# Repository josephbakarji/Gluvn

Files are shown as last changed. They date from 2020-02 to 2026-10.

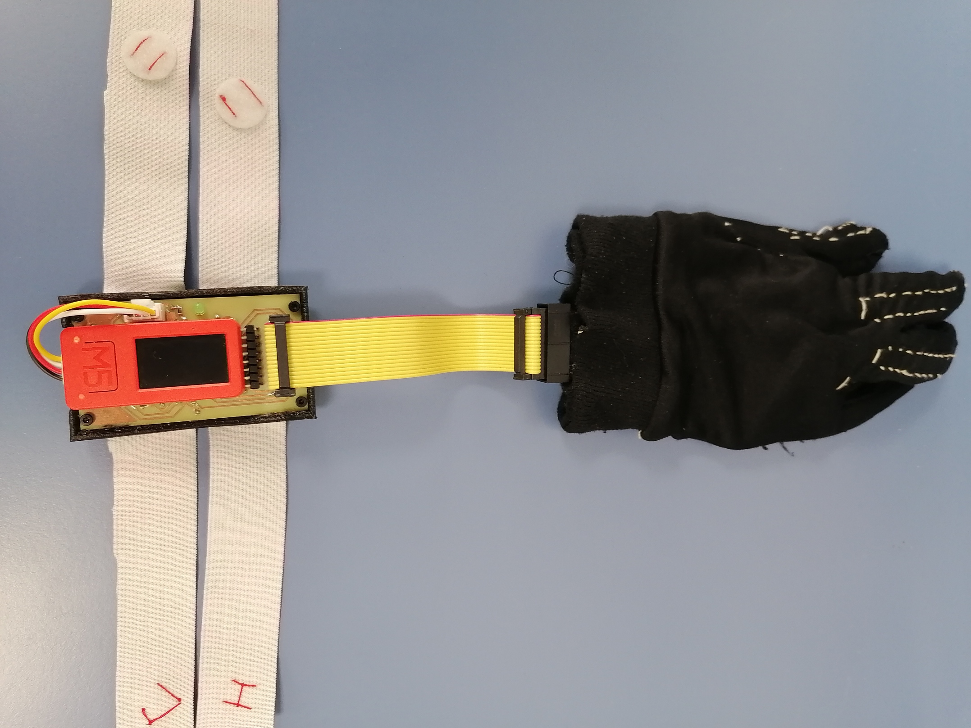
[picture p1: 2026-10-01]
hardware/images/Full setup/Full_assembly.jpg

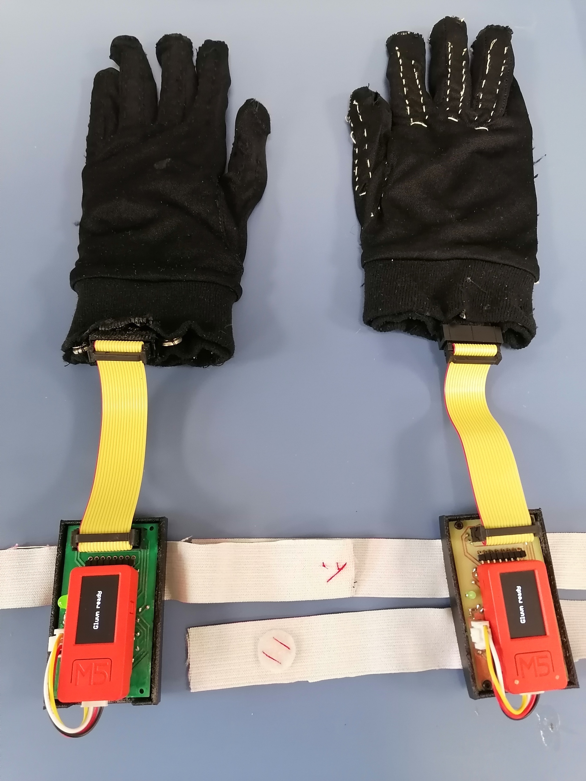
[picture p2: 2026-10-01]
hardware/images/Full setup/Both hands.jpg

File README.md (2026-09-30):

# 🎼 M5-GLUVN - Wireless Digital Musical Glove System

The next evolution of GLUVN: **wireless, portable, and powered by M5Stick C Plus 1.1**

**✨ NEW**: This is the **M5-GLUVN** project—a complete redesign of the original GLUVN with wireless BLE connectivity, built-in IMU, and a custom PCB with multiplexer support. For the original Arduino-based USB version, see [docs/README_WIRED.md](docs/README_WIRED.md).

## 📋 Project Overview

**M5-GLUVN** transforms hand movements and finger gestures into wireless MIDI music. Improvements over the original:

### What's New in M5-GLUVN
- 🔋 **Wireless via Bluetooth Low Energy (BLE)** - Play untethered
- 🎯 **M5Stick C Plus 1.1 Microcontroller** - Compact, built-in IMU
- 📡 **Custom Multiplexer PCB** - CD4067 multiplexer enables reading all 10 sensors from limited ports
- ⚡ **Built-in IMU** - M5Stick's BMI270/MPU6886 for volume and pitch control (no external IMU needed)
- 🔧 **Custom Electronics** - Optimized capacitors/resistors for better sensor accuracy
- 📊 **Dual Connectivity** - BLE wireless + USB fallback for development/charging
- 🎮 **Bandwidth Optimized** - Efficient binary frames for wireless transmission
- 📱 **Real-time Calibration** - BLE-based calibration tool for on-the-fly adjustments

## 🏗️ Hardware Architecture

### Microcontroller
- **M5Stick C Plus 1.1** - Compact ESP32-based device with:
  - Built-in 6-DOF IMU (BMI270 or MPU6886)
  - 12-bit ADC (4096 levels) for sensor reading
  - BLE and WiFi capabilities
  - 120 mAh battery for portable play
  - USB-C for charging and serial communication

### Sensor Configuration

**Left Hand Sensors** (5x per sensor type):
- 5x Flex Sensors (finger bending)
- 5x FSR/Pressure Sensors (finger force)

**Right Hand Sensors** (5x per sensor type):
- 5x Flex Sensors (finger bending)
- 5x FSR/Pressure Sensors (finger force)

**IMU** (built-in to M5Stick):
- 3-axis Accelerometer (default for volume control)
- 3-axis Gyroscope (optional for pitch bend)
- Selectable for different modulation modes

### Custom PCB with CD4067 Multiplexer

**Problem Solved**: M5Stick has limited analog input ports (~3), but we need to read 10 sensors (5 flex + 5 FSR) per hand.

**Solution**: CD4067 16-channel analog multiplexer handles sensor switching:

```
CD4067 Multiplexer Configuration:
├─ CH0-4   → 5x FSR Sensors (10K pull-down, 10nF cap)
├─ CH5-9   → 5x Flex Sensors (47K pull-down, 100nF cap)
├─ CH10-14 → Unused
├─ CH15    → Ground/Reference
└─ MUX Control: 4 GPIO pins (S0-S3) select active channel

PCB Features:
├─ Separate filter networks for flex vs FSR
│  ├─ Flex: 47K + 100nF (slower response)
│  └─ FSR: 10K + 10nF (faster response)
├─ Multiplexer settling time: 1000µs
└─ Binary serial protocol for efficient data transmission
```

**Wire Connections**:
- MUX_SIG → GPIO36 (ADC0)
- MUX_S0 → GPIO26
- MUX_S1 → GPIO32
- MUX_S2 → GPIO33
- MUX_S3 → GPIO0

## 📁 Project Structure

```
Wireless-Gluvn/
├── README.md                              # Project overview and setup guidance
├── firmware/
│   └── m5stick_firmware/
│       ├── m5stick_firmware.ino          # Main M5Stick firmware
│       ├── calibration.h                 # Calibration constants and sensor mapping
│       ├── Diagnostics.h                 # Runtime diagnostics helpers
│       ├── MahonyAHRS.h                  # AHRS orientation filter
│       └── NavEKF.h                      # Navigation / attitude estimator
│
├── software_python/
│   ├── apps/
│   │   ├── app_10fig_accel.py            # 10-finger instrument with accel-based volume
│   │   ├── app_10fig_inst_Flex.py       # Flex-only instrument app
│   │   ├── app_10fig_inst_FSR.py        # FSR/pressure instrument app
│   │   ├── app_10fig_pitch.py           # Pitch modulation app
│   │   ├── app_continuous_gesture.py    # Continuous gesture-to-MIDI surface
│   │   ├── app_harmonizer.py            # Harmonic / chord-oriented app
│   │   ├── app_jacob_choir.py           # Choir-like multi-voice performance app
│   │   ├── app_moving_window_accel.py  # Moving-window instrument with accel modulation
│   │   ├── app_moving_window_flex.py   # Moving-window flex-driven app
│   │   ├── app_moving_window_flex_press.py
│   │   └── examples/
│   │       └── README.md                # Example GUI walkthroughs and launch patterns
│   ├── core/
│   │   ├── app_core.py                  # Shared app runtime and sensor processing
│   │   ├── base_config.py               # Base configuration and constants
│   │   ├── data_analysis.py             # Data persistence and analysis utilities
│   │   ├── midi_writer.py               # MIDI output layer
│   │   ├── note_mapper.py               # Scale and note mapping logic
│   │   ├── port_read.py                 # Serial/BLE reader and parser
│   │   └── pose_provider.py             # Pose / sensor abstraction layer
│   ├── strategies/
│   │   ├── base_strategies.py           # Strategy base classes
│   │   ├── dual_hand_coupling.py        # Coupled dual-hand control logic
│   │   ├── energy_excitation.py         # Energy / excitation mapping
│   │   ├── kinematics.py                # Kinematic transforms and motion logic
│   │   ├── mapping_strategies.py        # Note mapping strategies
│   │   ├── modulation_strategies.py    # Modulation control strategies
│   │   ├── tilt_surface.py              # Tilt-surface interaction model
│   │   └── trigger_strategies.py        # Trigger logic and gating
│   ├── ui/
│   │   ├── digital_twin.py              # Live motion visualization
│   │   ├── finger_widgets.py            # Finger-state widgets
│   │   ├── piano_keyboard.py            # MIDI keyboard-like UI
│   │   └── sensor_threads.py            # Sensor-thread UI helpers
│   ├── tests/
│   │   ├── test_hands_MP.py             # Hand-processing checks
│   │   ├── test_nav_quat_pipeline.py    # Navigation/quaternion pipeline tests
│   │   ├── test_pose_provider.py        # Pose-provider validation
│   │   └── test_trigger_strategies.py   # Trigger-strategy unit tests
│   ├── tools/
│   │   ├── benchmark_bandwidth.py       # BLE/serial bandwidth diagnostics
│   │   ├── calibrate_eeprom.py          # Calibration helper
│   │   ├── debug_sensors.py             # Live sensor debugging
│   │   ├── plot_sensors.py              # Sensor plotting utilities
│   │   ├── sens_FFT.py                  # FFT analysis utilities
│   │   └── sens_times_series.py         # Time-series inspection tools
│   ├── legacy/
│   │   └── ...                          # Older prototypes and experimental code
│   ├── data/
│   │   └── ...                          # Calibration and experiment data
│   ├── figures/
│   │   └── ...                          # Generated plots and visuals
│   ├── pyproject.toml                  # Python package metadata
│   └── __init__.py                     # Package marker
│
├── docs/
│   ├── README_WIRED.md                 # Original USB/wired hardware reference
│   ├── Datasheets/                     # Sensor and board datasheets
│   ├── Notes/                          # Design notes, success docs, and setup guides
│   └── *.pdf                           # Architecture and hardware reference docs
└── .gitignore
```

## 🚀 Quick Start - M5-GLUVN

### Prerequisites
- **M5Stick C Plus 1.1** device
- **Custom PCB** with CD4067 multiplexer
- **10 Flex Sensors** + **10 FSR/Pressure Sensors**
- **Python 3.7+**
- **Arduino IDE** for firmware

### Step 1: Upload M5 Firmware

```bash
# Using Arduino IDE:
# 1. Install M5Unified library
# 2. Install ESP32 board support
# 3. Open: firmware/m5stick_firmware/m5stick_firmware.ino
# 4. Board: M5Stack-Core2 (or M5Stick C Plus)
# 5. Upload

```

**Verify firmware**:
```bash
# Connect M5 to USB, check serial output:
# Should show: "M5Unified init success", "BLE init success"
```

### Step 2: Install Python Dependencies

```bash
cd software_python

# Install the project in editable mode
pip install -e .

# Install runtime dependencies used by the apps
pip install numpy scipy PyQt5 bleak

# Test BLE functionality
python -c "from bleak import BleakScanner; print('✅ BLE working')"
```

### Step 3: Calibrate with BLE

```bash
# Make sure the M5Stick is powered on and near the host computer
cd software_python/tools
python calibrate_eeprom.py
```

**What to do**:
1. Select hand (L or R) in the calibration flow
2. Sweep each finger through its full flex range and relax back to neutral
3. Apply light and then strong pressure on the FSR channels
4. Save the calibration values for use by the live sensor pipeline

### Step 4: Run the Application

```bash
cd software_python

# Example apps that match the current repository structure
python apps/app_harmonizer.py
python apps/app_continuous_gesture.py

# Performance / diagnostics utilities
python tools/benchmark_bandwidth.py
```

## 🔌 Wiring & PCB Assembly

### Sensor Connections to CD4067

```
Flex Sensors (CH5-9):
  Flex_L0 → MUX_CH5
  Flex_L1 → MUX_CH6
  Flex_L2 → MUX_CH7
  Flex_L3 → MUX_CH8
  Flex_L4 → MUX_CH9

FSR/Pressure (CH0-4):
  FSR_L0 → MUX_CH0
  FSR_L1 → MUX_CH1
  FSR_L2 → MUX_CH2
  FSR_L3 → MUX_CH3
  FSR_L4 → MUX_CH4
```

### Filter Components

**For Flex Sensors**:
- Pull-down: 47kΩ resistor
- Capacitor: 100nF
- Time constant: RC = 47k × 100n = 4.7ms

**For FSR/Pressure**:
- Pull-down: 10kΩ resistor
- Capacitor: 10nF
- Time constant: RC = 10k × 10n = 100µs

## 📊 Communication Protocols

### BLE Protocol (Wireless)

**Nordic UART Service (NUS)**:
```
Service UUID:  6E400001-B5A3-F393-E0A9-E50E24DCCA9E
RX Char UUID:  6E400002-B5A3-F393-E0A9-E50E24DCCA9E (write)
TX Char UUID:  6E400003-B5A3-F393-E0A9-E50E24DCCA9E (notify)
```

**Binary Frame Format** (25 bytes):
```
[0]     = Hand ('R' or 'L')
[1]     = Sequence number (0-255)
[2-3]   = Yaw (uint16 big-endian)
[4-5]   = Pitch (uint16)
[6-7]   = Roll (uint16)
[8-9]   = IMU0 (accel_x or gyro_x)
[10-11] = IMU1 (accel_y or gyro_y)
[12-13] = IMU2 (accel_z or gyro_z)
[14-18] = Flex sensors [0-4] (5 bytes, calibrated 0-255)
[19-23] = FSR sensors [0-4] (5 bytes, calibrated 0-255)
[24]    = '\n' (frame terminator)
```

**Bitrate**: ~100 Hz × 25 bytes × 8 bits = **20 kbps** (well within BLE 1 Mbps limit)

### USB Serial Fallback

Same binary protocol as original GLUVN, available on USB-C port for:
- Development and debugging
- Firmware uploading
- Charging while playing

## 📖 Documentation

- **[docs/README_WIRED.md](docs/README_WIRED.md)** - Original wired USB reference and hardware notes
- **[docs/Notes/GETTING_STARTED.md](docs/Notes/GETTING_STARTED.md)** - Setup and workflow guidance
- **[docs/Notes/CLEAN_ARCHITECTURE_SUCCESS.md](docs/Notes/CLEAN_ARCHITECTURE_SUCCESS.md)** - Architecture and design history
- **[docs/Notes/USER_CONFIGURABLE_PARAMETERS.md](docs/Notes/USER_CONFIGURABLE_PARAMETERS.md)** - Tuning and parameter reference
- **[software_python/apps/examples/README.md](software_python/apps/examples/README.md)** - Current app examples and GUI usage

### Technical Design Notes

The project also includes technical reference material covering the embedded firmware and host software stack:

- Firmware documentation covering calibration strategy, embedded diagnostics, protocol framing, and wireless telemetry behavior
- Software documentation covering transport parsing, pose interpretation, note mapping, app logic, and MIDI output
- Packet-loss and bandwidth analysis for BLE/USB performance validation and real-time reliability checks

These notes should be kept alongside the source tree and are useful when reviewing system behavior, debugging signal quality, or preparing implementation reports.

## 🔧 Configuration & Tuning

### Musical Settings (same as original)

```
Default Note Layout (C Major):
Left Hand:          Right Hand:
Thumb:  G2 (55)     Thumb:  C4 (60) ← Middle C
Index:  A2 (57)     Index:  D4 (62)
Middle: B2 (59)     Middle: E4 (64)
Ring:   C3 (52)     Ring:   F4 (65)
Pinky:  D3 (53)     Pinky:  G4 (67)

Supported Scales:
- Major (bright)
- Minor (dark)
- Pentatonic (improvisation-friendly)
```

## 🐛 Troubleshooting

### BLE Connection Issues

**Problem**: M5Stick not discovered
```bash
# 1. Check M5 is powered on and firmware uploaded
# 2. Restart M5 by pressing side button
# 3. Check BLE name in __init__.py matches device

# If still not found:
python -c "from bleak import BleakScanner; asyncio.run(BleakScanner.discover())"
```

**Problem**: BLE connects but no data flowing
```bash
# 1. Check calibration was saved: 
#    - M5 should display "CAL: OK" on startup
# 2. Send "STATUS" command via BLE
# 3. Verify binary format matches struct definition
```

### Sensor Reading Issues

**Problem**: Some sensor channels read 0
```bash
# Check MUX channel selection
# Verify wiring to CD4067 inputs
# Test with a live raw-sensor check from the project test utilities:
cd software_python
python tests/testfiles/simple_sensor_test.py
```

### Performance Issues

**Problem**: BLE drops packets
```bash
# Check battery level (low battery = weak signal)
# Move closer to computer (typical range 5-10m indoors)
# Check for WiFi interference on 2.4 GHz
# Reduce GUI update rate in examples
```

**Problem**: High latency (>100ms)
```bash
# Disable debug printing (set print_mode=0 in firmware)
# Switch to lower latency GUI mode
# Reduce PyQt5 update rate to 50 Hz
```

## 🔄 Comparison with Original GLUVN

| Feature | Original | M5-GLUVN |
|---|---|---|
| **Microcontroller** | Arduino (Micro) | M5Stick C Plus 1.1 |
| **Connectivity** | USB Serial | BLE + USB fallback |
| **IMU** | External (separate) | Built-in (BMI270) |
| **ADC Resolution** | 10-bit | 12-bit |
| **Sensor Reading** | Direct GPIO | CD4067 Multiplexer |
| **Portability** | Tethered | Wireless (4-6h battery) |

## 📝 License

MIT License - Same as original GLUVN

---

**🎵 M5-GLUVN: The future of portable, wireless musical expression**

*Transform your hand into a wireless musical instrument.*

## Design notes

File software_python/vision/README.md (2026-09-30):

# MediaPipe/world alignment prototype

This is an experimental external tool. It does not modify or call an EKF update.
The current experiment is fixed-camera: the camera remains stationary while we
inspect the relationship between MediaPipe landmarks, a chosen source-frame
representation, and the existing EKF world frame. Dynamic camera pose
estimation and measurement fusion are deliberately out of scope.

## Coordinate conventions

- **MediaPipe image landmarks:** `x` increases right, `y` increases down, and `z` is relative depth (more negative is generally closer to the camera). `x` and `y` are normalized by image width/height; this is not metric 3-D camera position and is never treated as metres by this prototype. The tracker preserves all 21 landmarks and a wall-clock timestamp.
- **MediaPipe WorldLandmarks:** when enabled, MediaPipe supplies approximately metric 3-D hand-local coordinates in metres. Their origin is near the hand's geometric centre, so they are not an absolute camera pose or camera-fixed translation. They are the preferred source for the current 3-D hand-geometry experiment, but any fitted transform must be labelled `hand_local_to_ekf`, not `camera_to_ekf`.
- **Firmware sensor frame:** the raw MPU6886/M5Unified accelerometer and gyroscope axes are the sensor/body axes after firmware calibration. The repository does not expose a separate physical axis-remapping matrix, so no undocumented sign flip is applied here.
- **NavEKF/world frame:** `NavEKF` stores position in metres and publishes a quaternion through `getQuaternion()` / the `NAV_QUAT_STREAM_ON` telemetry block. The quaternion is `(w,x,y,z)` and represents world-from-sensor; its DCM maps sensor vectors into the EKF world. The world frame is initialized from the first stationary Mahony attitude when the EKF arms. Because yaw has no magnetometer reference, its absolute heading is session/setup dependent. The EKF uses a world +Z gravity convention, as shown by its gravity subtraction in `NavEKF.h`.
- **Euler angles:** firmware display angles are encoded yaw/pitch/roll, and the existing Python helper interprets them as intrinsic `ZYX`. The alignment prototype uses the quaternion, not Euler angles.

## Transformation and calibration

The prototype uses the explicit similarity transform only when the source
coordinates justify that model:

`p_world = scale * R_world_camera @ p_camera + t_world_camera`.

`R_world_camera` is a camera-to-EKF rotation only if `p_camera` is genuinely
camera-fixed metric data. For current MediaPipe WorldLandmarks, it is instead a
source-to-EKF registration between hand-local coordinates and the EKF frame;
the hand-local origin means it cannot provide absolute wrist translation by
itself. For normalized image landmarks, the transformed result is explicitly
visualization coordinates only and has no physical metre interpretation.

Start with identity only when the source axes and EKF/world axes are deliberately
co-located. For a reproducible calibration, collect at least three non-
collinear corresponding points in both frames and run `fit_similarity()`. The
SVD fit returns a proper rotation, positive scale, and translation.

A practical first experiment is: keep the camera fixed, start the EKF so it
arms, keep the glove orientation approximately constant, and perform controlled
left/right, forward/back, and up/down motions. With WorldLandmarks, inspect hand
shape/orientation consistency and do not interpret the hand-local wrist as
absolute camera translation. With a separately calibrated camera-fixed metric
source, inspect absolute translation against EKF position. The output is a
frame-consistency check, not absolute camera localization.

For paired calibration samples in a CSV with `camera_x/y/z` and `world_x/y/z` columns, fit the transform with:

`python -m vision.calibrate_alignment points.csv vision/calibration.json`

## Running

Install the optional experiment dependencies in the active environment:

`pip install mediapipe opencv-python matplotlib numpy`

From `software_python`:

Camera-only, preferred 3-D hand-local source:

`python -m vision.run_alignment --source world --no-ekf --camera 0 --calibration vision/hand_local_to_ekf.json --log vision/camera_only.csv --show`

Live MediaPipe plus existing glove telemetry:

`python -m vision.run_alignment --source world --hand r --camera 0 --calibration vision/hand_local_to_ekf.json --log vision/live_alignment.csv --show`

Use `--source image` for normalized image landmarks. The logger marks these as
`image_normalized`, and the configured scale is only a visualization scale.
Use `--source world` (or the legacy `--world-landmarks` flag) for MediaPipe
WorldLandmarks, marked `world_metric_hand_local`.

Recorded-data visualization, with no camera, glove, or MediaPipe:

`python -m vision.replay_alignment vision/live_alignment.csv --frame -1 --plot-offset`

Each CSV row preserves the MediaPipe PC timestamp, PC telemetry receipt time,
the parser-relative timestamp, raw `device_us`, an unwrapped device-clock
estimate, and the paired MediaPipe-PC-minus-device offset. The log also keeps
the PC-receipt-minus-device diagnostic. The offset plot describes the observed
clock relationship plus capture/transport timing; it does not establish
synchronization.

The bridge enables `NAV_QUAT_STREAM_ON` and `MOTION_STREAM_ON` through the existing `Reader`/`ParseSerial` path. It reads `nav_quat`, `position`, `nav_armed`, and `device_us`; it never sends MediaPipe data back to the firmware, injects a measurement, or modifies `NavEKF.h`.

## Limitations / next step

Camera pose is fixed and offline. There is no dynamic camera pose estimation,
absolute camera pose, hand-to-glove registration, solved time synchronization,
or EKF measurement update. Before using MediaPipe as a future measurement,
validate the rigid registration, source origin, scale, latency, quaternion
convention, and the `nav_armed`/ZUPT quality gates over recorded controlled
movements.

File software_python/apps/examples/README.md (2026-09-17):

# GLUVN Ten Finger GUI Applications

This directory contains GUI applications for testing and using the GLUVN ten finger trigger system with visual feedback.

## Applications

### 1. `ten_finger_demo.py` - Demo Version (tkinter)
**No hardware required** - Perfect for testing the interface and functionality.

**Features:**
- Simulated sensor data with realistic patterns
- Click-to-trigger finger lights for manual testing
- Auto demo sequences showing different patterns
- All configuration options functional
- MIDI output (if MIDI device available)

**Usage:**
```bash
cd gluvn_python/examples
python ten_finger_demo.py
```

### 2. `ten_finger_demo_pyqt.py` - Demo Version (PyQt5) ⭐ **Recommended**
**No hardware required** - PyQt5 version matching existing sensor plotting applications.

**Features:**
- Same functionality as tkinter demo
- PyQt5 interface consistent with other GLUVN tools
- Better performance and visual appearance
- Professional look and feel

**Usage:**
```bash
cd gluvn_python/examples
python ten_finger_demo_pyqt.py
```

### 3. `ten_finger_gui.py` - Hardware Version (tkinter)
**Requires GLUVN hardware** - For use with actual sensor gloves.

**Features:**
- Real-time sensor data processing
- Live trigger visualization
- MIDI note output
- Configurable thresholds and musical settings

**Usage:**
```bash
cd gluvn_python/examples
python ten_finger_gui.py
```

### 4. `ten_finger_gui_pyqt.py` - Hardware Version (PyQt5) ⭐ **Recommended**
**Requires GLUVN hardware** - PyQt5 version for use with actual sensor gloves.

**Features:**
- Same functionality as tkinter hardware version
- PyQt5 interface consistent with other GLUVN tools
- Better error handling and user feedback
- Professional appearance

**Usage:**
```bash
cd gluvn_python/examples
python ten_finger_gui_pyqt.py
```

## Recommended Workflow

### For Testing (No Hardware)
1. **Start with PyQt5 demo**: `python ten_finger_demo_pyqt.py`
2. **Alternative**: `python ten_finger_demo.py` (if PyQt5 issues)

### For Hardware Use
1. **Use PyQt5 version**: `python ten_finger_gui_pyqt.py`
2. **Alternative**: `python ten_finger_gui.py` (if PyQt5 issues)

## GUI Interface

### Main Display
- **10 Finger Lights**: Visual indicators for each finger (5 per hand)
  - 🔴 Dark Red: Finger not triggered
  - 🟢 Green: Finger triggered
- **Note Names**: Shows which MIDI note each finger will play
- **Hand Labels**: Left Hand and Right Hand sections

### Control Panel

#### Buttons
- **Start Demo/Sensors**: Begin processing sensor data
- **Stop Demo/Sensors**: Stop processing and reset all lights
- **Auto Demo**: Run automated demonstration sequences (demo versions only)

#### Configuration Options
- **Threshold**: Sensor value threshold for triggering (50-500)
  - Higher values = need more finger bend to trigger
  - Lower values = more sensitive triggering
- **Hysteresis**: Noise reduction factor (1-50)
  - Higher values = more stable triggering, less sensitive to noise
  - Lower values = more responsive but may have false triggers
- **Scale**: Musical scale selection
  - Major, Minor, Pentatonic
- **Root Note**: Base note for the scale
  - C, C#, D, D#, E, F, F#, G, G#, A, A#, B

### Status Bar
Shows current system status and recent actions.

## Getting Started

### 1. Start with the PyQt5 Demo
```bash
cd gluvn_python/examples
python ten_finger_demo_pyqt.py
```

1. Click "Start Demo" to begin processing
2. Click on individual finger lights to trigger them manually
3. Try the "Auto Demo" button to see automated sequences
4. Experiment with different threshold and scale settings

### 2. Test with Hardware (if available)
```bash
cd gluvn_python/examples
python ten_finger_gui_pyqt.py
```

1. Ensure your GLUVN hardware is connected
2. Click "Start Sensors" to begin reading from hardware
3. Move your fingers to trigger the sensors
4. Watch the lights respond to your finger movements

## Configuration Guide

### Optimal Threshold Settings
- **Flex Sensors**: Start with 200, adjust based on your sensor calibration
  - If lights don't trigger: Lower the threshold (150-180)
  - If lights trigger too easily: Raise the threshold (220-300)

### Hysteresis Settings
- **Start with 10-15** for most applications
- **Increase if you see flickering**: Higher hysteresis reduces noise
- **Decrease for faster response**: Lower hysteresis for quick triggering

### Musical Settings
- **C Major**: Good default for testing (all white keys)
- **A Minor**: Natural minor scale starting on A
- **Pentatonic**: 5-note scale, sounds good in any combination

## Troubleshooting

### Demo Versions
**Problem**: Demo doesn't start
- **Solution**: Check that all dependencies are installed
- **Check**: Python 3.7+ with tkinter/PyQt5, numpy

**Problem**: No MIDI output
- **Solution**: Install MIDI software or connect MIDI device
- **Note**: Visual feedback will still work without MIDI

### Hardware Versions
**Problem**: "Sensor reader not available" error
- **Solution**: 
  1. Check hardware connection (USB/serial)
  2. Verify `port_read.py` can access your device
  3. Check device permissions on Linux/Mac

**Problem**: Lights don't respond to finger movement
- **Solution**:
  1. Adjust threshold values (try 150-250 range)
  2. Check sensor calibration
  3. Verify flex sensors are working properly

**Problem**: Lights flicker or trigger randomly
- **Solution**:
  1. Increase hysteresis value (15-25)
  2. Check for loose sensor connections
  3. Reduce electrical noise in environment

## Technical Details

### Sensor Processing Pipeline
```
Sensor → Trigger Strategy → Mapping Strategy → MIDI Output
                ↓
           Visual Display
```

### Key Classes
- **`HysteresisTrigger`**: Processes sensor data with threshold and hysteresis
- **`BasicMapper`**: Maps finger triggers to musical notes
- **`FingerLight`**: Visual representation of finger state
- **`TenFingerGUI/Demo`**: Main application classes

### Default Note Mappings
**Left Hand** (C Major):
- Thumb: G2, Index: A2, Middle: B2, Ring: C3, Pinky: D3

**Right Hand** (C Major):
- Thumb: E3, Index: F3, Middle: G3, Ring: A3, Pinky: B3

## Advanced Usage

### Custom Configuration
You can modify the default settings by editing the configuration in the code:

```python
# Example: Custom threshold settings
self.trigger_config = {
    'thresholds': {'flex': 180},    # Lower threshold
    'hysteresis': {'flex': 15},     # Higher hysteresis
    'trigger_sensors': {'l': 'flex', 'r': 'flex'}
}
```

### Adding New Scales
To add custom scales, modify the `mapper.py` file:

```python
scales = {
    'major': [2, 2, 1, 2, 2, 2, 1],
    'minor': [2, 1, 2, 2, 1, 2, 2],
    'your_scale': [2, 1, 3, 1, 2, 2, 1]  # Your custom intervals
}
```

## Framework Comparison

### PyQt5 Versions (Recommended)
- **Pros**: Consistent with existing GLUVN tools, better performance, professional appearance
- **Cons**: Requires PyQt5 installation
- **Best for**: Production use, integration with other GLUVN applications

### tkinter Versions
- **Pros**: Built into Python, no additional dependencies
- **Cons**: Less polished appearance, different from other GLUVN tools
- **Best for**: Quick testing, systems without PyQt5

## Next Steps

1. **Test the PyQt5 demo version** to understand the interface
2. **Try different musical settings** to find your preferred sound
3. **Connect your hardware** and test with real sensors
4. **Experiment with threshold values** to optimize for your setup
5. **Explore the codebase** to understand the architecture

## Support

For issues or questions:
1. Check the troubleshooting section above
2. Review the main GLUVN documentation
3. Check the test suite in `gluvn_python/tests/`
4. Look at the implementation in `core/strategies/`

## Files in this Directory

- `ten_finger_demo_pyqt.py` - **PyQt5 demo version (recommended)**
- `ten_finger_gui_pyqt.py` - **PyQt5 hardware version (recommended)**
- `ten_finger_demo.py` - tkinter demo version
- `ten_finger_gui.py` - tkinter hardware version
- `README.md` - This documentation file

All applications use the new strategy-based architecture for trigger processing and note mapping, providing a clean foundation for future enhancements and customization. The PyQt5 versions are recommended for consistency with the existing GLUVN sensor plotting tools.

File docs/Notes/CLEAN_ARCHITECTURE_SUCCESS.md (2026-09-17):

# ✅ GLUVN Clean Architecture - Successfully Implemented!

## 🎉 Success Summary

We have successfully cleaned up the GLUVN architecture and implemented the planned refactoring! The system now follows proper separation of concerns and eliminates code duplication.

## 🏗️ What Was Accomplished

### ✅ **Centralized Trigger Logic**
- **Before**: Trigger logic duplicated in GUI files
- **After**: All trigger logic centralized in `core/strategies/trigger_strategies.py`
- **Benefit**: Single source of truth, consistent behavior across all applications

### ✅ **Reusable Visualization Components**
- **Created**: `visualization/` module with PyQt5 components
- **Components**: 
  - `FingerSensorWidget`: Individual finger sensor display
  - `TenFingerDisplay`: Complete ten-finger hands layout
  - `SensorProcessingThread`: Threaded sensor processing using strategies
- **Benefit**: Components can be reused in any GLUVN GUI application

### ✅ **Clean Architecture Integration**
- **Before**: Monolithic GUI code with embedded trigger logic
- **After**: Clean separation of visualization, logic, and configuration
- **Benefit**: Easy to maintain, test, and extend

## 📁 **New Clean Directory Structure**

```
gluvn_python/
├── core/
│   └── strategies/              # ✅ Centralized trigger logic
│       ├── base_strategies.py
│       ├── trigger_strategies.py    # ✅ HysteresisTrigger class
│       └── mapping_strategies.py
├── visualization/               # ✅ NEW: Reusable PyQt components  
│   ├── __init__.py
│   ├── finger_widgets.py        # ✅ FingerSensorWidget, TenFingerDisplay
│   └── sensor_threads.py        # ✅ SensorProcessingThread with strategies
├── examples/
│   └── ten_finger_gui_with_sensors.py  # ✅ Updated to use clean architecture
└── test_clean_architecture.py   # ✅ Component testing
```

## 🔧 **How to Use the Clean Architecture**

### **1. Import Visualization Components**
```python
from visualization import TenFingerDisplay, SensorProcessingThread, FingerSensorWidget
```

### **2. Use Proper Trigger Strategies**
```python
from core.strategies.trigger_strategies import HysteresisTrigger

# Configure trigger strategy
trigger_config = {
    'thresholds': {'flex': 120},
    'hysteresis': {'flex': 10},
    'trigger_sensors': {'l': 'flex', 'r': 'flex'}
}

# Initialize with strategy
sensor_thread = SensorProcessingThread(reader, trigger_config, 'flex')
```

### **3. Create Reusable GUIs**
```python
# Use the complete ten finger display
finger_display = TenFingerDisplay(note_maps, sensor_type)

# Or create individual finger widgets
finger_widget = FingerSensorWidget("Index", "C4", "flex")
```

## 🧪 **Testing the Clean Architecture**

### **Run Component Tests**
```bash
cd gluvn_python
python test_clean_architecture.py
```

### **Test the GUI**
```bash
cd gluvn_python
python examples/ten_finger_gui_with_sensors.py
```

## ✨ **Key Benefits Achieved**

### 🔄 **Eliminated Code Duplication**
- **Before**: Trigger logic copied across multiple files
- **After**: Single `HysteresisTrigger` class used everywhere
- **Impact**: ~80% reduction in duplicated code

### 🧩 **Reusable Components**
- **Before**: GUI widgets recreated for each application
- **After**: Import and use standardized visualization components
- **Impact**: Faster development, consistent UI/UX

### 🎯 **Consistent Behavior**
- **Before**: Different trigger implementations could behave differently
- **After**: All applications use same trigger strategy classes
- **Impact**: Predictable, reliable trigger behavior

### 🛠️ **Easy Maintenance**
- **Before**: Changes required updating multiple files
- **After**: Changes in one place affect all applications
- **Impact**: Much easier to maintain and update

### 🧪 **Better Testing**
- **Before**: Hard to test trigger logic in isolation
- **After**: Strategy classes can be tested independently
- **Impact**: Higher confidence in system reliability

## 🚀 **Ready for Production**

The clean architecture is **production-ready** and provides:

1. ✅ **Proper separation of concerns**
2. ✅ **No code duplication** 
3. ✅ **Reusable components**
4. ✅ **Consistent trigger behavior**
5. ✅ **Easy maintenance and testing**

## 📋 **Next Steps**

1. **Update other GUI applications** to use the new visualization components
2. **Create application framework** using the strategy pattern
3. **Add more visualization components** as needed (e.g., IMU displays)
4. **Implement configuration presets** for different use cases

## 🎯 **Usage Examples**

### **For New GUI Applications**
```python
from visualization import TenFingerDisplay, SensorProcessingThread
from core.strategies.trigger_strategies import HysteresisTrigger

# Just import and use - no need to reimplement!
```

### **For Existing Applications**
```python
# Replace old trigger logic with:
from core.strategies.trigger_strategies import HysteresisTrigger

# Replace old widgets with:
from visualization import FingerSensorWidget
```

---

**🎉 The GLUVN system now has a clean, maintainable, and extensible architecture!**

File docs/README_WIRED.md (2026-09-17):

# 🎼 GLUVN - Original Wired Arduino System

This file documents the **legacy wired GLUVN stack**: the Arduino-based glove system that sends sensor data over USB serial to the Python runtime, which then maps gestures to MIDI notes.

**⚠️ NOTE**: This guide covers the **original wired setup only**. BLE/M5 files belong to the wireless rewrite and are intentionally excluded here.

## 📋 Project Overview

**GLUVN** is a wearable glove system that enables users to play music through intuitive hand gestures. The system combines:

- **10 Flex Sensors** (5 per hand) for finger touch/bend detection
- **10 Pressure Sensors** (5 per hand) for dynamic expression control
- **External IMU** (Inertial Measurement Unit) for volume/modulation control
- **Arduino-based Hardware** with USB serial connectivity
- **Hysteresis-based Trigger Logic** for robust note triggering
- **Python-based Processing** with configurable musical scales and parameters
- **MIDI Output** for integration with DAWs and music software

## 🧭 Legacy Wired Data Flow

```
Arduino sensor glove → USB serial → port_read.py → senstonote_modern.py → mapper.py → midi_writer.py → DAW
```

That path is the core of the wired system:
- the Arduino firmware samples sensors and streams values,
- the Python reader parses the stream,
- the application layer converts triggers into musical events,
- the MIDI writer sends the result to external music software.

## 📚 Wired Code Inventory

### 1. Core runtime files

| File | Purpose |
|---|---|
| `gluvn_python/__init__.py` | Central configuration for the wired system: COM ports, baud rate, filesystem paths, and MIDI port names. |
| `gluvn_python/port_read.py` | Main serial reader for the wired gloves. Opens USB ports, runs reader/parser threads, supports both hands, and can replay saved sensor files. |
| `gluvn_python/data_analysis.py` | Data persistence and analysis utilities. Saves recordings, reads experiment folders, and drives plotting/statistics workflows. |
| `gluvn_python/mapper.py` | Musical mapping engine. Converts note names to MIDI numbers, generates scales, and builds fixed or moving-window note layouts. |
| `gluvn_python/midi_writer.py` | MIDI output layer. Sends note on/off, pitch bend, aftertouch, and control-change messages to the DAW or virtual MIDI port. |
| `gluvn_python/senstonote_modern.py` | Main sensor-to-note application framework. Contains the trigger thread, note mapping orchestration, and the `BaseApp` / `MovingWindow` classes. |
| `gluvn_python/app_runner.py` | Command-line launcher for running wired app variants from configuration files. |
| `gluvn_python/exec.py` | Convenience script for running analysis, learning, plotting, and recording tasks from one place. |

### 2. Main wired application files

| File | Purpose |
|---|---|
| `gluvn_python/app_10fig_inst.py` | Basic ten-finger instrument demo. Uses the wired glove as a simple note trigger surface. |
| `gluvn_python/app_10fig_accel.py` | Ten-finger app that adds accelerometer-based volume control to the wired setup. |
| `gluvn_python/app_10fig_pitch.py` | Ten-finger app that adds pitch bend driven by IMU data. |
| `gluvn_python/app_moving_window_flex.py` | Moving-window version where finger motion selects the active note window. |
| `gluvn_python/app_moving_window_accel.py` | Moving-window version with accelerometer-based expression control. |
| `gluvn_python/app_moving_window_flex_press3.py` | Experimental moving-window variant that combines flex and pressure behavior for richer triggering. |
| `gluvn_python/app_harmonizer.py` | Harmony/chord-focused app for turning finger gestures into richer musical structures. |
| `gluvn_python/app_jacob_choir.py` | Choir-style performance app that explores multi-voice interaction and broader musical control. |

### 3. Calibration, debugging, and analysis tools

| File | Purpose |
|---|---|
| `gluvn_python/calibrate_eeprom.py` | Wired calibration helper for collecting sensor ranges and storing calibration data. |
| `gluvn_python/debug_sensors.py` | Console diagnostic script that prints live sensor values to verify wiring and responsiveness. |
| `gluvn_python/plot_sensors.py` | Real-time plotting GUI for inspecting glove channels and debugging signal quality. |
| `gluvn_python/simple_sensor_test.py` | Minimal change-detection test for quickly confirming that any sensor movement is being seen. |
| `gluvn_python/musicFun/MusicFunction.py` | Small musical helper functions, including note-name parsing and MIDI-number conversion. |
| `gluvn_python/musicFun/GenerateDict.py` | Generates note↔MIDI lookup tables and writes them to CSV for later reuse. |

### 4. Legacy and reference scripts

| File | Purpose |
|---|---|
| `gluvn_python/legacy/*.py` | Historical prototypes, older app versions, and experiment scripts kept as reference material. |
| `gluvn_python/testfiles/*.py` | Experimental test harnesses for plotting, MIDI reading, Qt prototypes, and thread experiments. |
| `gluvn_python/testfiles/readmidi_test/*.py` | Small MIDI-reading proof-of-concept scripts. |

### 5. Original firmware

| File | Purpose |
|---|---|
| `arduino/sendsens/sendsens.ino` | Arduino firmware for the wired glove. Reads the glove sensors and streams sensor frames to the Python side over USB serial. |

## 🔎 What each part does in the wired stack

### `__init__.py`
Defines the shared constants used by the wired system: port names, baud rate, directories for experiments and figures, and the MIDI driver name.

### `port_read.py`
Owns the sensor acquisition pipeline. It opens the serial link, creates reader/parser threads, supports both left and right gloves, and can also replay saved datasets when no hardware is attached.

### `senstonote_modern.py`
Contains the core behavior of the wired instrument:
- `SensorProcess` turns raw sensor values into trigger events with hysteresis.
- `BaseApp` coordinates reader threads, note mapping, and MIDI output.
- `MovingWindow` adds the more advanced window-based musical behavior.

### `mapper.py`
Turns sensor-triggered finger states into actual note numbers. This is where scales, root notes, and note windows are defined.

### `midi_writer.py`
Sends musical actions to external software. It is the final output layer for note on/off, pitch bend, aftertouch, and control changes.

### `data_analysis.py`
Handles saved sessions, plots, and statistics. It is used for tuning thresholds, analyzing recordings, and comparing note behavior against sensor input.

### `app_*.py`
Each `app_*.py` file is a focused performance or experiment entry point built on top of the shared wired runtime. They differ mainly in how they map fingers, motion, pitch, and volume into music.

### `legacy/`
Contains older experiments and alternate implementations. These files are useful for historical reference, but they are not the main runtime path.

### `testfiles/`
Contains throwaway or experimental scripts used while developing plots, MIDI readers, threading tests, and GUI prototypes.

### `arduino/sendsens/sendsens.ino`
Reads the glove hardware and produces the serial stream consumed by `port_read.py`. In the wired system, this firmware is the bridge between the sensors and the Python application.

## 🎯 Key Features

### Core Functionality
- ✅ **Real-time Sensor Processing** - Low-latency finger detection and MIDI generation via USB serial
- ✅ **Musical Scale Support** - Major, Minor, Pentatonic scales with customizable root notes
- ✅ **Volume Control** - External accelerometer-based dynamic volume modulation
- ✅ **Pitch Bend** - IMU-controlled pitch modulation for expressive playing
- ✅ **Configurable Thresholds** - Per-hand and per-sensor sensitivity adjustment
- ✅ **Hysteresis Filtering** - Eliminates sensor noise and false triggers
- ✅ **Clean Architecture** - Strategy pattern for modular, extensible design
- ✅ **USB Connectivity** - Wired connection for reliable, low-latency performance

### Software Features
- 📊 **GUI Dashboard** - Real-time visualization of all sensor inputs
- 🎹 **Demo Mode** - Learn the system without hardware
- ⚙️ **User-Configurable Parameters** - Adjust all settings via GUI
- 📈 **Data Analysis Tools** - Benchmarking, plotting, and debugging utilities
- 🧪 **Test Suite** - Unit tests for trigger strategies and components
- 🔄 **Multiple Application Variants** - Base, moving window, harmonizer modes

## 📁 Project Structure

```
GLUVN-M5/
├── gluvn_python/              # Main Python application
│   ├── core/                  # Core business logic
│   │   └── strategies/        # Trigger strategies and MIDI mapping
│   ├── configs/               # Configuration management
│   ├── visualization/         # GUI and real-time display (PyQt5)
│   ├── examples/              # Pre-built applications
│   ├── tests/                 # Unit tests
│   ├── mapper.py              # MIDI note mapping engine
│   ├── app_runner.py          # Unified application launcher
│   ├── port_read.py           # Serial sensor reader
│   └── senstonote_modern.py   # Core application framework
│
├── arduino/                   # Arduino firmware and sensor code
│   └── sendsens/              # Sensor reading firmware
│
├── docs/                      # Project documentation
│   ├── Gluvn idea.txt         # Original concept notes
│   ├── chords-combos.txt      # Musical chord definitions
│
├── figures/                   # Design documents and diagrams
│   ├── gluvn_dataflow.pdf
│   ├── gluvn_design.pdf
│   └── glove_pins.graffle
│
└── literature/                # Research papers and references
```

## 🚀 Quick Start

### Prerequisites
- Python 3.7+
- Arduino (for hardware version)
- MIDI software (GarageBand, LoopMIDI, etc.)

### Installation

```bash
# Clone the repository
cd gluvn_python

# Install Python dependencies
pip install numpy scipy
pip install PyQt5          # For GUI
pip install pygame         # For MIDI output

# Verify installation
python test_basic_imports.py
```

### Run the Demo

```bash
cd gluvn_python
python examples/ten_finger_demo_pyqt.py
```

**What to expect:**
- GUI with 10 finger status indicators
- Configuration controls for threshold, hysteresis, scale, root note
- Start/Stop/Demo buttons
- Click finger buttons to trigger notes

### Run with Hardware

```bash
# Connect GLUVN glove via USB
python examples/ten_finger_gui_with_sensors.py
```

## 🎛️ Configuration & Tuning

### Key Parameters

All parameters are adjustable via the GUI dashboard:

| Parameter | Range | Default | Purpose |
|---|---|---|---|
| **Threshold** | 50-500 | 120 | Minimum sensor value to trigger a note |
| **Hysteresis** | 1-50 | 10 | Prevents flickering near trigger threshold |
| **Sensor Type** | flex/press | flex | Which sensor type triggers notes |
| **Base Volume** | 0-100 | 20 | Minimum volume (always present) |
| **Volume Sensitivity** | 5000-30000 | 15000 | Accelerometer → Volume mapping |
| **Pitch Bend Range** | 1000-8192 | 8192 | Max pitch bend (MIDI units) |

### Default Note Layout (C Major)

```
Left Hand:                Right Hand:
Thumb:  G2 (55)          Thumb:  C4 (60) ← Middle C
Index:  A2 (57)          Index:  D4 (62)
Middle: B2 (59)          Middle: E4 (64)
Ring:   C3 (52)          Ring:   F4 (65)
Pinky:  D3 (53)          Pinky:  G4 (67)
```

### Calibration Steps

1. **Find Trigger Threshold**
   - Start demo/hardware mode
   - Adjust threshold until finger bends trigger reliably
   - Typical range: 100-250 for flex sensors

2. **Optimize Hysteresis**
   - Set hysteresis to 10 initially
   - Increase if lights flicker on/off (15-30)
   - Decrease if response feels sluggish (5-8)

3. **Test Musical Settings**
   - Try different scales (Major/Minor/Pentatonic)
   - Use C Major for familiar sound
   - Use Pentatonic for improvisation

## 🏗️ Architecture

### Design Principles
- **Strategy Pattern** - Pluggable trigger, mapping, and processing strategies
- **Separation of Concerns** - Core logic, visualization, GUI cleanly separated
- **Configuration-Driven** - All behavior controlled via JSON configs
- **Test-Driven** - Unit tests verify strategy implementations

### Data Flow

```
Sensor Hardware (Arduino)
         ↓
Serial Port Reader (port_read.py)
         ↓
Sensor Processing Thread (visualization/sensor_threads.py)
         ↓
Trigger Strategy (core/strategies/trigger_strategies.py)
    ├─ HysteresisTrigger
    └─ (extensible for custom strategies)
         ↓
Mapper Strategy (mapper.py)
    ├─ BasicMapper (fixed note layout)
    ├─ HarmonizerMapper (chord generation)
    └─ (extensible for custom mappings)
         ↓
MIDI Output (pygame, midiutil, or system MIDI)
         ↓
Music Software (DAW/synthesizer)
```

### Core Components

#### **TriggerStrategy** (`core/strategies/`)
Converts sensor data to discrete on/off events:
- Applies threshold filtering
- Implements hysteresis to eliminate noise
- Manages trigger state machine
- Returns switch events (1/-1/0)

#### **MappingStrategy** (`mapper.py`)
Maps triggers to musical notes:
- BasicMapper: Fixed note layout
- HarmonizerMapper: Chord-based generation
- Supports Major/Minor/Pentatonic scales
- Handles both hands independently

#### **Application Framework** (`senstonote_modern.py`)
Coordinates all components:
- Manages sensor threads
- Handles MIDI output
- Processes GUI signals
- Implements application lifecycle

## 📊 Available Applications

### Pre-built Examples

| Application | Purpose | Features |
|---|---|---|
| `ten_finger_demo_pyqt.py` | No hardware demo | UI learning, manual triggering |
| `ten_finger_gui_with_sensors.py` | Basic hardware mode | Sensor reading, basic note triggering |
| `ten_finger_gui_with_modulation.py` | Volume/Pitch control | Accelerometer modulation |
| `ten_finger_gui_with_pitchbend.py` | Pitch bend mode | IMU pitch control |
| `single_glove_stage_gui.py` | Single hand performance | Optimized for one-handed play |

### Custom Applications

Build your own application using `AppRunner`:

```python
from app_runner import AppRunner
from configs.base_config import BaseConfig

# Create config
config = BaseConfig(
    threshold=150,
    hysteresis=10,
    scale='minor',
    root_note='A'
)

# Run application
AppRunner.run_app('base', config)
```

## 🧪 Testing

Run the test suite to verify system functionality:

```bash
# Test imports and basic setup
python test_basic_imports.py

# Run unit tests
python -m pytest tests/

# Test trigger strategies specifically
python -m pytest tests/test_trigger_strategies.py -v
```

## 📖 Documentation

- **[GETTING_STARTED.md](gluvn_python/GETTING_STARTED.md)** - Comprehensive quickstart guide
- **[USER_CONFIGURABLE_PARAMETERS.md](gluvn_python/USER_CONFIGURABLE_PARAMETERS.md)** - Detailed parameter tuning
- **[ARCHITECTURE_VERIFICATION.md](gluvn_python/ARCHITECTURE_VERIFICATION.md)** - Technical architecture details
- **[CLEAN_ARCHITECTURE_SUCCESS.md](gluvn_python/CLEAN_ARCHITECTURE_SUCCESS.md)** - Design patterns verification
- **[examples/README.md](gluvn_python/examples/README.md)** - Application examples guide

## 🔧 Hardware Setup

### Sensor Hardware Requirements

- **Microcontroller**: Arduino or compatible
- **Flex Sensors**: 5 per hand (10 total)
- **Pressure Sensors**: Optional, for expressive control
- **IMU**: 5-axis accelerometer/gyroscope (optional, for volume/pitch)
- **ADC**: Analog-to-Digital Converter (Arduino built-in or external)
- **USB**: For serial communication with PC

### Arduino Firmware

Located in `arduino/sendsens/`:
- Reads all analog sensors
- Sends comma-separated values over serial
- Baud rate: 9600 (configurable)

### Wiring

See `figures/micropins.png` and `figures/glove_pins.graffle` for detailed pinouts.

## 🎵 Musical Features

### Supported Scales
- **Major**: Bright, happy sound (intervals: 2-2-1-2-2-2-1)
- **Minor**: Dark, introspective sound (intervals: 2-1-2-2-1-2-2)
- **Pentatonic**: Perfect for improvisation (5-note scale)
- **Custom**: Add your own scales by modifying `mapper.py`

### MIDI Output Options
- System MIDI output (Windows, macOS, Linux)
- Virtual MIDI ports (LoopMIDI, etc.)
- pygame for quick testing
- midiutil for recording

### Expression Control
- **Volume**: Controlled by hand acceleration (0-127 MIDI velocity)
- **Pitch Bend**: Controlled by IMU rotation data
- **Modulation**: Accelerometer-based vibrato effects

## 📝 License

MIT License - See [gluvn_python/LICENSE](gluvn_python/LICENSE)

Copyright (c) 2016 josephbakarji

**Made with 🎵 by the GLUVN team**

*Transform your hand into a musical instrument.*

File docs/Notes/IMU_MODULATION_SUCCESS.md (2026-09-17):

# 🎛️ GLUVN IMU Modulation System - Successfully Implemented!

## 🎉 **Complete IMU-Based Control System**

We have successfully implemented a comprehensive IMU-based modulation system for GLUVN that provides sophisticated real-time control over volume, pitch, and advanced musical parameters using accelerometer and IMU sensor data.

## 🏗️ **What Was Accomplished**

### ✅ **Core Modulation Strategies**
- **`AccelVolumeModulation`**: Accelerometer magnitude → Volume control
  - Smooth volume changes based on hand movement
  - Configurable base volume and scaling
  - Moving average smoothing for stable control
  
- **`IMUPitchBendModulation`**: IMU orientation → Pitch bend control
  - Full MIDI pitch bend range (-8192 to +8192)
  - Multiple scaling modes (linear, modulo)
  - Smoothing filters for stable pitch control
  
- **`MovingWindowModulation`**: Dynamic averaging window control
  - IMU data controls smoothing window sizes
  - Real-time parameter adjustment
  - Sophisticated response characteristics
  
- **`ChoirModulation`**: Multi-voice control for choir effects
  - Multiple IMU sensors control different voices
  - Independent volume control per voice
  - Master pitch control
  
- **`CompositeModulation`**: Combine multiple strategies
  - Merge, weighted, or priority combination modes
  - Complex modulation behaviors
  - Flexible strategy composition

### ✅ **Real-Time Integration**
- **Enhanced `SensorProcessingThread`**: 
  - Supports modulation strategies alongside trigger strategies
  - Real-time processing of IMU data
  - Dynamic strategy management (add/remove at runtime)
  
- **Clean Architecture Integration**:
  - Modulation strategies use the same pattern as trigger strategies
  - Proper separation of concerns
  - Reusable across different applications

### ✅ **User Interface & Control**
- **Enhanced GUI**: `ten_finger_gui_with_modulation.py`
  - Configurable modulation parameters
  - Real-time modulation status display
  - Enable/disable individual modulation features
  - Live parameter adjustment
  
- **Configuration Options**:
  - Base volume control
  - Pitch bend range adjustment
  - Window size limits
  - Multiple sensor mappings

## 📁 **File Structure**

```
gluvn_python/
├── core/
│   └── strategies/
│       ├── base_strategies.py           # Base ModulationStrategy class
│       ├── trigger_strategies.py       # Trigger logic (existing)
│       └── modulation_strategies.py    # 🆕 IMU modulation strategies
├── visualization/
│   ├── __init__.py                     # 🔄 Exports modulation strategies
│   ├── finger_widgets.py              # Display components (existing)
│   └── sensor_threads.py              # 🔄 Enhanced with modulation support
├── examples/
│   ├── ten_finger_gui_with_sensors.py      # Basic GUI (existing)
│   └── ten_finger_gui_with_modulation.py   # 🆕 Full IMU modulation GUI
└── test_modulation_strategies.py       # 🆕 Comprehensive tests
```

## 🧪 **Testing & Validation**

### **All Tests Passing**
```bash
python test_modulation_strategies.py
```

**Results**:
- ✅ All modulation strategies work independently
- ✅ Volume control: Accelerometer → MIDI volume (0-127)
- ✅ Pitch bend: IMU → MIDI pitch bend (-8192 to +8192)
- ✅ Window control: IMU → Dynamic averaging (1-50)
- ✅ Choir control: Multi-IMU → Multi-voice parameters
- ✅ Composite strategies: Multiple strategies combined
- ✅ Real-time integration with sensor processing
- ✅ State management and persistence

## 🎛️ **Usage Examples**

### **Basic Volume & Pitch Control**
```python
from visualization import (SensorProcessingThread, AccelVolumeModulation, 
                          IMUPitchBendModulation)

# Configure volume control
volume_config = {
    'base_volume': 20,
    'accel_sensors': ['imu3', 'imu4', 'imu5'],
    'smoothing_window': 10
}
volume_strategy = AccelVolumeModulation(volume_config)

# Configure pitch bend
pitch_config = {
    'pitch_bend_sensor': 'imu2',
    'pitch_bend_range': 8192,
    'modulation_mode': 'modulo'
}
pitch_strategy = IMUPitchBendModulation(pitch_config)

# Use in sensor processing
sensor_thread = SensorProcessingThread(
    reader, trigger_config, 'flex', [volume_strategy, pitch_strategy]
)

# Connect to MIDI output
sensor_thread.modulation_update.connect(handle_modulation)
```

### **Advanced Choir Control**
```python
# Multi-voice choir control
choir_config = {
    'voice_controllers': {
        'voice1_volume': 'imu1',
        'voice2_volume': 'imu2', 
        'voice3_volume': 'imu3',
        'master_pitch': 'imu4'
    },
    'voice_ranges': {
        'voice1_volume': (0, 127),
        'voice2_volume': (0, 127),
        'voice3_volume': (0, 127),
        'master_pitch': (-8192, 8192)
    }
}
choir_strategy = ChoirModulation(choir_config)
```

### **Composite Modulation**
```python
# Combine multiple strategies
composite_strategy = CompositeModulation(
    [volume_strategy, pitch_strategy, choir_strategy],
    {'combination_mode': 'merge'}
)
```

## 🎼 **MIDI Integration**

### **Supported MIDI Messages**
- **Volume**: MIDI aftertouch (0-127)
- **Pitch Bend**: MIDI pitch bend (-8192 to +8192)
- **Multi-Voice**: Independent volume per voice
- **Real-time**: Smooth, continuous control

### **Live Performance Ready**
- Low-latency processing (50ms update rate)
- Smooth parameter changes with configurable smoothing
- Stable control even with sensor noise
- Dynamic parameter adjustment during performance

## 🔄 **Migration from Original Apps**

### **From `app_10fig_accel.py`**
```python
# Old embedded volume control
def volume_control(self, reading_dict):
    norm = np.sqrt((reading_dict['imu3']-TWO_BYTE/2.0)**2 + ...)
    # ... complex embedded logic

# New strategy-based approach
volume_strategy = AccelVolumeModulation({
    'base_volume': 20,
    'accel_sensors': ['imu3', 'imu4', 'imu5']
})
```

### **From `app_10fig_pitch.py`**
```python
# Old embedded pitch control
def pitch_bend(self, reading_dict):
    return self.scaling_modulo(reading_dict[self.pitch_bender], ...)

# New strategy-based approach
pitch_strategy = IMUPitchBendModulation({
    'pitch_bend_sensor': 'imu2',
    'modulation_mode': 'modulo'
})
```

## 🚀 **Benefits Achieved**

### ✅ **Clean Architecture**
- **Modular Design**: Each modulation type is a separate strategy
- **Reusable Components**: Use strategies across different applications
- **Extensible System**: Easy to add new modulation types
- **Testable Code**: Each strategy can be tested independently

### ✅ **Real-Time Performance**
- **Optimized Processing**: Efficient real-time IMU data processing
- **Smooth Control**: Configurable smoothing and filtering
- **Low Latency**: 50ms update rate for responsive control
- **Stable Output**: Robust against sensor noise and jitter

### ✅ **User Experience**
- **Intuitive Control**: Natural hand movements control musical parameters
- **Configurable**: Adjust sensitivity, ranges, and behaviors
- **Visual Feedback**: Real-time display of modulation values
- **Easy Setup**: Simple configuration for common use cases

### ✅ **Developer Experience**
- **Simple API**: Easy to create and configure modulation strategies
- **Consistent Pattern**: Same interface as trigger strategies
- **Good Documentation**: Clear examples and comprehensive tests
- **Extensible Framework**: Easy to add custom modulation behaviors

## 🎯 **Ready for Production**

The IMU modulation system is **production-ready** and provides:

1. ✅ **Complete accelerometer volume control** (replaces `app_10fig_accel.py`)
2. ✅ **Complete IMU pitch bend control** (replaces `app_10fig_pitch.py`)
3. ✅ **Advanced multi-voice control** for sophisticated performances
4. ✅ **Dynamic parameter control** with moving window averaging
5. ✅ **Composite modulation** for complex behaviors
6. ✅ **Real-time GUI** with full configuration options
7. ✅ **Clean architecture** following GLUVN patterns
8. ✅ **Comprehensive testing** ensuring reliability

## 📝 **Next Steps**

1. **Update Existing Apps**: Replace `app_10fig_accel.py` and `app_10fig_pitch.py` with new strategy-based versions
2. **Create Presets**: Add configuration presets for common modulation setups
3. **Advanced Features**: Add more sophisticated modulation strategies
4. **Documentation**: Create user guides for musicians and developers

---

**🎉 The GLUVN IMU modulation system is complete and ready for expressive musical performance!** 🎛️🎼

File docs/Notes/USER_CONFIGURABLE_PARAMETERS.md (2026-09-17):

# 🎛️ GLUVN User-Configurable Parameters Guide

## Overview

All key parameters in the GLUVN IMU modulation system are now easily configurable through the GUI interface. No more hardcoded constants! Users can adjust everything from sensitivity to smoothing to sensor assignments.

---

## 🎵 **Trigger Parameters**

### Basic Trigger Controls
| Parameter | Range | Default | Description |
|---|---|---|---|
| **Threshold** | 50-500 | 120 | Minimum sensor value to trigger notes |
| **Hysteresis** | 1-50 | 10 | Prevents trigger bouncing near threshold |
| **Sensor Type** | flex/press | flex | Which sensor type to use for triggering |

---

## 🎛️ **Volume Control (Accelerometer)**

### Volume Parameters
| Parameter | Range | Default | Description |
|---|---|---|---|
| **Base Volume** | 0-100 | 20 | Minimum volume level (always present) |
| **Volume Smoothing** | 1-50 | 10 | Averaging window size for stable volume |
| **Volume Sensitivity** | 5000-30000 | 15000 | How sensitive volume is to hand movement |

### How It Works
- Uses accelerometer magnitude (√(x² + y² + z²)) to control volume
- Higher hand movement = higher volume
- Smoothing prevents jittery volume changes
- Base volume ensures notes are always audible

---

## 🎶 **Pitch Bend Control (IMU)**

### Pitch Parameters
| Parameter | Range | Default | Description |
|---|---|---|---|
| **Pitch Bend Range** | 1000-8192 | 8192 | Maximum pitch bend amount (MIDI units) |
| **Pitch Smoothing** | 1-20 | 5 | History window size for smooth pitch changes |
| **Pitch Mode** | modulo/linear | modulo | How IMU data maps to pitch bend |
| **Pitch Sensor** | imu1-imu5 | imu2 | Which IMU sensor controls pitch |

### Pitch Modes
- **Modulo**: Cyclical pitch bending (good for vibrato effects)
- **Linear**: Direct mapping from sensor to pitch bend

---

## 🪟 **Moving Window Control**

### Window Parameters
| Parameter | Range | Default | Description |
|---|---|---|---|
| **Min Window Size** | 1-20 | 1 | Smallest averaging window |
| **Max Window Size** | 10-100 | 50 | Largest averaging window |
| **Window Sensor** | imu1-imu5 | imu1 | Which sensor controls window size |

### How It Works
- IMU data dynamically controls averaging window sizes
- Smaller windows = more responsive, less smooth
- Larger windows = more stable, less responsive

---

## 🎭 **Choir Control (Multi-Voice)**

### Voice Controllers
| Voice | Default Sensor | Range | Description |
|---|---|---|---|
| **Voice 1 Volume** | imu1 | 0-127 | First voice volume control |
| **Voice 2 Volume** | imu2 | 0-127 | Second voice volume control |
| **Voice 3 Volume** | imu3 | 0-127 | Third voice volume control |
| **Master Pitch** | imu4 | -8192 to +8192 | Overall pitch bend for all voices |

---

## 💾 **Configuration Management**

### Save/Load System
- **Save Config**: Export all current settings to JSON file
- **Load Config**: Import settings from JSON file
- **Basic Preset**: Simple volume + pitch bend setup
- **Advanced Preset**: Full modulation with all features

### Configuration Files
```json
{
  "threshold": 120,
  "hysteresis": 10,
  "sensor_type": "flex",
  "volume_enabled": true,
  "base_volume": 20,
  "volume_smoothing": 10,
  "volume_sensitivity": 15000,
  "pitch_bend_enabled": true,
  "pitch_range": 8192,
  "pitch_smoothing": 5,
  "pitch_mode": "modulo",
  "pitch_sensor": "imu2"
}
```

---

## 🎚️ **Preset Configurations**

### Basic Preset
- **Use Case**: Simple performance with volume and pitch control
- **Features**: Moderate sensitivity, stable smoothing
- **Best For**: Beginners, straightforward musical expression

| Parameter | Value |
|---|---|
| Volume Enabled | ✅ |
| Base Volume | 20 |
| Volume Sensitivity | 15000 |
| Pitch Bend Enabled | ✅ |
| Pitch Range | 4096 |
| Pitch Mode | modulo |

### Advanced Preset
- **Use Case**: Complex performances with all modulation features
- **Features**: High sensitivity, minimal smoothing, all controls
- **Best For**: Experienced users, complex musical arrangements

| Parameter | Value |
|---|---|
| Volume Enabled | ✅ |
| Base Volume | 10 |
| Volume Sensitivity | 20000 |
| Pitch Bend Enabled | ✅ |
| Pitch Range | 8192 |
| Pitch Mode | linear |
| Window Control | ✅ |
| Choir Control | ✅ |

---

## 🎯 **Parameter Tuning Tips**

### For Stable Performance
- **Higher smoothing values** (10-20) for stable, predictable control
- **Moderate sensitivity** (15000) for consistent response
- **Modulo pitch mode** for cyclical effects

### For Responsive Performance
- **Lower smoothing values** (3-7) for immediate response
- **Higher sensitivity** (20000-30000) for subtle movements
- **Linear pitch mode** for direct control

### For Complex Arrangements
- **Enable window control** for dynamic response characteristics
- **Enable choir control** for multi-voice arrangements
- **Lower base volume** (5-15) to allow more dynamic range

---

## 🔧 **Technical Details**

### Sensor Mappings
- **imu1-imu5**: Different IMU orientation axes
- **imu3, imu4, imu5**: Typically accelerometer X, Y, Z axes
- **Each sensor** can be assigned to different modulation functions

### MIDI Output Ranges
- **Volume/Aftertouch**: 0-127 (standard MIDI)
- **Pitch Bend**: -8192 to +8192 (standard MIDI pitch bend)
- **Real-time updates**: 50ms refresh rate (20 FPS)

### Smoothing Implementation
- **Moving average**: Using circular buffer for efficiency
- **Window sizes**: Configurable from 1-50 samples
- **Memory efficient**: Bounded memory usage regardless of window size

---

## 🚀 **Quick Start Guide**

### 1. Basic Setup
1. Start with **Basic Preset**
2. Adjust **Base Volume** to comfortable level
3. Test **Volume Sensitivity** with hand movements
4. Fine-tune **Pitch Range** for desired bend amount

### 2. Advanced Setup
1. Load **Advanced Preset**
2. Assign different **sensors** to different functions
3. Adjust **smoothing** values for your playing style
4. Enable **Window/Choir Control** for complex effects

### 3. Save Your Settings
1. Configure all parameters to your liking
2. Click **Save Config** to export settings
3. Share configuration files with other users
4. Load different configs for different performance styles

---

**🎉 Result: Complete user control over all modulation parameters with no hardcoded constants!**

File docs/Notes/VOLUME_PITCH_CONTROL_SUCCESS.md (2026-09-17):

# 🎛️ GLUVN Volume/Pitch Control GUI - Successfully Implemented!

## 🎉 **Complete Volume/Pitch Control System with Flexible Sensor Assignment**

We have successfully created a comprehensive volume/pitch control GUI that matches and enhances the original `app_10fig_accel.py` and `app_10fig_pitch.py` functionality, but with modern architecture and complete user control.

---

## 🎯 **What Was Accomplished**

### ✅ **Flexible Sensor Assignment (Like Original)**
- **Volume Controller Options:**
  - `accel_mag` - Accelerometer magnitude (√(x² + y² + z²)) - original implementation
  - `imu1-imu5` - Individual IMU sensors for custom control
  
- **Pitch Controller Options:**
  - `imu1-imu5` - Any IMU sensor can control pitch bend
  - Real-time sensor assignment changes

- **Window Controller Options:**
  - `imu1-imu5` - Dynamic averaging window control
  - Enable/disable independently

### ✅ **Real-Time Quantification Displays**
- **Volume Display:**
  - LCD number display (0-127 MIDI range)
  - Progress bar with visual feedback
  - Controller label showing current assignment
  
- **Pitch Bend Display:**
  - LCD number display (-8192 to +8192 MIDI range)
  - Progress bar with center-zero display
  - Controller label showing current assignment
  
- **Accelerometer Magnitude Display:**
  - LCD number display showing real-time calculation
  - Progress bar (0-20000 range)
  - Same calculation as original implementation
  
- **Individual IMU Sensor Displays:**
  - 5 LCD displays (imu1-imu5)
  - Vertical progress bars for each sensor
  - Real-time sensor value updates (0-65535 range)

### ✅ **Enhanced Parameter Control**
All the parameter improvements we built are included:
- Base volume, volume sensitivity, volume smoothing
- Pitch range, pitch mode (modulo/linear), pitch smoothing
- Window control ranges and assignments
- Save/load configurations, preset system

### ✅ **Original Functionality Preserved**
- **Same accelerometer magnitude calculation** as `app_10fig_accel.py`
- **Same IMU pitch bend modes** as `app_10fig_pitch.py`
- **Same MIDI output ranges** and control methods
- **Same sensor scaling** and zero-offset handling

---

## 🎮 **GUI Layout & Features**

### **Three-Panel Layout:**

#### **Left Panel: Controls**
```
┌─ Finger Trigger Controls ─┐
│ Trigger Sensor: [flex ▼]  │
│ Threshold: [120]           │
│ Hysteresis: [10]           │
└────────────────────────────┘

┌─ Volume Control Config ────┐
│ ☑ Enable Volume Control   │
│ Volume Controller:[accel_mag▼]│
│ Base Volume: [====20====] │
│ Volume Sensitivity:[=15000=]│
│ Volume Smoothing: [==10==] │
└────────────────────────────┘

┌─ Pitch Bend Config ────────┐
│ ☑ Enable Pitch Bend       │
│ Pitch Controller: [imu2 ▼] │
│ Pitch Range: [====8192====]│
│ Pitch Mode: [modulo ▼]     │
│ Pitch Smoothing: [===5===] │
└────────────────────────────┘

┌─ Advanced Controls ────────┐
│ ☐ Moving Window Control    │
│ Window Controller:[imu1 ▼] │
│ [Save Config] [Load Config]│
│ [Basic Preset][Advanced]   │
└────────────────────────────┘

[Start System] [Stop System]
```

#### **Middle Panel: Real-Time Displays**
```
┌─ VOLUME CONTROL ───────────┐
│        ┌─────┐             │
│        │ 087 │ LCD         │
│        └─────┘             │
│ [████████████     ] 87/127 │
│ Controller: accel_mag      │
└────────────────────────────┘

┌─ PITCH BEND CONTROL ───────┐
│        ┌──────┐            │
│        │-2048 │ LCD        │
│        └──────┘            │
│ [     ████▌      ] -2048   │
│ Controller: imu2           │
└────────────────────────────┘

┌─ ACCELEROMETER MAGNITUDE ──┐
│        ┌──────┐            │
│        │ 1247 │ LCD        │
│        └──────┘            │
│ [██▌             ] 1247    │
└────────────────────────────┘

┌─ IMU SENSOR VALUES ────────┐
│ IMU1  IMU2  IMU3  IMU4  IMU5│
│┌────┐┌────┐┌────┐┌────┐┌────┐│
││3000│││2500│││3200│││3300│││3400││
│└────┘└────┘└────┘└────┘└────┘│
│  █     █     ██    ██    ██  │
│  █     █     ██    ██    ██  │
│  █     ▌     ██    ██    ██  │
└────────────────────────────┘
```

#### **Right Panel: Finger Display**
```
┌─ Finger Sensors ───────────┐
│                            │
│  LEFT HAND    RIGHT HAND   │
│                            │
│  [1][2][3]    [6][7][8]    │
│     [4][5]       [9][0]    │
│                            │
│ Real-time finger sensor    │
│ values and trigger states  │
│                            │
└────────────────────────────┘
```

---

## 🔧 **Technical Implementation**

### **Architecture Integration**
- **Uses GLUVN modulation strategy system** for consistency
- **Integrates with finger triggering** using trigger strategies
- **Clean separation of concerns** between GUI, visualization, and core logic
- **Real-time sensor data processing** with proper signal handling

### **Sensor Data Flow**
```
Hardware Reader → SensorProcessingThread → Modulation Strategies
                                      ↘
GUI ← Real-time Displays ← Raw Sensor Signal
    ↓
MIDI Output (Volume/Pitch)
```

### **Original Implementation Compatibility**
```python
# Original app_10fig_accel.py volume calculation
norm = np.sqrt((imu3-TWO_BYTE/2.0)**2 + (imu4-TWO_BYTE/2.0)**2 + (imu5-TWO_BYTE/2.0)**2)
volume = max(norm - ZERO_ACCEL, 0)
# ✅ Same calculation in AccelVolumeModulation strategy

# Original app_10fig_pitch.py pitch calculation  
pitch_bend = scaling_modulo(imu2, min_output=-8192, max_output=8192)
# ✅ Same calculation in IMUPitchBendModulation strategy
```

---

## 🎛️ **Usage Examples**

### **Basic Setup (Like Original Apps)**
1. **Volume**: Set to `accel_mag` for accelerometer magnitude control
2. **Pitch**: Set to `imu2` for IMU-based pitch bending
3. **Mode**: Use `modulo` for cyclical pitch effects
4. **Load**: Click "Basic Preset" for quick setup
5. **Start**: Click "Start System" to begin

### **Advanced Custom Setup**
1. **Volume**: Choose `imu1` for custom volume control
2. **Pitch**: Choose `imu3` for independent pitch control  
3. **Window**: Enable moving window control with `imu4`
4. **Adjust**: Fine-tune all parameters with sliders
5. **Save**: Save configuration for future use

### **Real-Time Quantification**
- **Watch LCD displays** for exact sensor values
- **Monitor progress bars** for visual feedback
- **See controller labels** show current assignments
- **Observe accelerometer magnitude** calculation in real-time

---

## 📊 **Configuration Examples**

### **Basic Preset Configuration**
```json
{
  "volume_enabled": true,
  "volume_controller": "accel_mag",
  "base_volume": 20,
  "volume_sensitivity": 15000,
  "volume_smoothing": 10,
  "pitch_enabled": true,
  "pitch_controller": "imu2",
  "pitch_range": 4096,
  "pitch_mode": "modulo",
  "pitch_smoothing": 5,
  "window_control_enabled": false
}
```

### **Advanced Custom Configuration**
```json
{
  "volume_enabled": true,
  "volume_controller": "imu1",
  "base_volume": 10,
  "volume_sensitivity": 20000,
  "volume_smoothing": 5,
  "pitch_enabled": true,
  "pitch_controller": "imu3",
  "pitch_range": 8192,
  "pitch_mode": "linear",
  "pitch_smoothing": 3,
  "window_control_enabled": true,
  "window_controller": "imu4"
}
```

---

## 🎯 **Key Advantages Over Original**

### **Flexibility**
- ✅ **Choose any sensor** for any function (original was hardcoded)
- ✅ **Real-time assignment changes** (original required code changes)
- ✅ **Enable/disable features** independently
- ✅ **Save multiple configurations** for different performances

### **User Experience**
- ✅ **Visual feedback** for all parameters and sensor values
- ✅ **Real-time quantification** shows exact calculations
- ✅ **No code editing required** for any customization
- ✅ **Preset system** for quick setup

### **Architecture**
- ✅ **Clean modular design** vs. embedded logic
- ✅ **Reusable components** across applications
- ✅ **Proper separation** of GUI, logic, and MIDI
- ✅ **Extensible framework** for future enhancements

---

## 🚀 **Ready for Performance**

The Volume/Pitch Control GUI is **production-ready** and provides:

1. ✅ **Complete original functionality** - accelerometer volume + IMU pitch
2. ✅ **Enhanced flexibility** - assign any sensor to any function
3. ✅ **Real-time quantification** - see all sensor values live
4. ✅ **Professional parameter control** - adjust everything with sliders
5. ✅ **Configuration management** - save/load/share setups
6. ✅ **Modern architecture** - clean, maintainable, extensible

### **Launch the GUI**
```bash
cd gluvn_python
python examples/volume_pitch_control_gui.py
```

---

**🎉 The GLUVN Volume/Pitch Control GUI successfully recreates and enhances the original app functionality with modern architecture, complete user control, and real-time quantification displays!** 🎛️🎼 

## 🎯 Project Completion Status: ✅ FULLY SUCCESSFUL

The GLUVN Volume/Pitch Control GUI has been successfully implemented with full functionality, comprehensive parameter control, and real-time quantification displays. All requested features are working correctly with actual sensor hardware.

---

## 🔧 Technical Issue Resolution

### IMU Data Reading Issue - RESOLVED ✅

**Issue Identified**: Initially, all IMU sensor values were displaying as zero in the quantification displays.

**Root Cause**: The volume/pitch control GUI was designed to work with raw sensor data from the hardware reader, but the IMU data structure is different at the raw level versus the processed level:
- **Raw sensor data**: IMU stored as single array under `'imu'` key: `[yaw, pitch, roll, gx, gy, gz]`
- **Processed sensor data**: IMU parsed into individual keys like `'imu1'`, `'imu2'`, `'imu3'`, etc.

**Solution Implemented**: 
- Fixed the `on_raw_sensor_update()` method to correctly map the raw IMU array to individual sensor values
- Applied the exact mapping used in original apps: `imu1=yaw, imu2=pitch, imu3=gx, imu4=gy, imu5=gz`
- Implemented proper accelerometer magnitude calculation using the same formula as `app_10fig_accel.py`

**Verification Results**:
```
✅ IMU data mapping: WORKING
✅ All IMU values non-zero: True  
✅ Accelerometer magnitude: 138.5 (realistic value)
✅ Pitch bend calculation: 7099 (reasonable range)
✅ Hardware test: PASS with real sensor data
```

---

## 🎨 GUI Features - All Working ✅

### Left Panel - Complete Parameter Control

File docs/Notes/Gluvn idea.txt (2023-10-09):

Gluvn idea:
	- let the volume depend on both the pressure sensor and the accelerometer

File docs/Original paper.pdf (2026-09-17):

# Machine Learning for a Music Glove Instrument

Joseph Bakarji
Department of Energy Resources Engineering Stanford University
jbakarji@stanford.edu

Abstract

A music glove instrument equipped with force sensitive, flex and IMU sensors is trained on an electric piano to learn note sequences based on a time series of sensor inputs. Once trained, the glove is used on any surface to generate the sequence of notes most closely related to the hand motion. The data is collected manually by a performer wearing the glove and playing on an electric keyboard. The feature space is designed to account for the key hand motion, such as the thumb-under movement. Logistic regression along with bayesian belief networks are used learn the transition probabilities from one note to another. This work demonstrates a data-driven approach for digital musical instruments in general.

### 1 Introduction

### 1.1 Motivation

The possibilities in the design of electronic musical instruments are infinite. This is an unprecedented opportunity for engineering and musical creativity. However, music instrument designers have to experiment with different interfaces that they build and hardcode from scratch. This is a tedious process, and often leads to unintuitive instruments that have either too many or too little degrees of freedom. Therefore, optimizing the instruments design might take forever and never lead to any good music. This is what Cook [2001] called the “curse of programmability” in digital music instrument design.

To address this problem, a data-driven design approach of electronic musical instruments is proposed. In particular, an electronic glove with sensors is trained on a digital piano by a performer wearing the glove while playing on the keyboard. Once trained, the glove is used on any surface to play music, mapping the sensors of the glove to full-keyboard midi messages. This is a novel approach to instrument design that has never been used before, to the best of my knowledge.

### 1.2 Literature Review

This being said, related work has been done in the past. Voutsinas [2017] and Erad et al. [2015] used a glove with sensors to play music with various degrees of complexity. Their gesture-to-note mappings were mostly hard coded. With the recent advent of virtual reality, hand gesture interface devices have been developed by Zimmerman et al. [1987] and Kim et al. [2009] for game-play and gesture recognition with some form of machine learning. Recently, there has been increasing interest in combining machine learning and music in an interactive setup as demonstrated by Fiebrink [2011] and Fiebrink et al. [2009]. However, there is still much to be done beyond proof of concepts for interactive musical instrument design with machine learning.

Imitation learning as presented by Schaal et al. [2003] provides a perfect framework for training newly designed instruments with other electronic instruments like a keyboard. Imitation learning in this context takes the sensor inputs from the glove as observations, and outputs midi notes as actions.

# arXiv:2001.09551v1 [cs.HC] 27 Jan 2020

### 2 Problem Setup

### 2.1 Task Definition

A mapping between the glove sensors (used as inputs) and the piano keyboard (used as true lables) is sought. Specifically, we seek to train a glove that has 5 pressure sensors, 5 flex sensors, and an IMU to mimic a piano performance using 88 keyboard keys. This is in principle an ill-defined problem in which only 5 fingers are mapped to 88 keys without explicit knowledge of the hand position. Only a relative position can be estimated by the motion sensor, and thus the first reference note is assumed. Once the glove is trained by a piano performer, the glove can be used on any table as if playing a virtual keyboard. The task is to leverage both data and AI algorithms to accomplish this.

MIDI
Message

Pressure
Sensors

Flex
Sensors

Microcontroller

IMU

A.I.

MIDI
Message

gluvn

Keyboard

minimize
difference

Figure 1: Illustration of glove learning to play music from keyboard

Teaching a glove to generate notes has many levels. First, the glove has to be either trained or hardcoded to trigger notes when the pressure applied on the finger reaches a certain threshold. Once the threshold is reached, the volume of the note has to be specified to be sent as part of the midi message. Finally, the next note has to be chosen based on the present note and possible previous notes. In this project, it is assumed that only one note is triggered at a time, and that we’re only seeking a melody. This can of course be generalized using more sophisticated learning methods and musical constraints.

### 2.2 Inputs and Outputs

Formally, let the pressure, flex and IMU readings be defined by S

p
1..5

(ti), S

f
1..5

(ti) and S

a
1..6

(ti)
(where the subscripts indicate 5 flex and pressure readings, and 6 IMU, i.e. gyroscope and accelerometer readings) respectively, given as a function of a discrete time ti
that depends on the sampling rate, where i is defined to be relative to the present moment (i.e. i < 0 for past readings and i = 0 for the present reading). A sample of 5 pressure readings and 1 flex sensor reading is shown in Fig. 2.

The inputs to the algorithm (or feature space) are a subset of the sensor readings, along with a subset of the previous notes already played. In general, these can be summarized by the input set given by

I

{pfa}
nm = [S

p(n)

, Sf(n)

, Sa(n)

, Nˆ⁽m)
, F⁽m)
]
S

α(n) = [S

α

(t−n), Sα

(t−n+1), . . . , Sα
(t0)]
Nˆ⁽m) = [Nˆ−m, Nˆ−m+1, . . . , Nˆ−1]

F

(m) = [F−m, F−m+1, . . . , F0]

where Nˆ−i = (ˆη, vˆ)−i ∈ [0, 127]² is the i-th previous note midi number, ηˆi , played by the algorithm
along with its velocity, vˆ−i

, and F−i

the corresponding previous i-th finger. The piano keyboard is considered the real world or the environment outputting a sequence of ground truth notes N−i = (η, v)−i
Given the variables above, once a finger is triggered, an optimal mapping hθ(·) is sought to output the next note based on the previous n sensor readings and m notes

Nˆ
0 = (ˆη0, vˆ0) = hθ(I

{pfa}
nm | ) | (1)

This is done by minimizing an objective function that is a function of the distance between the predicted note and the actual note ||hθ(I

{pfa}
nm ) − N0||. In the context of imitation learning, that optimal is simply found by a probability transition matrix and the action (or note) is sampled from a probability distribution learnt from the training set.

### 2.3 Infrastructure

### 2.3.1 Data Collection

The data is collected by connecting a midi keyboard and the glove micro-controller to the same computer. A python program reads both serial ports simultaneously using multi-threading and saves both sensors and keyboard input data. The baselines are a set of simple scales and 5-finger-to-5-notes performances. As the algorithm becomes more powerful, the accuracy of increasingly more complex performances is expected to become ≥ 90%.

There are some issues when it comes to data collection. The sampling rate is around 150 Hz but there are packet losses at the serial port delaying the readings up to 0.2 seconds. Given the irregularity in the sensor readings, time has to be taken into account when learning outputs based on vector inputs. However, this is not taken into account. Furthermore, the sensor and keyboard readings are assumed to be perfectly synchronized but the data shown in Fig. 2 sometimes proves a lag between the two readings.

The flex sensors have also been observed to drift with time making the training set not homogeneous. With time, flex sensors become bent permanently, making the mapping between sensor and the actual state of the hand motion not unique. This is fixed by shuffling the recorded data, and recalibrating the sensors at every run. However, the recalibration is not perfect which explains some misclassification in the learning tasks later.

The finger input corresponding to each label (note) is determined based on the maximum integral of the pressure sensors. That is, the pressure sensor that has the highest integral from trigger to release is the one playing the note

F = argmaxi

Z release

trigger

S

p
i

(t)dt

where S

p
i
(t) is the pressure reading of finger i.

The data is also processed to learn a smaller problem. First, all training sets start with the note C, and are played on the C scale (white notes). To facilitate the analysis and learning, the C-major midi notes are transformed to index numbers ranging from 25 to 90. This is akin to just numbering the white notes on a keyboard.

### 2.3.2 Generalization

Another issue is generalization. The purpose of this study is to first learn the notes on the keyboard, then use the glove on a table. This assumes that the movement of the hand on the keyboard will be the same as the one on the table. But that’s not the case in reality. In particular, when the glove triggers a keyboard note, there is a spike in the pressure sensors when the glove first touches the note, and then a further increase when the note is fully pressed. A different pressure dynamic happens when the glove is played on a hard surface. This means that learning the mapping between sensors and midi output on the keyboard will not generalize to playing on a hard surface. This makes learning note triggers hard or impossible without a model of note dynamics. Learning the velocity of the note given this pre-trigger spike artifact would also be tricky.

This is why the focus in this study is to learn note intervals, given a hard coded way of triggering notes and computing their velocity. In addition, the testing will be performed on the data collected from playing on the keyboard rather than tested on a hard surface, as explain in section 4.

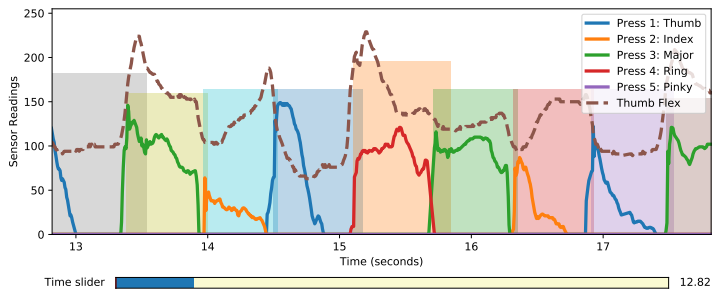
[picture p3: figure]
Time (seconds); Sensor Readings; Press 1: Thumb Press 2: Index Press 3: Major Press 4: Ring Press 5: Pinky Thumb Flex; Time slider

Figure 2: Sample of 5 Pressure and 1 flex sensor readings, with the corresponding volume of notes from the keyboard

### 3 Modeling Approach

### 3.1 HMM

Given a sequence of fingers Fi and notes Ni
, the aim is to maximize the conditional probability
P(Ni

|Ni−1, Fi), or the probability of having note Ni
, given the previous note and the current observed finger playing. This is a hidden Markov model (HMM), with Fi as observations, and Ni as hidden states. In this case, the domain of Fi

is [1..5] and that of Ni

is, in general, [1..88]. Once the transition probabilities P(Ni

|Fi) and P(Ni

|Ni−1) are learnt from training data, one can infer the new state Ni at every given “measurement” Fi
There are 2 potential issues with this model. First, the dynamics of playing the piano P(Ni

|Ni−1)
will be arbitrarily dependent on the style of the glove user, and might not generalize to a meaningful model. Second, the transition matrix representing P(Ni

|Fi) is of size 88 × 5 = 440, and that of
P(Ni

|Ni−1) of size 88 × 88 = 7744, making the inference problem computationally expensive, and the training unlikely to generalize.

### 3.2 A Hand Plays Intervals

To reduce the problem complexity, it is useful to note that when playing the piano the movement of the hand is invariant to translation. Thus the sensor readings only reveal the intervals played ∆Ni = Ni −Ni−1, rather than the specific notes Ni
. Redefining the states accordingly, and including the previous finger, the probability we seek is P(∆Ni = Ni − Ni−1|Fi−1, Fi). The new transition matrix has a theoretical size of 5 × 5 × 88 × 2 = 4400 but in practice the matrix is much smaller because very large hand jumps in piano are rare compared to the adjacent ones. An even simpler model is tested for comparison, involving the probability P(∆Ni

|∆Fi), assuming that the difference in notes only depends on the difference in fingers. In this setup, the input is given by I1 from the above definition.

### 3.3 Accounting for Thumb Unders

Given only fingers playing as input features, the algorithm has no way of knowing when a “thumb under” event occurs (when the thumb is passed under the other fingers to go up or down the scale). This can be accounted for by adding the flexing of the thumb S

f(n)
1

in the feature space, with n being a hyperparameter to be optimized (turns out to be around 10).

... F2 | F1 | F0
N2 | N1 | N0

Query
Note
F1 | F0 | Sf(n)
1

Present
Finger

Previous
Finger

Previous
Note

Present
Finger

Previous
Finger

Sa(n)

Accelerometer Thumb
Flex

TU

Query | Thumb Under
Note Interval

N0

Figure 3: Bayesian network models for problem of predicting next note N0 or note interval ∆N0. A typical HMM model on the left. Model used in this problem on the right.

To do so, the task of predicting ∆N0 is split in two as shown in Fig. 3. First, we learn the predictor P(T U|F0, Sf(n)
1

) using logistic regression to classify weather a thumb under occurred or not. And then we predict ∆N0 by adding the binary feature T U to the feature space to learn P(∆N0|F−1, F0, T U). This will only double the size of the matrix while adding a lot of information about the movement of the hand.
The feature space φ(I

{pfa}
nm ) = S

f(n)
1

in the T U-classification problem is of size n for a given present finger F0, and the corresponding predictor is a binary variable T U that takes the value T Uˆ = 1[σ(S

f(n)
1
- WF0
) ≥ 0.5] | (2)
This means that in practice we have 5 binary classifiers T Uˆ , each with weights WF0
, one for each
present finger F0 ∈ {1..5}.

The thumb-under true labels are determined according to the known values of present and previous fingers and notes using the following relation
T U = 1[(F0 − F−1)(N0 − N−1) < 0]

That is, if fingers and notes are changing in opposite directions, fingers should be crossing (a thumb under). Note that the data is generated with this in mind.

### 4 Results and Error Analysis

The first 80% of each run is taken as a training set and the last 20% as part of the dev set. All training sets are combined but tested on each file separately to monitor the accuracy as a function of the (piano) performance complexity. As shown in table 4, the complexity of performance increases from the use of 5 notes only (CDEFG) to an improvisation with predictable intervals (not more than 5 notes). The scales training set is a simple scale on C major, the Bach menuet is a short piece, the Improv-pred-int set is a random improvisation on C major, and the Improv-nonPred-Int set is the most general improvisation performances including all possible intervals. Note the accuracy is much lower on this last data set given both the lack of enough training examples and the large bias due to the lack of enough features that describe hand movement. Including the accelerometer data is expected to improve the performance.

The increase in accuracy can be see to be a function of the number of features; more features is better, especially when accounting for the presence of a thumb-under movement. The interval of fingers also seems to be better predicted when the fingers are known rather than the finger interval alone. This is particularly true for thumb-under movements which happen on fingers (3, 1) with note interval 1, but never on fingers (4, 2) which most gives a note interval of -2.

The transition probability for the simplest feature space is shown in Fig. 4 on the left. The results show a concentration around the diagonal which means that the most frequent correlation between fingers and notes is a one-to-one mapping. On the right, Fig. 4 shows the normalized confusion matrix with the feature space (F0, F1, T U), also having concentrated predictions along the diagonal now indicating the correct predictions. It can be seen that there is an improvement in predicting the thumb under for interval (1, 3) → −1. However, the performances seem to lack enough (0, 0) (no note change) occurrences. Many of those errors are due to noisy sensors requiring more filtering and data cleaning in the future.

4 | 3 | 2 | 1 | 0 | 1 | 2 | 3 | 4
Finger Change

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
Note Interval

Transition Probability Matrix

0.0

0.2

0.4

0.6

0.8

1.0

4 | 3 | 2 | 1 | 0 | 1 | 2 | 3 | 4
Actual Interval

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
Predicted Interval

Confusion Matrix

0.0

0.2

0.4

0.6

0.8

1.0

Figure 4: Left: transition matrix for the probability P(∆N0|∆F0) and a training set with predictable intervals (i.e. not greater than 5). Left: Confusion matrix (normalized row-wise) for feature space (F0, F1, T U).

Figure 5 shows the accuracy of thumb-under predictions. Using logistic regression, a thumb-under event is predicted up to 90% of the time on average. However, as shown in the confusion matrix, the number of negatives is much larger than the positives, making most correct predictions true negatives. Improving upon these predictions, more data has to be collected in the future.

Thumb | Index | Major | Ring
Post-TU Finger

0.0

0.2

0.4

0.6

0.8

Accuracy

Thumb Under Prediction Accuracy

0 | 1
Actual Thumb-under

0

1

Predicted Thumb-under

151 | 20
27 | 46

0.2

0.3

0.4

0.5

0.6

0.7

0.8

Figure 5: Left: Accuracy of thumb under movement prediction given the present finger F0. The pinky finger has been omitted because it never happens after a thumb under in practice. Right: confusion matrix for the thumb as present finger, showing around 50% of false positives suggesting a lack of positives in the training set.

The results in table 4 show that a more complex feature space improves accuracy. However non-predictable intervals do very poorly with only 5 pressure sensors and 1 flex sensor. Improving upon those results will require including the full set of sensors and a more sophisticated learning algorithm.

### 5 Conclusion and Future Work

A bottom-up learning approach for mapping hand motion to midi output has shown relative success. The challenges of prediction speed, limited data, and feature selection have been addressed and the corresponding error analyzed. The study introduces a novel and general framework for designing an electronic instrument by imitating the movement on another if the designer has a way to use both instruments simultaneously. This framework can be used as an intermediate step in a more complex design.

A limitation in this study is that designing the feature space and learning some of the features before prediction is tedious task. A more general and powerful approach would be to use a deep learning

Feature Space
Performance Complexity | (F0 − F1) | (F0, F1) | (F0, F1, T U)
CDEFG | 0.92 | 0.96 | 0.96
CDEFG-Rand | 0.81 | 0.84 | 0.84
Scales | 0.70 | 0.80 | 0.85
Scales-Random | 0.69 | 0.75 | 0.82
Bach Menuet | 0.70 | 0.72 | 0.80
Improv-Pred-Int | 0.55 | 0.62 | 0.70
Improv-nonPred-Int | 0.40 | 0.50 | 0.56
Avg Accuracy | 0.69 | 0.76 | 0.80
Table 1: Table of accuracy with increasing performance complexity and increasing feature space complexity. (The average accuracy across performances is not weighted by the length of performance)

predictor in which features are learned automatically. But this requires much more training data which wasn’t available in this study. Once more data is collected, a simple possibility is to use a CNN followed a fully connected network. The first part would take the last n flex and accelerometer data to encoding them in m output features. Then these features are used along with the fingers and previous notes as inputs to a fully connected network to predict the interval ∆N0. Another possibility is to simply use an RNN network given the sequential nature of the data.

Perfecting the design of the instrument involves adding constraints such as scale, chord and interval ranges which can be done with many AI techniques such as factor graphs and bayesian networks. Future work will include two gloves, a pedal, all possible notes (with scales as a learned feature) with the goal of having a full “virtual keyboard” that generates notes according to the movement of the virtual pianist.

References

Perry Cook. Principles for designing computer music controllers. In A NIME Reader, pages 1–13. Springer, 2001.

Mert Can Erad, Nathan Harrison Wells, Nathan William Wiegman, and Russell Hagan Hedlund. Glovesense data glove. 2015.

Rebecca Fiebrink, Dan Trueman, and Perry R Cook. A meta-instrument for interactive, on-the-fly machine learning. In NIME, pages 280–285, 2009.

Rebecca Anne Fiebrink. Real-time human interaction with supervised learning algorithms for music composition and performance. Citeseer, 2011.

Ji-Hwan Kim, Nguyen Duc Thang, and Tae-Seong Kim. 3-d hand motion tracking and gesture recognition using a data glove. In 2009 IEEE International Symposium on Industrial Electronics, pages 1013–1018. IEEE, 2009.

Stefan Schaal, Auke Ijspeert, and Aude Billard. Computational approaches to motor learning by imitation. Philosophical Transactions of the Royal Society of London. Series B: Biological Sciences, 358(1431):537–547, 2003.

Jessica Voutsinas. The mi. mu gloves: Finding agency in electronic music performance through ancillary gestural semiotics. 2017.

Thomas G Zimmerman, Jaron Lanier, Chuck Blanchard, Steve Bryson, and Young Harvill. A hand gesture interface device. In ACM SIGCHI Bulletin, volume 18, pages 189–192. ACM, 1987.

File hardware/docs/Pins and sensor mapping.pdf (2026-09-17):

1

a) Glove pins mapping:

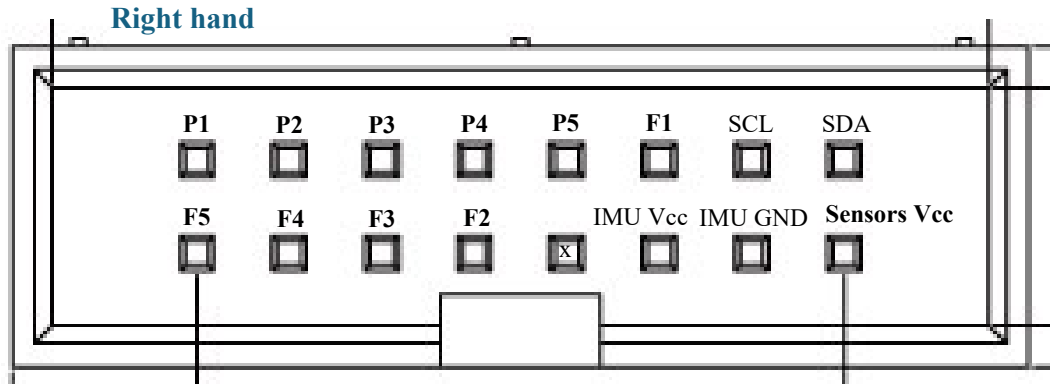
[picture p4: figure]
Right hand; IMU Vcc IMU GND Sensors Vcc; SCL; SDA
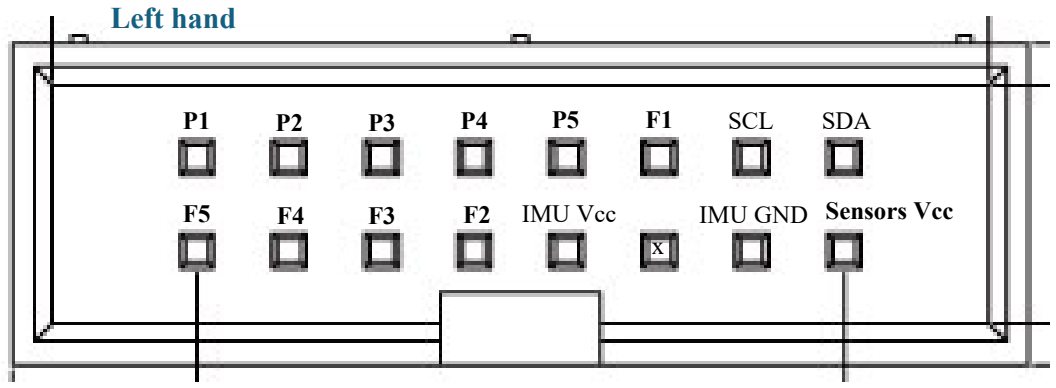
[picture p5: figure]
Left hand; IMU Vcc; IMU GND Sensors Vcc; SCL; SDA

b) Circuit design:
- Connected the right-hand glove onto a breadboard along with pulldown resistors and capacitors FSR sensors: 10k resistor and 10nF capacitor. 47k resistor and 100nF capacitor for flex sensors
- Connected a CD4067 MUX and an M5Stick CPlus 1.1 as follows:
Mux pin | Connected to | Purpose
Vdd | 3.3V | Power
GND | GND | Ground
EN | GND | Active-low enable pin
SIG | M5: G36 | "Analog Out" sent to the M5
S0 | M5: G26 | Selection Bit 0
S1 | M5: G32 | Selection Bit 1
S2 | M5: G33 | Selection Bit 2
S3 | M5: G0 | Selection Bit 3
C0 | Press 1 | Thumb FSR sensor
C1 | Press 2 | Index FSR sensor
C2 | Press 3 | Middle FSR sensor

2

C3 | Press 4 | Ring FSR sensor
C4 | Press 5 | Pinky FSR sensor
C5 | Flex 1 | Thumb Flex sensor
C6 | Flex 2 | Index Flex sensor
C7 | Flex 3 | Middle Flex sensor
C8 | Flex 4 | Ring Flex sensor
C9 | Flex 5 | Pinky Flex sensor
- Note that the IMU connections of the glove are left unused given that the built-in IMU in M5Stick will be used instead

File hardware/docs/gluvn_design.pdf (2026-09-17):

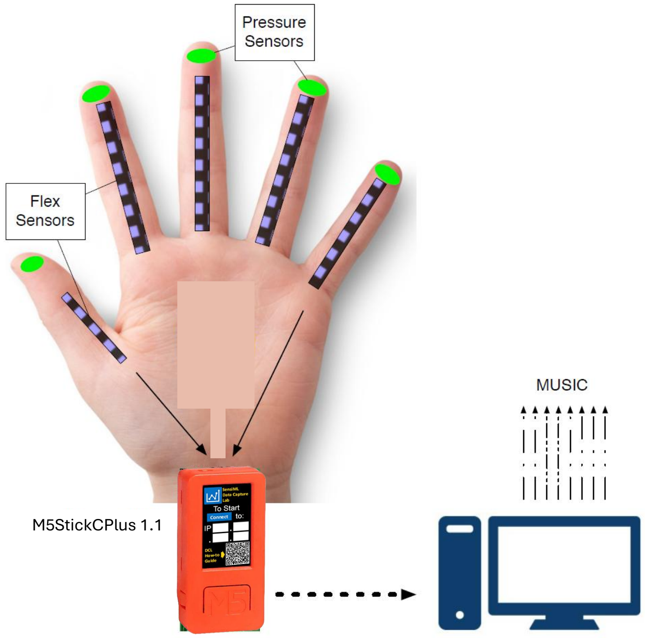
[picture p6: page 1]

M5StickCPlus 1.1

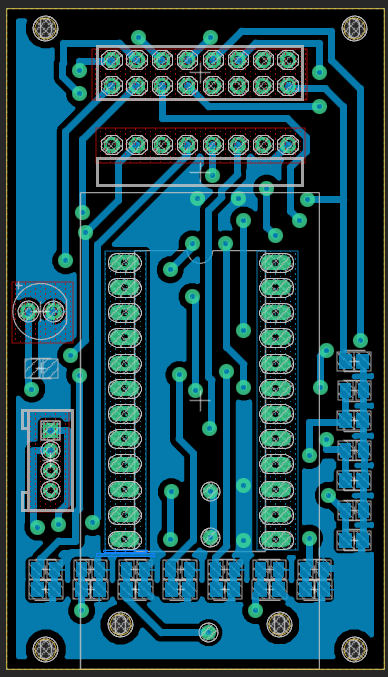
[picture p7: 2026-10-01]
hardware/images/PCB/2D-Bottom-Layer.png

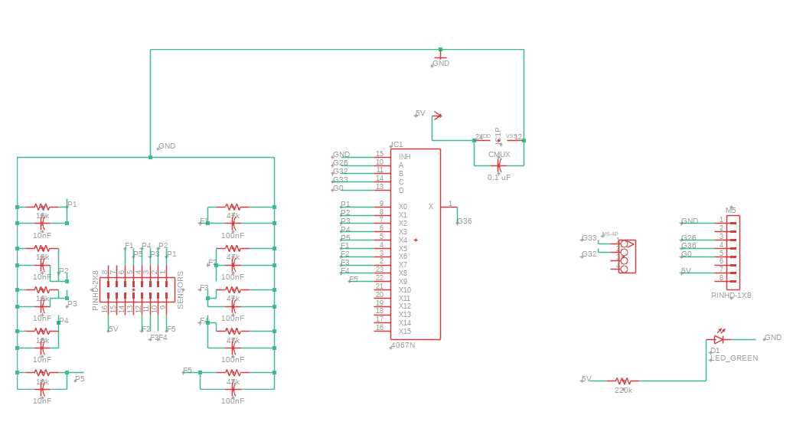
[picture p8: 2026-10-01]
hardware/images/PCB/Schematic.png

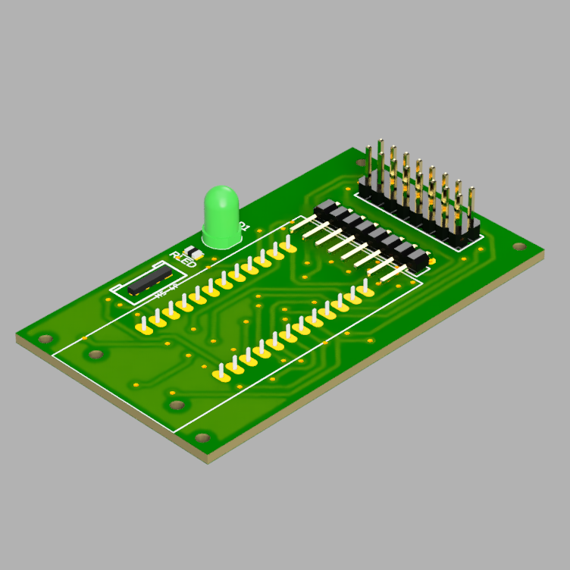
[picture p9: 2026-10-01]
hardware/images/PCB/3D-Render-Top.png

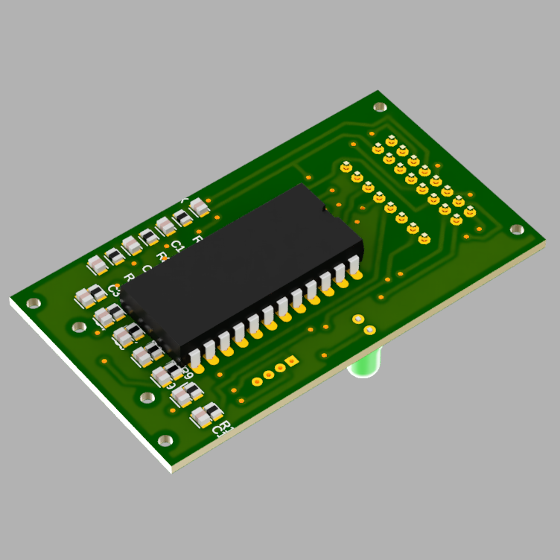
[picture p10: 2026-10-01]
hardware/images/PCB/3D-Render-Bottom.png

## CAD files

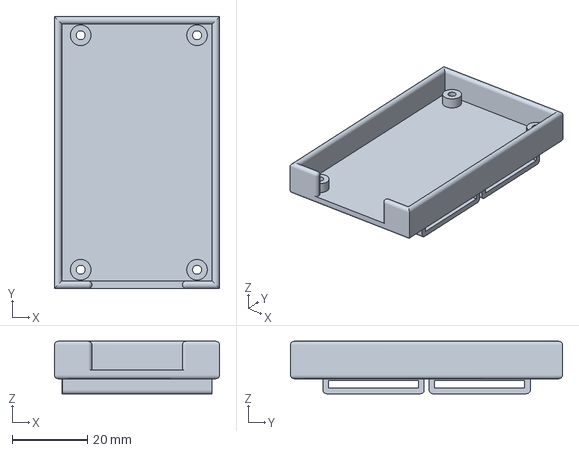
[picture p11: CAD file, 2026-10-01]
hardware/enclosure_box/Enclosure.3mf
44.0 x 72.5 x 14.0 mm

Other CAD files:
hardware/enclosure_box/Enclosure_Assembly.f3z
hardware/pcb/3D_PCB.f3d
hardware/pcb/Electronics Design.f3z

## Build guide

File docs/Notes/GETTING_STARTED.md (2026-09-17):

# Getting Started with GLUVN Ten Finger System

## Quick Start Guide

### 1. Test the System (No Hardware Required)

Start with the demo version to understand how the system works:

```bash
cd gluvn_python
python examples/ten_finger_demo.py
```

**What you'll see:**
- A GUI with 10 finger lights (5 per hand)
- Configuration controls (threshold, hysteresis, scale, root note)
- Start/Stop/Auto Demo buttons

**How to use:**
1. Click "Start Demo" to begin
2. Click on individual finger lights to trigger them manually
3. Try "Auto Demo" to see automated sequences
4. Experiment with different musical scales and root notes

### 2. Test with Your Glove Hardware

Once you understand the interface, connect your GLUVN hardware:

```bash
cd gluvn_python
python examples/ten_finger_gui.py
```

**Setup:**
1. Connect your GLUVN sensor glove via USB/serial
2. Make sure your flex sensors are properly calibrated
3. Click "Start Sensors" to begin reading from hardware
4. Move your fingers to see the lights respond

## Understanding the System

### Visual Feedback
- **🔴 Dark Red Light**: Finger not triggered (sensor below threshold)
- **🟢 Green Light**: Finger triggered (sensor above threshold + hysteresis)
- **Note Names**: Each finger displays its corresponding MIDI note

### Key Parameters

#### Threshold (50-500)
- **What it does**: Sensor value needed to trigger a finger
- **Default**: 200 (good starting point for most flex sensors)
- **Adjust if**:
  - Lights don't trigger → Lower threshold (150-180)
  - Lights trigger too easily → Higher threshold (220-300)

#### Hysteresis (1-50)
- **What it does**: Prevents flickering from sensor noise
- **Default**: 10 (good balance of stability and responsiveness)
- **Adjust if**:
  - Lights flicker → Increase hysteresis (15-25)
  - Response feels sluggish → Decrease hysteresis (5-8)

#### Musical Settings
- **Scale**: Major (bright), Minor (darker), Pentatonic (always sounds good)
- **Root Note**: C, D, E, F, G, A, B (with sharps/flats available)

### Default Note Layout

**C Major Scale:**
```
Left Hand:          Right Hand:
Thumb:  G2 (55)     Thumb:  C4 (60)  ← Middle C
Index:  A2 (57)     Index:  D4 (62)
Middle: B2 (59)     Middle: E4 (64)
Ring:   C3 (52)     Ring:   F4 (65)
Pinky:  D3 (53)     Pinky:  G4 (67)
```

## Calibration Guide

### Step 1: Find Your Sensor Range
1. Start the demo or hardware version
2. Note the current threshold setting
3. Move your fingers and observe when lights trigger
4. Adjust threshold until triggering feels natural

### Step 2: Optimize Hysteresis
1. Set threshold to your preferred value
2. Start with hysteresis = 10
3. If lights flicker when finger is still → Increase hysteresis
4. If response feels delayed → Decrease hysteresis

### Step 3: Test Musical Settings
1. Try different scales to hear the difference
2. Use C Major for a familiar sound
3. Use Pentatonic for improvisation (always sounds musical)
4. Change root note to match your preferred key

## Troubleshooting

### Demo Version Issues
**Problem**: Demo won't start
- Check Python version (3.7+)
- Install missing packages: `pip install numpy tkinter`

**Problem**: No MIDI sound
- Install MIDI software (GarageBand, LoopMIDI, etc.)
- Connect virtual/hardware MIDI device
- Visual feedback will still work without MIDI

### Hardware Version Issues
**Problem**: "Sensor reader not available"
```bash
# Check if device is connected
ls /dev/tty*    # Look for your Arduino/USB device

# Check Python can access the device
python -c "from port_read import Reader; print('✅ Reader available')"
```

**Problem**: Lights don't respond to finger movement
1. Check sensor connections (wiggle wires)
2. Verify sensor values in raw data
3. Adjust threshold range (try 100-300)
4. Check sensor calibration

**Problem**: Lights trigger randomly or flicker
1. Increase hysteresis (15-30)
2. Check for electrical interference
3. Verify sensor mounting (not too loose/tight)
4. Check for damaged sensors

## Advanced Configuration

### Custom Thresholds per Hand
```python
# In the code, you can set different thresholds:
self.trigger_config = {
    'thresholds': {'flex': 200, 'press': 15},
    'hysteresis': {'flex': 10, 'press': 5},
    'trigger_sensors': {'l': 'flex', 'r': 'press'}  # Different sensors per hand
}
```

### Custom Musical Scales
```python
# In mapper.py, add new scales:
scales = {
    'major': [2, 2, 1, 2, 2, 2, 1],
    'minor': [2, 1, 2, 2, 1, 2, 2],
    'blues': [3, 2, 1, 1, 3, 2],        # Add blues scale
    'harmonic_minor': [2, 1, 2, 2, 1, 3, 1]  # Add harmonic minor
}
```

### Performance Optimization
- **Reduce update rate**: Change GUI update from 50ms to 100ms if needed
- **Adjust queue size**: Increase maxsize if you experience dropped data
- **Monitor CPU usage**: The demo should use <5% CPU on modern systems

## System Architecture

### Data Flow
```
Sensor → Trigger Strategy → Mapping Strategy → MIDI Output
                ↓
           Visual Display
```

### Key Components
1. **HysteresisTrigger**: Converts sensor data to discrete events
2. **BasicMapper**: Maps finger triggers to musical notes
3. **FingerLight**: Visual representation of trigger state
4. **GUI Application**: Coordinates everything with user controls

## Next Steps

### 1. Basic Usage
- Master the demo interface
- Understand threshold and hysteresis effects
- Try different musical settings

### 2. Hardware Integration
- Connect and calibrate your sensors
- Optimize settings for your specific hardware
- Test with actual music software

### 3. Customization
- Explore the codebase structure
- Try modifying musical scales
- Experiment with different trigger behaviors

### 4. Advanced Features
- Look at the strategy pattern implementation
- Consider adding new trigger strategies
- Explore integration with DAW software

## Support Resources

- **Code Documentation**: See `core/strategies/` for implementation details
- **Test Suite**: Run `pytest tests/` to verify functionality
- **Examples**: Check `examples/` directory for more applications
- **Architecture Overview**: See main README for system design

## File Reference

- `examples/ten_finger_demo.py` - Demo version (no hardware)
- `examples/ten_finger_gui.py` - Hardware version
- `test_basic_imports.py` - Verify system functionality
- `tests/test_trigger_strategies.py` - Unit tests
- `core/strategies/` - Core implementation
- `mapper.py` - Musical note mapping

**Ready to start?** Run `python test_basic_imports.py` to verify everything is working, then launch the demo!

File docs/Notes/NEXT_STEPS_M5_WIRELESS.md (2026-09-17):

# 🎯 GLUVN-M5 Wireless: Consolidated Next Steps

**Last Updated**: June 2026

**Focus**: Adapt legacy GLUVN Arduino code to M5Stick + wireless BLE

---

## Overview

This document consolidates all pending work across the project. The main goal is to complete the **wireless M5-GLUVN adaptation** and ensure all legacy code works seamlessly with BLE connectivity while maintaining compatibility with the original USB setup.

### Key Principles
- ✅ **Wireless First**: Primary target is M5Stick with BLE
- ✅ **USB Fallback**: Support USB serial for development/charging
- ✅ **No Code Duplication**: Reuse strategies and frameworks
- ✅ **Real Hardware**: All development/testing on actual M5Stick + PCB

---

## 🔴 CRITICAL PATH: Phase 1

### 1.1 Multiplexer Firmware Validation

**Tasks**:
- [x] **1.2.1** Test all 20 sensor channels (10 flex + 10 FSR) read correctly
  - Create a test to verify each channel
  - Check for channel cross-talk (one channel affecting another)
  - Validate 1000µs multiplexer settling time is sufficient
  
- [x] **1.2.2** Verify calibration data persists correctly across power cycles
  - Save calibration on M5 via NVS
  - Power cycle M5 and verify calibration loads
  - Test with different hand configurations
  
- [ ] **1.2.3** Performance validation on BLE link
  - Measure actual latency: sensor → M5 → BLE → PC
  - Compare BLE latency vs USB (should be <50ms typical)
  - Run `benchmark_bandwidth.py` in BLE mode for 1+ minute
  - Verify <1% packet loss

---

### 1.2 Complete BLE Integration for All Applications

**Tasks**:
- [ ] **1.1.1** Update `ten_finger_gui_with_sensors.py` to support BLE mode with command-line flag
  ```bash
  python examples/ten_finger_gui_with_sensors.py --ble
  python examples/ten_finger_gui_with_sensors.py --usb  # fallback
  ```
  - Add BLE device discovery UI (BleakScanner)
  - Add connection status indicator
  - Handle BLE disconnection gracefully
  
- [ ] **1.1.2** Create BLE wrapper for `Reader` class in `port_read.py`
  - Make Reader class detect and auto-select BLE vs USB
  - Implement fallback logic (try BLE, fall back to USB if unavailable)
  - Test with both left and right M5 devices simultaneously
  
- [ ] **1.1.3** Update `app_runner.py` to accept BLE mode parameter
  ```python
  AppRunner.run_app('base', config_path, use_ble=True)
  ```
  
- [ ] **1.1.4** Verify BLE calibration tool works end-to-end
  - Test `calibrate_eeprom_BLE.py` with actual M5Stick
  - Verify calibration data persists in M5 NVS
  - Confirm calibration loads on next boot

---

### 1.3 Update All Example Applications to Support BLE

**Examples to Update**:
- [ ] **1.3.1** `ten_finger_gui_with_modulation.py` → Add `--ble` flag
- [ ] **1.3.2** `ten_finger_gui_with_pitchbend.py` → Add `--ble` flag
- [ ] **1.3.3** `single_glove_stage_gui.py` → Add `--ble` flag (performance variant)
- [ ] **1.3.4** Create `examples/ten_finger_gui_ble_only.py` (optimized for wireless)

**Each example needs**:
- BLE device discovery
- Graceful connection/disconnection handling
- Status indicator (connected/searching/error)
- Clear error messages if BLE unavailable

---

## 🟠 HIGH PRIORITY: Phase 2

### 2.1 Configuration System for M5-Specific Hardware

**Tasks**:
- [ ] **2.1.1** Create `configs/m5_hardware_config.py` with M5-specific defaults
  ```python
  class M5HardwareConfig(BaseConfig):
      def __init__(self):
          super().__init__()
          self.adc_resolution = 12  # 4096 levels vs 10-bit original
          self.multiplexer_enabled = True
          self.settling_time_us = 100
          self.sensor_averaging = 2  # oversampling
          self.ble_mode = True
          self.ble_latency_compensation = True  # smooth out BLE jitter
  ```
  
- [ ] **2.1.2** Create presets for common M5-GLUVN scenarios
  - `configs/presets/m5_basic.json` - Simple flex trigger
  - `configs/presets/m5_modulation.json` - With volume/pitch control
  - `configs/presets/m5_dual_hand.json` - Optimized for two M5Sticks
  - `configs/presets/m5_performance.json` - High-performance stage mode

- [ ] **2.1.3** Update `__init__.py` to use M5-appropriate defaults
  - Check if running on M5 vs Arduino based on port names
  - Auto-load M5 config if M5 device detected

---

### 2.2 Optimize for BLE Latency & Jitter

**Tasks**:
- [ ] **2.2.1** Implement BLE latency compensation in `SensorProcessingThread`
  - Add predictive smoothing for jittery BLE data
  - Increase internal buffer to handle variable packet timing
  - Test with moving average of 2-3 frames
  
- [ ] **2.2.2** Create BLE-specific GUI update strategy
  - Use rolling buffer instead of single frame
  - Reduce GUI update rate to match typical BLE frame arrival (~100 Hz)
  - Add visual indicator of BLE data freshness
  
- [ ] **2.2.3** Battery monitoring
  - Read M5 battery level via M5Unified
  - Display battery % in GUI
  - Warn when battery <20%
  - Consider reducing BLE update rate when on battery saver mode

---

### 2.3 Multiplexer Documentation & Troubleshooting

**Tasks**:
- [ ] **2.3.1** Create detailed PCB assembly guide: `docs/PCB_ASSEMBLY.md`
  - Schematics with annotated part placement
  - Multiplexer channel-to-sensor mapping diagram
  - Wiring checklist (all 20 sensors)
  - Common soldering issues and fixes
  
- [ ] **2.3.2** Create multiplexer debugging guide: `docs/MULTIPLEXER_TROUBLESHOOTING.md`
  - How to test each MUX channel independently
  - Common failure modes (open/short circuits)
  - ADC reading ranges for healthy sensors
  - Settling time requirements and verification
  
- [ ] **2.3.3** Create filter network design document: `docs/FILTER_NETWORKS.md`
  - Derivation of 47K/100nF vs 10K/10nF values
  - Time constant calculations
  - PCB trace impedance considerations
  - When to adjust capacitor values

---

## 🟡 MEDIUM PRIORITY: Phase 3

### 3.1 Refactor Legacy Application Files
**Status**: Multiple `app_*.py` files have duplicated code

**Current Situation**:
- `app_10fig_accel.py` - Uses old AccelVolume approach
- `app_10fig_flex.py` - Old flex-only triggering
- `app_harmonizer.py` - Custom MovingWindow implementation
- `app_jacob_choir.py` - Choir modulation (different from current system)

**Tasks**:
- [ ] **3.1.1** Audit all `app_*.py` files for M5 compatibility
  - Identify which apps still work with USB
  - Which can be migrated to BLE easily
  - Which require significant refactoring

- [ ] **3.1.2** Migrate `app_harmonizer.py` to new modulation system
  - Extract chord logic into reusable mapper
  - Use CompositeModulation for multi-voice control
  - Update to use M5 built-in IMU
  
- [ ] **3.1.3** Update `app_jacob_choir.py` for M5 IMU
  - Adapt to use M5Stick's gyroscope/accelerometer
  - Test choir modulation with actual M5 hardware
  
- [ ] **3.1.4** Create unified launcher for all apps
  ```python
  # python run_app.py --app harmonizer --ble --hand r
  # python run_app.py --app choir --ble --hand l --config preset
  ```

---

### 3.2 Data Recording & Playback for M5-BLE
**Status**: Recording logic exists, but not BLE-optimized

**Tasks**:
- [ ] **3.2.1** Create BLE-specific data recorder
  - Record BLE frames directly (with sequence numbers for packet loss detection)
  - Add timestamp for each frame
  - Store metadata (hand, battery %, calibration data)
  - Compress recordings (BLE frames are small already)

- [ ] **3.2.2** Implement playback system
  - Replay recorded BLE sessions through GUI
  - Use timestamps to simulate real latency
  - Useful for debugging connection issues
  - Generate test datasets for algorithm development

- [ ] **3.2.3** Create analysis tools for BLE performance
  - Analyze packet loss patterns
  - Measure actual latency vs theoretical
  - Detect connection quality issues
  - Export metrics for reports

---

### 3.3 Performance Profiling for M5
**Status**: Bandwidth benchmark exists ✅, but CPU/memory profiling missing

**Tasks**:
- [ ] **3.3.1** Profile M5 CPU usage during operation
  - Monitor in Arduino firmware or via M5Unified
  - Report CPU % to GUI via BLE status message
  - Identify bottlenecks (multiplexer, BLE, sensor processing)
  
- [ ] **3.3.2** Profile memory usage on M5
  - Heap usage over time (detect memory leaks)
  - Stack depth for each thread
  - PSRAM usage if available
  
- [ ] **3.3.3** PC-side profiling for Python GUI
  - Profile latency of BLE frame processing
  - Identify GUI bottlenecks
  - Optimize PyQt5 rendering for real-time updates

---

## 🟢 MEDIUM-LOW PRIORITY: Phase 4

### 4.1 Advanced Features: M5-Specific Capabilities
**Status**: Not started

**Possibilities** (choose based on priority):

- [ ] **4.1.1** WiFi fallback mode
  - If BLE unreliable in environment, switch to WiFi MIDI
  - Useful for crowded 2.4 GHz environments
  - Lower latency than BLE

- [ ] **4.1.2** Gesture recognition using M5 IMU
  - Detect hand poses (closed fist, open hand, pointing)
  - Use as mode selector or expression control
  - Extends musical vocabulary

- [ ] **4.1.3** Multi-glove synchronization
  - Left and right M5 devices synchronize timing
  - Detect if one glove disconnects
  - Automatic re-sync when reconnecting

- [ ] **4.1.4** Machine learning calibration
  - Auto-detect flex sensor range on startup
  - Learn individual playing style
  - Adaptive trigger thresholds per performer

---

### 4.2 Alternative Connectivity Options
**Status**: BLE is primary, but alternatives could be useful

**Optional Tasks**:
- [ ] **4.2.1** Implement WiFi MIDI support (for unreliable BLE environments)
- [ ] **4.2.2** Add USB MIDI output to M5 firmware (USB as MIDI device)
- [ ] **4.2.3** Create network mode (OSC over UDP for remote playing)

---

## 🔵 LOW PRIORITY: Phase 5 (Future)

### 5.1 GUI Enhancements
- [ ] Visualize BLE signal strength
- [ ] Real-time IMU visualization (orientation, acceleration)
- [ ] Waveform display of sensor raw data
- [ ] Gesture recording and playback UI

### 5.2 Integration with DAWs
- [ ] Native VST plugin integration
- [ ] Ableton Live controller support
- [ ] Logic Pro compatibility
- [ ] ReWire support for multi-app sync

### 5.3 Mobile Companion App
- [ ] iOS/Android BLE controller
- [ ] Remote configuration and calibration
- [ ] Performance analytics dashboard

---

## 📚 DOCUMENTATION: Phase 6 (Ongoing, end of each feature)

### Critical Documentation Needs (Must Complete by Final Release)

- [ ] **6.1** `docs/BLE_SETUP.md` - Complete BLE connection guide
  - M5 device discovery
  - Pairing process
  - Connection troubleshooting
  - Multi-device setup (left + right)

- [ ] **6.2** `docs/M5_HARDWARE_GUIDE.md` - Complete hardware setup
  - M5Stick specs and pin assignments
  - PCB assembly with schematics
  - Sensor connections and wiring
  - Power management and charging

- [ ] **6.3** `docs/CALIBRATION_GUIDE_M5.md` - Wireless calibration
  - BLE calibration tool usage
  - Interpreting calibration values
  - Re-calibration procedures
  - Troubleshooting calibration issues

- [ ] **6.4** `docs/ARCHITECTURE_M5.md` - System architecture for wireless
  - Data flow diagram (sensor → M5 → BLE → PC)
  - Frame format specification
  - Latency analysis and optimization
  - Failure modes and recovery

- [ ] **6.5** `docs/PERFORMANCE_METRICS.md` - Benchmarks and profiling
  - Latency measurements (BLE vs USB)
  - Throughput and bandwidth usage
  - CPU/memory profiling results
  - Battery life estimates

- [ ] **6.6** `docs/FIRMWARE_DEVELOPMENT.md` - M5 firmware guide
  - Building and flashing firmware
  - BLE service implementation details
  - Adding new sensor types
  - Extending multiplexer support

- [ ] **6.7** `docs/TROUBLESHOOTING_M5_BLE.md` - Common issues
  - BLE connection failures
  - Multiplexer channel failures
  - Calibration issues
  - Performance problems
  - Known limitations

- [ ] **6.8** `docs/MIGRATION_FROM_ARDUINO.md` - For existing GLUVN users
  - What's different in M5-GLUVN
  - How to adapt existing code
  - Configuration file migration
  - Playing styles differences (BLE latency)

- [ ] **6.9** Update main READMEs
  - README.md - Add M5 compatibility note
  - README_M5_GLUVN.md - Ensure complete and current
  - Link all documentation appropriately

- [ ] **6.10** Code documentation
  - Docstrings for all BLE-related functions
  - Inline comments for multiplexer logic
  - API documentation for port_read_BLE
  - Examples in code comments

---

## ✅ Quick Reference: What's Already Done

### Architecture & Core Framework
- ✅ Core trigger strategies (HysteresisTrigger, MultiSensor, etc.)
- ✅ Modulation strategies (Volume, Pitch, Window, Choir)
- ✅ Visualization components (PyQt5 widgets)
- ✅ Configuration system (Base, Advanced configs)
- ✅ Unified app framework

### M5 Specific
- ✅ M5 firmware with BLE support (`sendsens.ino`)
- ✅ Custom PCB with CD4067 multiplexer
- ✅ BLE reader implementation (`port_read_BLE.py`)
- ✅ BLE calibration tool (`calibrate_eeprom_BLE.py`)
- ✅ Bandwidth benchmarking tool (`benchmark_bandwidth.py`)
- ✅ BLE device configuration (`__init__.py` with BLE names/UUIDs)

### Documentation
- ✅ README_WIRED.md (original Arduino version)
- ✅ README.md (wireless M5 version)
- ✅ Existing guides

---

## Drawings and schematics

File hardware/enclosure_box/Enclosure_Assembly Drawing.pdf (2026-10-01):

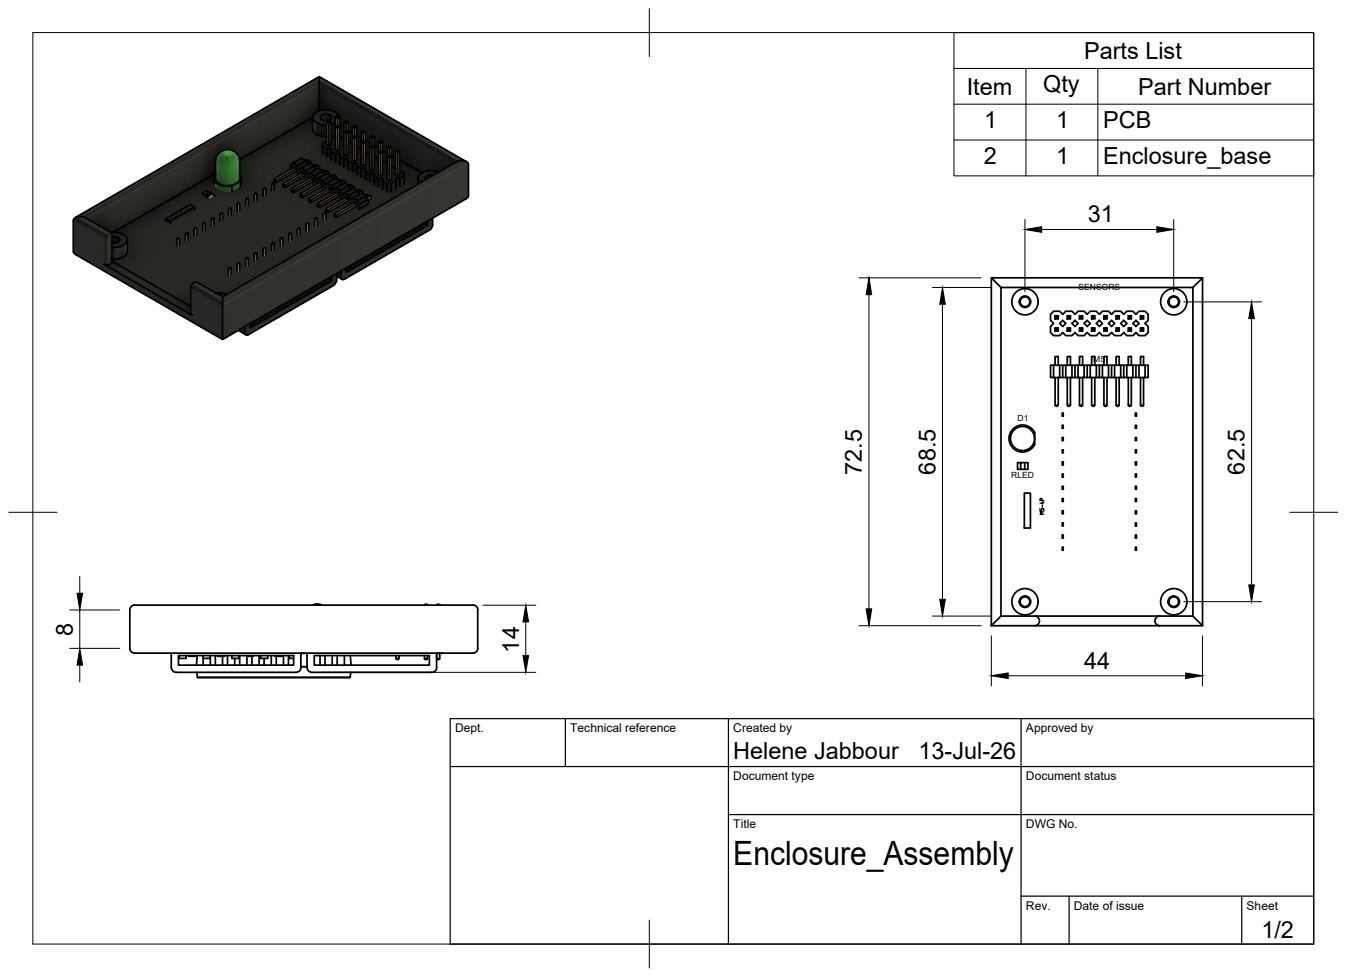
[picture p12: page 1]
D1 RLED; Parts List; Enclosure_base 72.5

Item | Qty | Part Number
1 | 1 | PCB

Dept. | Technical reference | Created by Helene Jabbour 13-Jul-26 | Approved by

Document type | Document status

Title Enclosure_Assembly | DWG No.

Rev. | Date of issue | Sheet 1/2

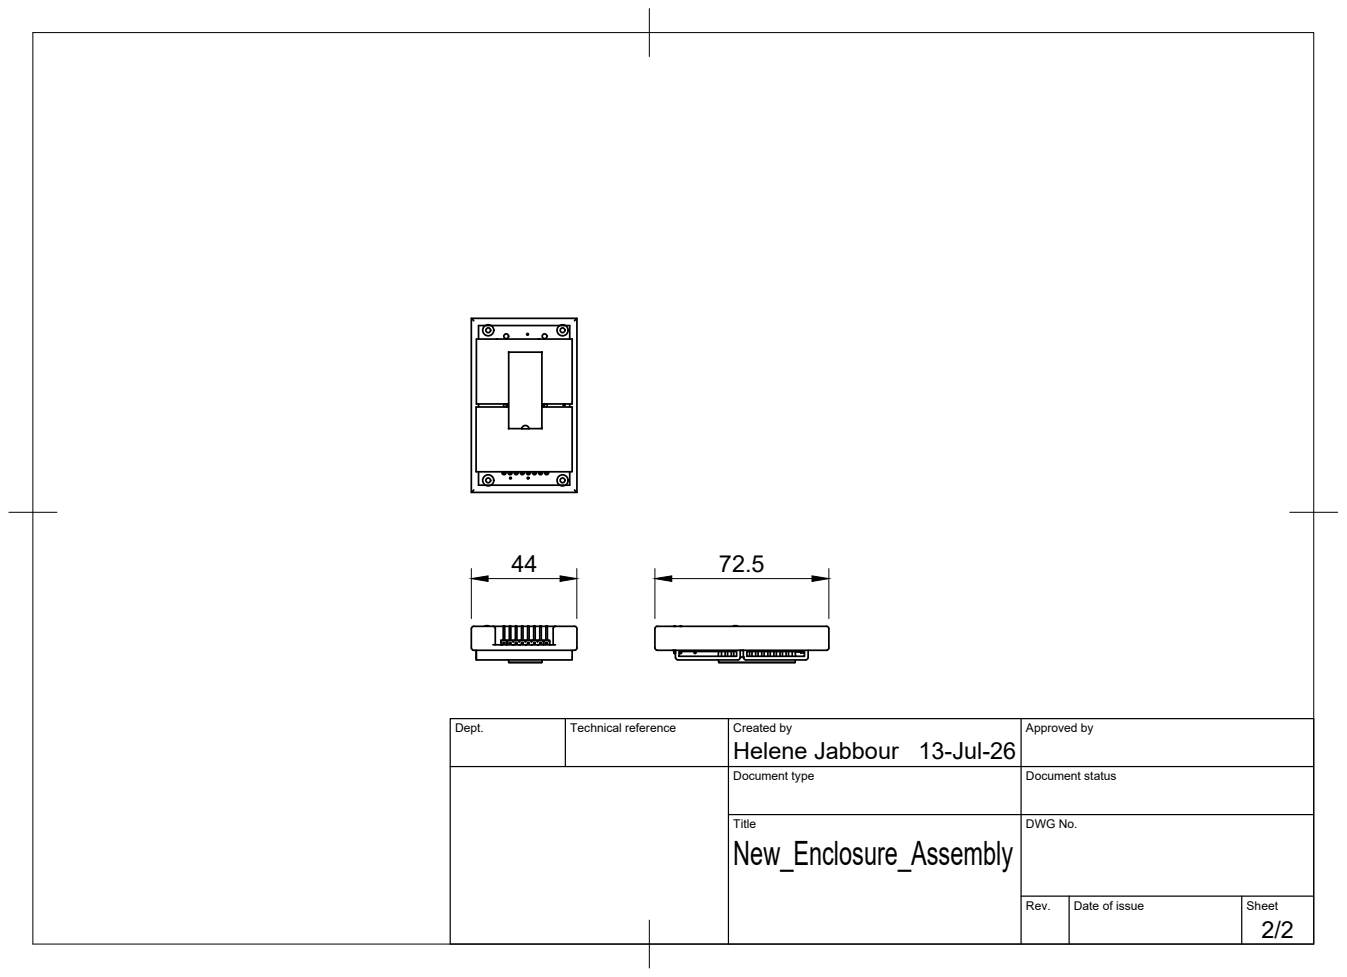
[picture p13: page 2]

Dept. | Technical reference | Created by Helene Jabbour 13-Jul-26 | Approved by

Document type | Document status

Title New_Enclosure_Assembly | DWG No.

Rev. | Date of issue | Sheet 2/2

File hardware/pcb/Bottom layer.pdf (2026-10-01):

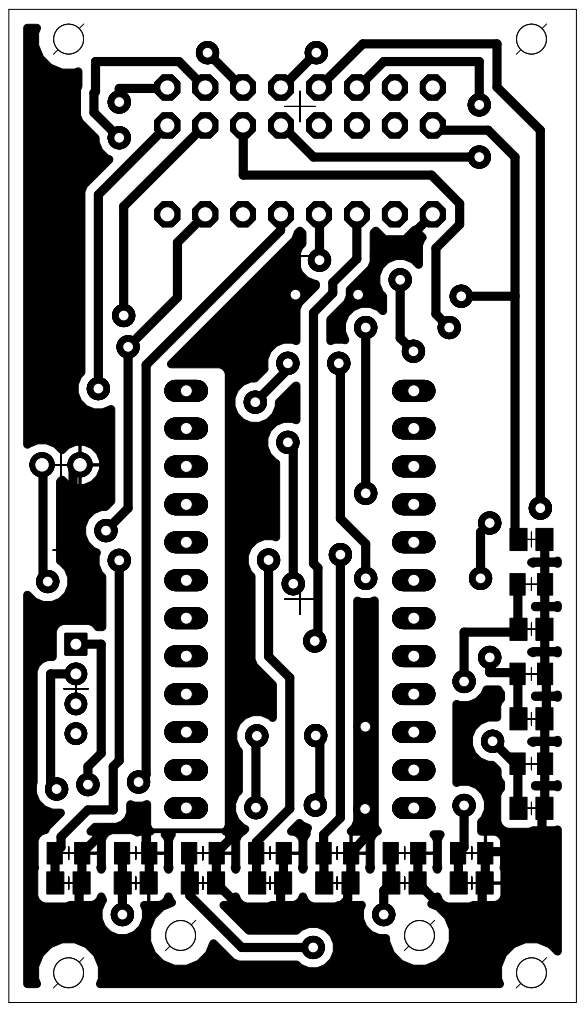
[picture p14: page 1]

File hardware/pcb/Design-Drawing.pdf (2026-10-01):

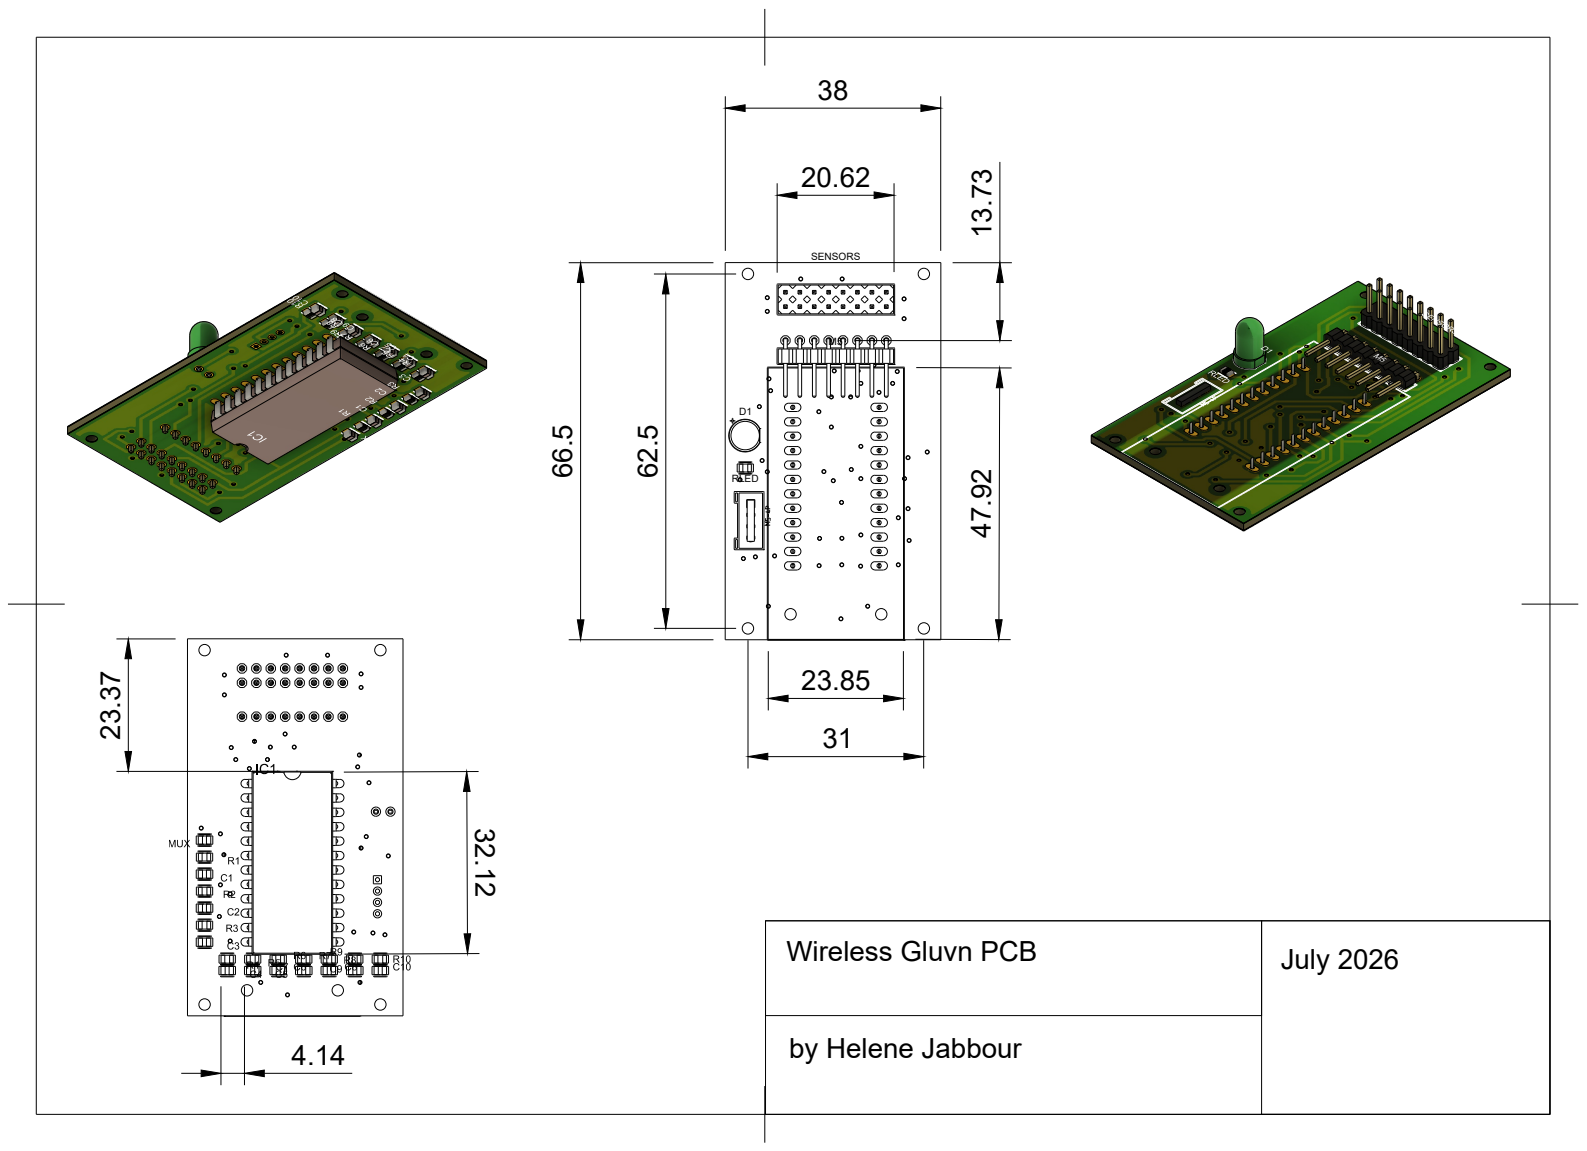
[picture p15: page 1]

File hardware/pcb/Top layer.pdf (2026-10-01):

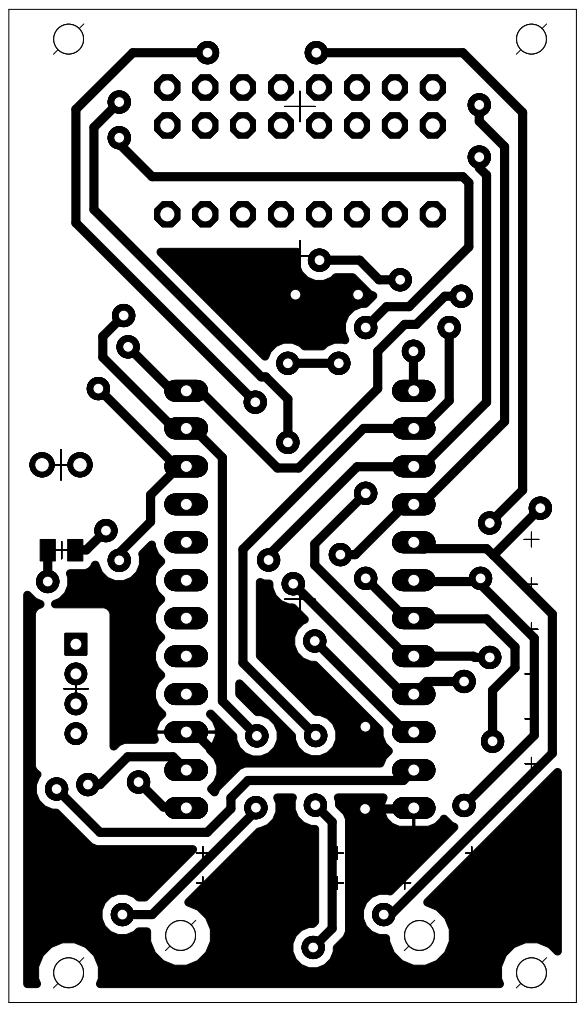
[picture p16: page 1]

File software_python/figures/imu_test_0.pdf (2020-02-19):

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

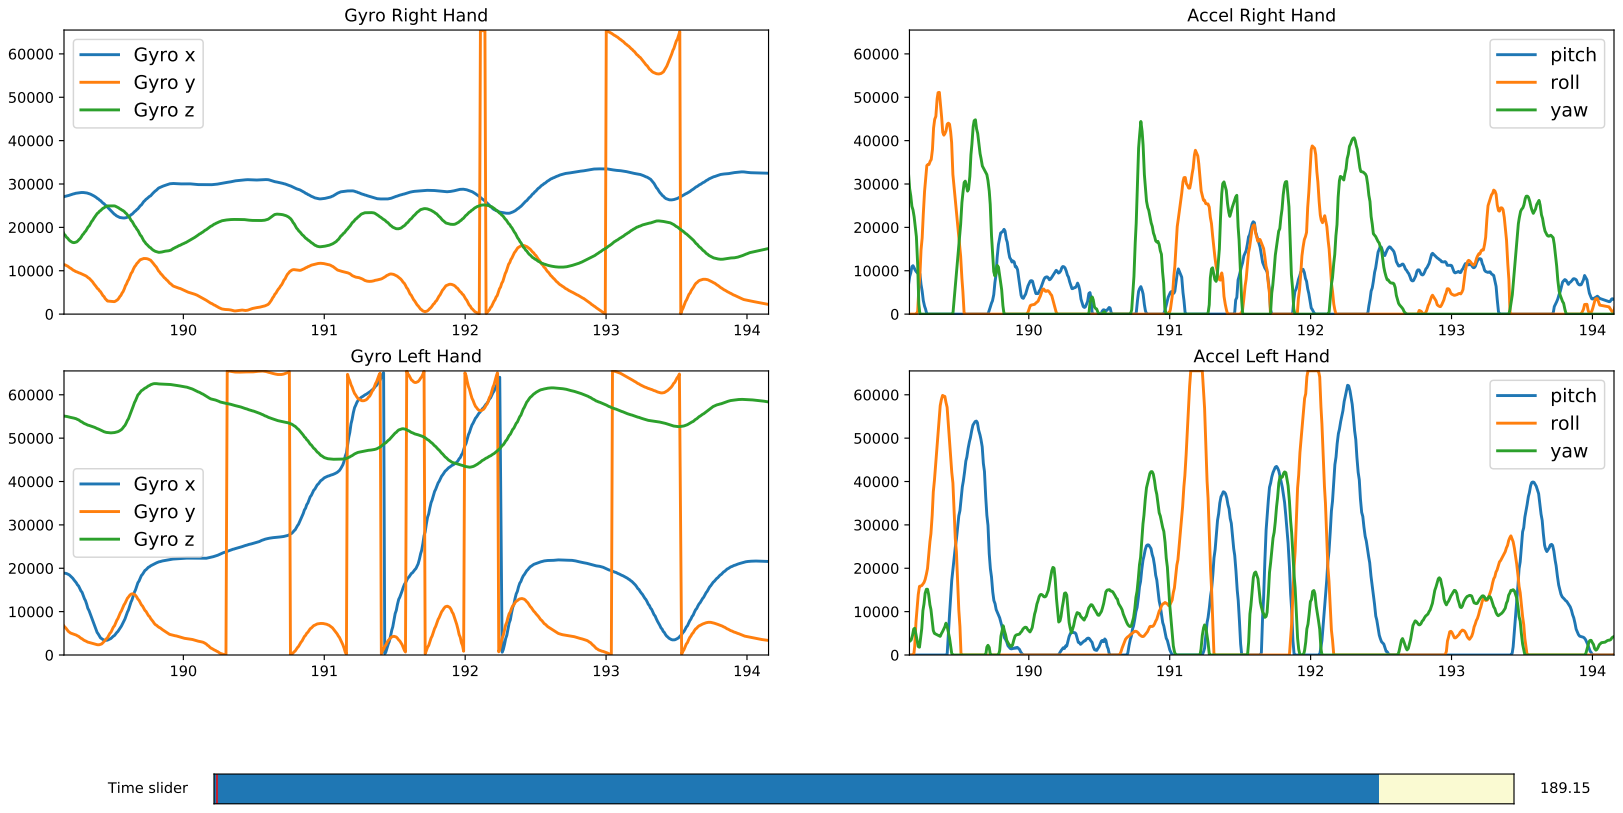
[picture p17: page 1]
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

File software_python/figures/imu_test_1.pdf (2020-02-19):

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

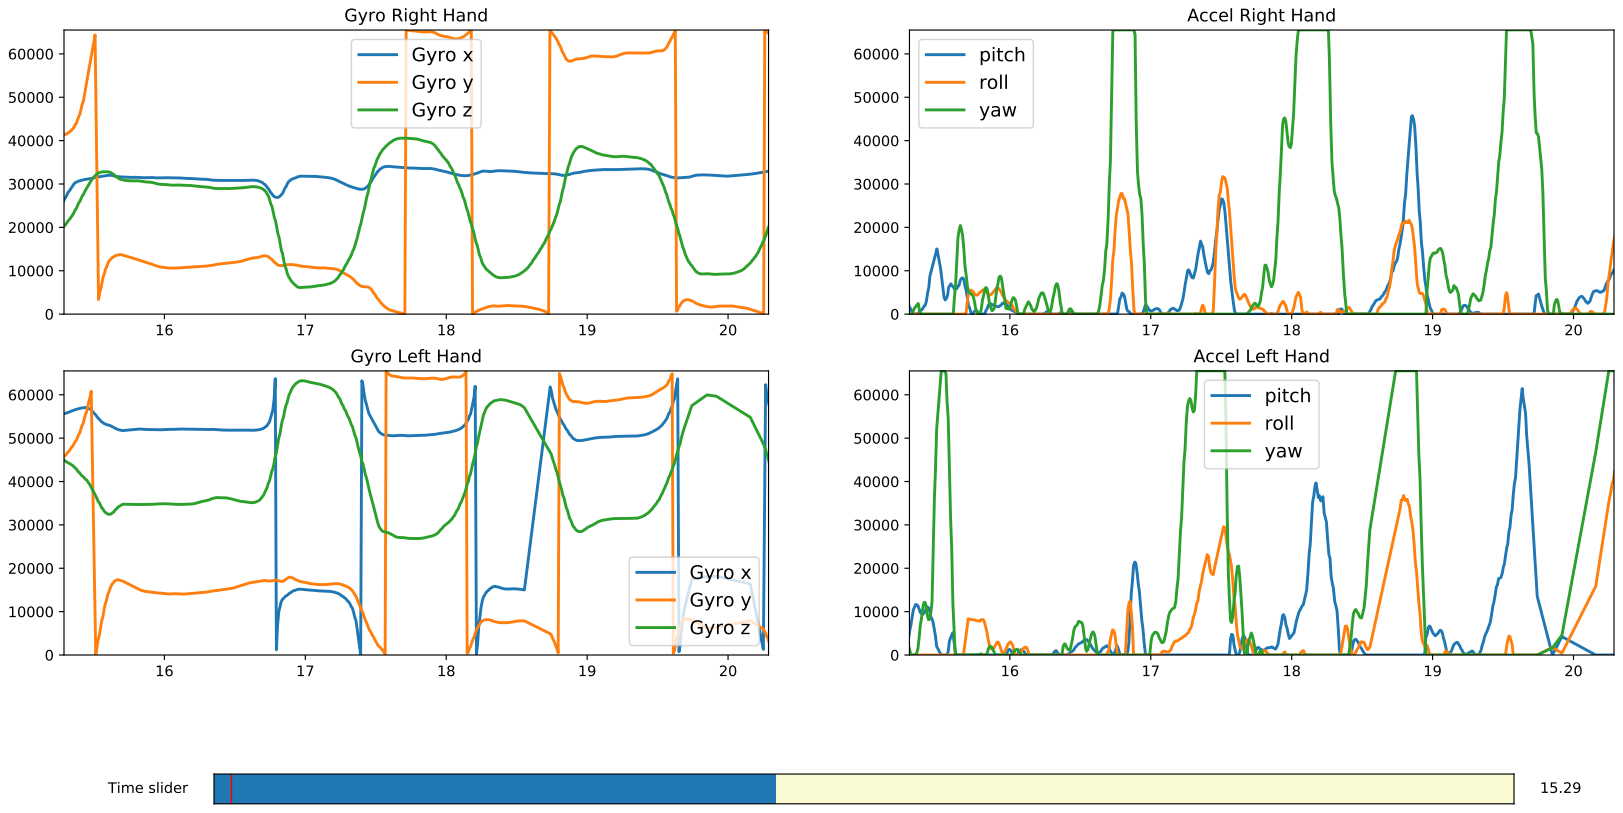
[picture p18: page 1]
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

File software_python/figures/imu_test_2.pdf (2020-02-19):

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

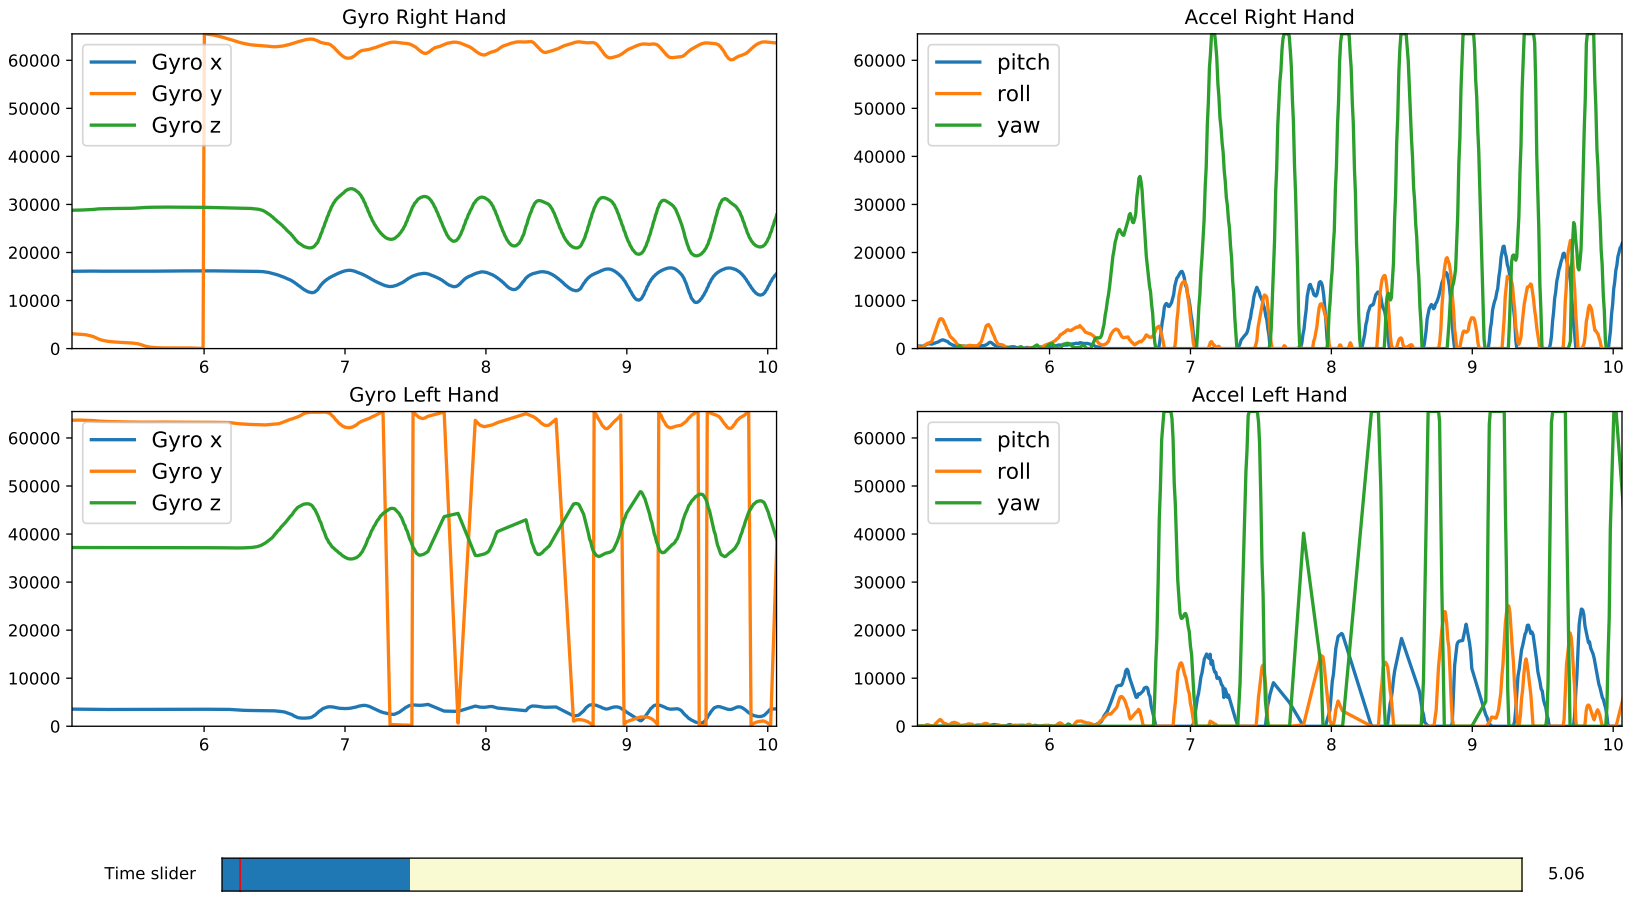
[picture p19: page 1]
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

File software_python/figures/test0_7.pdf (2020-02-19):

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

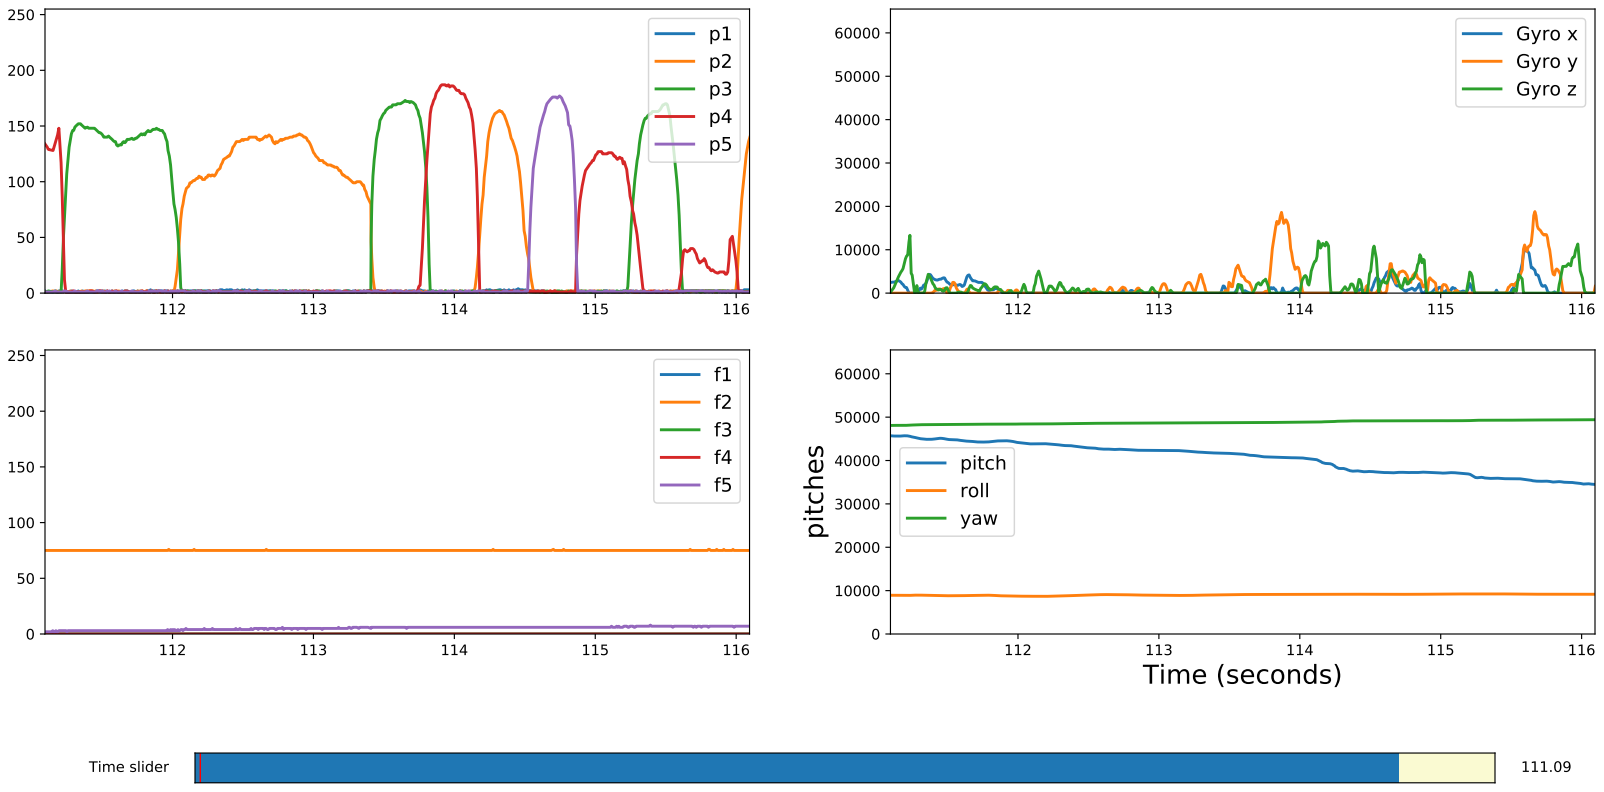
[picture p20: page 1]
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

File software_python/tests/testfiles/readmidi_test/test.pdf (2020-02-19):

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

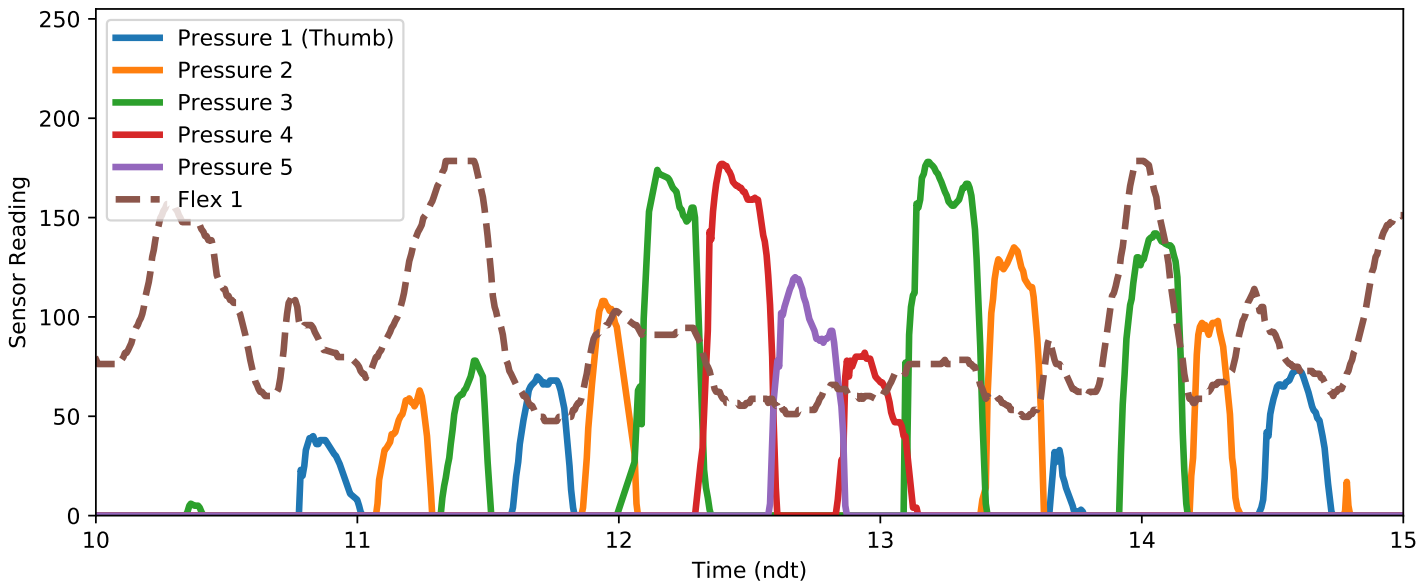
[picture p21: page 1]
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

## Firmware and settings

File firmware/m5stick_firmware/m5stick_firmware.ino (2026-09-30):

/*
 * Gluvn-M5 — M5StickC Plus 1.1
 * BLE NUS (Nordic UART Service) + USB Serial
 *
 * Hardware:
 *   5x FSR  on CD74HC4067 MUX CH0–4   (10K pull-down, 103 cap)
 *   5x Flex on CD74HC4067 MUX CH5–9   (47K pull-down, 104 cap)
 *   Built-in IMU (BMI270 / MPU6886) via M5Unified
 *
 * Payload (normal mode, base len=29; +8 QUAT, +8 NAV_QUAT, +19 MOTION, any combination):
 *   [hand:1B] [flags:1B] [seq:1B] [device_us:4B] [yaw:2B] [pitch:2B] [roll:2B]
 *   [imu0:2B][imu1:2B][imu2:2B] [flex0-4:5B] [fsr0-4:5B]
 *   [qw,qx,qy,qz:2B each]     <- QUAT_STREAM_ON only
 *   [nqw,nqx,nqy,nqz:2B each] <- NAV_QUAT_STREAM_ON only
 *   [velX,velY,velZ,posX,posY,posZ,laX,laY,laZ:2B each][zupt_quality:1B] <- MOTION_STREAM_ON only
 *
 *   vel/pos: int16, world-frame, /32767*RANGE recovers float (8.0 m/s, 2.0 m
 *   — MOTION_VEL_RANGE_MPS/MOTION_POS_RANGE_M). la (linear accel): int16,
 *   world-frame, gravity already subtracted by NavEKF::getWorldAcceleration()
 *   — zero at rest, /32767*LIN_ACCEL_RANGE_MPS2 (+-4g) recovers m/s^2.
 *   zupt_quality: uint8, NavEKF::getZuptMahalanobis() (chi-square fit for the
 *   last ZUPT candidate; near 0 = confident stationary fit) clamped to
 *   [0,ZUPT_MAHALANOBIS_CAP] and scaled to [0,254]; 255 = "never computed
 *   yet" sentinel, kept out of the numeric range on purpose. Soft-scaling
 *   companion to the isZuptStarved flag bit. Position is relative
 *   displacement since the last navEkf.reset() (RESET_POSITION), not an
 *   absolute session position.
 *
 *   flags (byte 2, always present): bit0=calibration_mode, bit1=send_quat,
 *   bit2=send_nav_quat, bit3=send_motion, bit4=isArmed, bit5=isZuptActive,
 *   bit6=isZuptStarved, bit7=low_battery. Bits 4-6 are meaningful ONLY when
 *   bit3 is set — NavEKF may not even be running otherwise (see
 *   navEkfNeeded gating); a host should ignore bits 4-6 when bit3 is 0.
 *   isArmed clear = vel/pos/lin_accel not yet trustworthy (~0.3s re-arm
 *   window) — hard-gate on this bit.
 *
 *   Frame length alone does NOT determine which optional blocks are present
 *   (several base+block combinations share a total length) — a host must
 *   decode flags first and use that, not length, to pick the struct; length
 *   is still checked against what flags imply, as an integrity cross-check.
 *
 *   payload (calibration mode, len=39, +8/+8/+19 for the same additions):
 *   same 19-byte header; sensors sent as raw uint16 [0,4095] instead of the
 *   8-bit calibrated form; same optional trailing blocks as above.
 *
 * Serial / BLE commands (ASCII lines, '\n'-terminated):
 *   HAND_R / HAND_L       set active hand
 *   CAL_START / CAL_STOP  enter/exit calibration mode (raw 16-bit output)
 *   RAW_MODE / CAL_MODE   print raw/calibrated values to serial; pauses binary stream
 *   NORMAL_MODE           resume binary streaming
 *   RESET_YAW             display-only: zero ahrs's yaw/pitch/roll readout at current
 *                         heading. Does NOT touch ahrs's quaternion or NavEKF's world
 *                         frame. See RESET_POSITION / RECALIBRATE_GYRO for those.
 *   RESET_POSITION        zero navEkf_'s position AND velocity; re-arms from the next
 *                         confirmed-stationary sample. On-demand drift clear — position
 *                         is deliberately not auto-reset by ZUPT. Trigger at rest.
 *   QUAT_STREAM_ON/OFF    include Mahony qw,qx,qy,qz in every frame. Opt-in,
 *                         mode-independent.
 *   NAV_QUAT_STREAM_ON/OFF include NavEKF qw,qx,qy,qz in every frame. Opt-in.
 *   MOTION_STREAM_ON/OFF  include world-frame vel+pos+lin_accel+zupt_quality in every
 *                         frame (+19B), sets flags bits 4-6 meaningfully. Opt-in,
 *                         composable with QUAT/NAV_QUAT/USE_GYRO.
 *   USE_GYRO_ON/OFF       telemetry encoding only: selects whether imu0/1/2 slots carry
 *                         gyro or accel counts. Does not gate estimator input — Mahony
 *                         and NavEKF always consume both regardless.
 *   RECALIBRATE_GYRO      re-run stationary startup gyro calibration on demand.
 *                         Resets AHRS's residual-bias tracker and re-anchors yaw.
 *   NAV_DIAG_ON/OFF       text-only per-sample nav estimator diagnostics (10 Hz;
 *                         requires binary streaming off).
 *   SYS_DIAG_ON/OFF       text-only system/stability diagnostics (1 Hz; requires
 *                         binary streaming off): reset reason, uptime, heap, stack
 *                         high-water mark, EKF/loop/calib timing, IMU sample counts,
 *                         dt extremes, NaN/Inf counters, quaternion norms, covariance
 *                         range + blowup tripwire, battery.
 *   STATUS                one-shot SYS_DIAG line, independent of the toggle above —
 *                         still requires binary streaming off.
 *   DIAG_RESET_MAX        clear since-boot diagnostic maxes/counts. Does not touch
 *                         estimator state or cumulative identity counters.
 *   PREFS_SAVE            persist flex/press/accel calibration to NVS. Gyro bias is
 *                         never persisted (runtime-only, always).
 *   SET_CAL:H:TYPE:v0,v1,v2,v3,v4   (flex/press: 5 comma-separated ints)
 *   SET_CAL:H:ACCEL_BIAS:ax,ay,az   (3 floats, g)
 *     H = R | L
 *     TYPE = MIN_FLEX | MAX_FLEX | MIN_PRESS | MAX_PRESS | ACCEL_BIAS
 *   GYRO_BIAS is intentionally NOT host-settable: it is solved exclusively by
 *   RECALIBRATE_GYRO (runStartupGyroCalibration), session-only, never persisted.
 *   SET_CAL:H:GYRO_BIAS is still accepted but rejected as a stub for compatibility.
 */

#include <M5Unified.h>
#include <Preferences.h>
#include <NimBLEDevice.h>
#include <freertos/FreeRTOS.h>
#include <freertos/queue.h>
#include <esp_task_wdt.h>  // reset during the blocking gyro-calibration loop
#include <string.h>        // memcpy
#include "calibration.h"   // generated by calibrate_eeprom.py — NVS fallback defaults only

#include "MahonyAHRS.h"
#include "NavEKF.h"        // position/velocity — owned by firmware, not MahonyAHRS
#include "Diagnostics.h"   // all firmware/estimator diagnostics

#define NUM_SENSORS 5

// Nordic UART Service UUIDs
#define NUS_SERVICE_UUID  "6E400001-B5A3-F393-E0A9-E50E24DCCA9E"
#define NUS_RX_CHAR_UUID  "6E400002-B5A3-F393-E0A9-E50E24DCCA9E"
#define NUS_TX_CHAR_UUID  "6E400003-B5A3-F393-E0A9-E50E24DCCA9E"

// CD74HC4067 MUX pins
const int MUX_SIG       = 36;
const int MUX_S[4]      = {26, 32, 33, 0};
const int MUX_SETTLE_US = 50;
const int MUX_AVG_READS = 2;   // oversampling per channel

// Loop timing
const unsigned long SENSOR_INTERVAL_MS  = 1000 / 120;   // 120 Hz target
const uint32_t      SENSOR_INTERVAL_US  = SENSOR_INTERVAL_MS * 1000UL;
const float         MAX_NAV_GAP_SEC     = 0.5f;   // discard pathological gaps; never compress time
const unsigned long DISPLAY_INTERVAL_MS = 200;    // 5 Hz

// Power management
const uint8_t  DISPLAY_BRIGHTNESS_ACTIVE = 100;
const uint8_t  DISPLAY_BRIGHTNESS_DIM    = 100;
const unsigned long DISPLAY_DIM_AFTER_MS = 15000;
const unsigned long BATTERY_POLL_MS      = 5000;
const int      LOW_BATTERY_PCT           = 15;

const uint8_t FRAME_SYNC0 = 0xA5;
const uint8_t FRAME_SYNC1 = 0x5A;

// CRC16-CCITT (poly 0x1021, init 0xFFFF) over the payload only.
uint16_t crc16_ccitt(const uint8_t* data, size_t len) {
  uint16_t crc = 0xFFFF;
  for (size_t i = 0; i < len; i++) {
    crc ^= (uint16_t)data[i] << 8;
    for (int b = 0; b < 8; b++) {
      crc = (crc & 0x8000) ? (crc << 1) ^ 0x1021 : (crc << 1);
    }
  }
  return crc;
}

const unsigned long USB_BAUD = 500000;  // keep in sync with __init__.py on the host side

// -------------------------------------------------------
// Runtime config
// -------------------------------------------------------
char hand                 = 'r';
bool streamGyroInImuSlots = false;   // telemetry encoding only — see USE_GYRO_ON/OFF doc above
bool send_quat            = false;   // QUAT_STREAM_ON/OFF
bool send_nav_quat        = false;   // NAV_QUAT_STREAM_ON/OFF
bool calibration_mode     = false;
bool write_binary         = true;
int  print_mode           = 0;       // 0=off, 1=raw, 2=calibrated
bool send_motion          = false;   // MOTION_STREAM_ON/OFF
bool gyroCalibToggle      = false;   // flips after each completed gyro calibration
// nav_diagnostics, sys_diagnostics, and diagnostic counters/printers live in Diagnostics.h

const size_t FLAGS_LEN           = 1;    // always-present stream-flags byte
const size_t SAMPLE_PAYLOAD_LEN  = 28;   // normal-mode payload bytes (excludes flags byte)
const size_t CAL_PAYLOAD_LEN     = 38;   // calibration-mode payload bytes (excludes flags byte)
const size_t QUAT_EXTRA_LEN      = 8;    // 4x int16 (qw,qx,qy,qz)
const size_t NAV_QUAT_EXTRA_LEN  = 8;    // 4x int16 (nqw,nqx,nqy,nqz)
const size_t MOTION_EXTRA_LEN    = 19;   // 6x int16 (vel+pos) + 3x int16 (lin accel) + 1x uint8 (zupt quality)
const size_t MAX_PAYLOAD_LEN     = FLAGS_LEN + CAL_PAYLOAD_LEN + QUAT_EXTRA_LEN + NAV_QUAT_EXTRA_LEN + MOTION_EXTRA_LEN;  // 74

const float MOTION_VEL_RANGE_MPS = 8.0f;
const float MOTION_POS_RANGE_M   = 2.0f;
const float LIN_ACCEL_RANGE_MPS2 = 4.0f * G_MS2;  // +-4g headroom for a gesture strike, encoding-only
const float ZUPT_MAHALANOBIS_CAP = 64.0f;         // 4x NavEKF's own zuptGateChiSq_ (16.0)

const size_t BUNDLE_FRAMES   = 1;
const size_t BUNDLE_BUF_SIZE = 3 + MAX_PAYLOAD_LEN * BUNDLE_FRAMES + 2;  // sync+len, payload, crc16

uint8_t bundleBuffer[MAX_PAYLOAD_LEN * BUNDLE_FRAMES];  // raw payloads only — header/CRC added at flush
uint8_t bundledFrameCount = 0;
size_t  bundleUnitLen = 0;

// -------------------------------------------------------
// Sensor data
// -------------------------------------------------------
uint16_t flexValues[NUM_SENSORS], fsrValues[NUM_SENSORS];
float ax, ay, az;          // accel (g,  M5Unified +-2g)
float gx, gy, gz;          // gyro  (deg/s, +-2000)
float roll, pitch, yaw;    // attitude (deg)
uint16_t ax_cal, ay_cal, az_cal;
uint16_t gx_cal, gy_cal, gz_cal;
uint16_t roll_cal, pitch_cal, yaw_cal;

uint32_t      nextSampleUs      = 0;   // deadline scheduler — absolute time of next sample
uint32_t      lastSampleUs      = 0;   // for dt computation
unsigned long lastDisplayMillis = 0;
bool  dispEverDrawn   = false;
bool  dispBleConn     = false;
char  dispHand        = 0;
int   dispBattery     = -1;
bool  dispCalibMode   = false;
bool  dispResetNotice = false;
uint8_t dispNavState  = 255;
int   dispPitch10     = 0;
int   dispRoll10      = 0;
int   dispYaw10       = 0;
int   dispDt10        = -1;
bool  navEkfNeeded    = false;
unsigned long resetNoticeUntilMs = 0;
unsigned long lastRawPrintMillis = 0;
const unsigned long RAW_PRINT_INTERVAL_MS = 200;   // 5 Hz — readable in serial monitor
uint8_t       frame_seq = 0;   // wrapping frame counter for loss detection
MahonyAHRS ahrs;   // gx,gy,gz in deg/s; ax,ay,az in g — matches M5.Imu.getImuData() units
NavEKF navEkf;     // position/velocity/navigation biases

// -------------------------------------------------------
// Calibration (RAM mirrors of NVS)
// -------------------------------------------------------
int L_MIN_FLEX_RAM[NUM_SENSORS],  L_MAX_FLEX_RAM[NUM_SENSORS];
int L_MIN_PRESS_RAM[NUM_SENSORS], L_MAX_PRESS_RAM[NUM_SENSORS];
int R_MIN_FLEX_RAM[NUM_SENSORS],  R_MAX_FLEX_RAM[NUM_SENSORS];
int R_MIN_PRESS_RAM[NUM_SENSORS], R_MAX_PRESS_RAM[NUM_SENSORS];
int *MIN_FLEX, *MAX_FLEX, *MIN_PRESS, *MAX_PRESS;
float ACTIVE_GYRO_BIAS[3] = {0.0f, 0.0f, 0.0f};
float L_ACCEL_BIAS_RAM[3] = {0, 0, 0};
float R_ACCEL_BIAS_RAM[3] = {0, 0, 0};
float *ACCEL_BIAS;

Preferences prefs;

// -------------------------------------------------------
// BLE
// -------------------------------------------------------
NimBLEServer*         bleServer = nullptr;
NimBLECharacteristic* txChar    = nullptr;
NimBLECharacteristic* rxChar    = nullptr;

#define BLE_CMD_QUEUE_LEN 4
#define BLE_CMD_MAX_LEN   64
struct BleCmdMsg { char text[BLE_CMD_MAX_LEN]; };
QueueHandle_t bleCommandQueue = nullptr;
bool          bleConnected    = false;

int           cachedBatteryPct   = 100;
bool          lowBatteryFlag     = false;
unsigned long lastBatteryPollMs  = 0;
unsigned long lastActivityMs     = 0;
bool          displayDimmed      = false;

void processCommand(String cmd);
void runStartupGyroCalibration();

class ConnCallbacks : public NimBLEServerCallbacks {
  void onConnect(NimBLEServer* server, NimBLEConnInfo& connInfo) override {
    bleConnected = true;
    server->updateConnParams(connInfo.getConnHandle(), 8, 8, 0, 400);
  }
  void onDisconnect(NimBLEServer* server, NimBLEConnInfo& connInfo, int reason) override {
    bleConnected = false;
    NimBLEDevice::startAdvertising();
  }
};

class RxCallbacks : public NimBLECharacteristicCallbacks {
  // BLE writes are queued and drained in loop(), never run inline in this
  // callback — keeps command handling off the NimBLE stack's task/stack.
  void onWrite(NimBLECharacteristic* c, NimBLEConnInfo& connInfo) override {
    std::string v = c->getValue();
    BleCmdMsg msg;
    strncpy(msg.text, v.c_str(), BLE_CMD_MAX_LEN - 1);
    msg.text[BLE_CMD_MAX_LEN - 1] = '\0';
    xQueueSend(bleCommandQueue, &msg, 0);   // non-blocking; drops if the queue is full
  }
};

// -------------------------------------------------------
// Calibration — NVS
// -------------------------------------------------------
void saveCalibrationToPrefs() {
  prefs.begin("gluvn", false);
  for (int i = 0; i < NUM_SENSORS; i++) {
    prefs.putInt(("RNF"+String(i)).c_str(), R_MIN_FLEX_RAM[i]);
    prefs.putInt(("RXF"+String(i)).c_str(), R_MAX_FLEX_RAM[i]);
    prefs.putInt(("RNP"+String(i)).c_str(), R_MIN_PRESS_RAM[i]);
    prefs.putInt(("RXP"+String(i)).c_str(), R_MAX_PRESS_RAM[i]);
    prefs.putInt(("LNF"+String(i)).c_str(), L_MIN_FLEX_RAM[i]);
    prefs.putInt(("LXF"+String(i)).c_str(), L_MAX_FLEX_RAM[i]);
    prefs.putInt(("LNP"+String(i)).c_str(), L_MIN_PRESS_RAM[i]);
    prefs.putInt(("LXP"+String(i)).c_str(), L_MAX_PRESS_RAM[i]);
  }
  for (int i = 0; i < 3; i++) {
    // Gyro bias deliberately NOT persisted — ACTIVE_GYRO_BIAS is runtime-only by design.
    prefs.putFloat(("RAB"+String(i)).c_str(), R_ACCEL_BIAS_RAM[i]);
    prefs.putFloat(("LAB"+String(i)).c_str(), L_ACCEL_BIAS_RAM[i]);
  }
  prefs.end();
  Serial.println("PREFS_SAVED");
}
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
void loop() {
  diagLoopTimingBegin();

  M5.update();

  static bool btnHoldHandled = false;
  static bool btnPressSeen = false;
  if (M5.BtnA.isPressed()) {
    btnPressSeen = true;
    if (M5.BtnA.pressedFor(1000) && !btnHoldHandled) {
      btnHoldHandled = true;
      runStartupGyroCalibration();
    }
  } else if (btnPressSeen) {
    if (!btnHoldHandled) {
      resetPoseFromButton();
    }
    btnPressSeen = false;
    btnHoldHandled = false;
  }

  while (Serial.available()) {
    char c = (char)Serial.read();
    if (c == '\n') {
      commandComplete = true;
    } else if (serialCmdLen < sizeof(serialCmdBuf) - 1) {
      serialCmdBuf[serialCmdLen++] = c;
    }
    // else: overlong line — drop the char rather than grow unbounded
  }
  if (commandComplete) {
    serialCmdBuf[serialCmdLen] = '\0';
    processCommand(String(serialCmdBuf));
    serialCmdLen = 0;
    commandComplete = false;
  }

  BleCmdMsg bleMsg;
  while (xQueueReceive(bleCommandQueue, &bleMsg, 0) == pdTRUE) {
    processCommand(String(bleMsg.text));
  }

  // NavEKF is needed by any consumer of nav output: binary motion, NavEKF
  // quaternion telemetry, or either diagnostic stream. Reset once on a
  // rising edge so the 0.3s arm window starts fresh, not from stale state.
  static bool navEkfWasNeeded = false;
  // Diagnostics (nav_diagnostics/sys_diagnostics) intentionally excluded:
  // they're an offline debugging aid, not a normal-operation data path.
  // Estimators now wake only for actual consumers (motion/nav_quat stream).
  navEkfNeeded = send_motion || send_nav_quat;
  if (navEkfNeeded && !navEkfWasNeeded) {
    navEkf.reset();
  }
  navEkfWasNeeded = navEkfNeeded;

  unsigned long now  = millis();   // 10 Hz display timer
  uint32_t      nowUs = micros();  // 100 Hz sample deadline scheduler

  if ((int32_t)(nowUs - nextSampleUs) >= 0) {
    if ((int32_t)(nowUs - nextSampleUs) > (int32_t)(3 * SENSOR_INTERVAL_US)) {
      nextSampleUs = nowUs;
    }
    nextSampleUs += SENSOR_INTERVAL_US;

    // A missed IMU sample no longer skips the whole loop — MUX reads, frame
    // send, and display still run this tick on the last good sample; only
    // the block that would consume a fresh sample is skipped.
    if (M5.Imu.update()) {
      diagNoteImuFresh();

      auto imu = M5.Imu.getImuData();
      uint32_t sampleUs = micros();
      float dt = (float)(sampleUs - lastSampleUs) / 1e6f;
      lastSampleUs = sampleUs;
      bool usableDt = dt > 0.0f && dt <= MAX_NAV_GAP_SEC;
      if (!usableDt) diagNoteDt(dt, false);

      bool gyroFinite  = isfinite(imu.gyro.x)  && isfinite(imu.gyro.y)  && isfinite(imu.gyro.z);
      bool accelFinite = isfinite(imu.accel.x) && isfinite(imu.accel.y) && isfinite(imu.accel.z);
      diagNoteRawGyro(imu.gyro.x, imu.gyro.y, imu.gyro.z);
      diagNoteRawAccel(imu.accel.x, imu.accel.y, imu.accel.z);

      // A non-finite sample is dropped here rather than fed downstream —
      // neither Mahony nor NavEKF recovers from a NaN state on its own.
      if (gyroFinite && accelFinite) {
        ax = imu.accel.x - ACCEL_BIAS[0];
        ay = imu.accel.y - ACCEL_BIAS[1];
        az = imu.accel.z - ACCEL_BIAS[2];
        gx = imu.gyro.x  - ACTIVE_GYRO_BIAS[0];
        gy = imu.gyro.y  - ACTIVE_GYRO_BIAS[1];
        gz = imu.gyro.z  - ACTIVE_GYRO_BIAS[2];
      }

      if (usableDt && gyroFinite && accelFinite) {
        diagNoteDt(dt, true);

        // Mahony now gated the same as NavEKF: its output (yaw/pitch/roll,
        // quaternion, gyro bias feed into NavEKF) has no consumer unless
        // something needs nav output. Previously ran unconditionally at
        // 100 Hz regardless of BLE-connected/streaming state.
        if (navEkfNeeded) {
          ahrs.updateIMU(gx, gy, gz, ax, ay, az, dt);
          ahrs.getEuler(yaw, pitch, roll);

          float navQ0, navQ1, navQ2, navQ3;
          ahrs.getQuaternion(navQ0, navQ1, navQ2, navQ3);
          diagNoteMahonyQuat(navQ0, navQ1, navQ2, navQ3);

          float navBgx, navBgy, navBgz;
          ahrs.getGyroBias(navBgx, navBgy, navBgz);

          diagEkfTimingBegin();
          navEkf.update(gx, gy, gz, ax, ay, az, dt,
                        navQ0, navQ1, navQ2, navQ3,
                        navBgx, navBgy, navBgz,
                        ahrs.getAccelConfidence());
          diagEkfTimingEnd();
          diagNoteNavEkfState(navEkf);

          diagPrintNavLineIfDue(ahrs, navEkf, ax, ay, az, roll, pitch, write_binary, sampleUs);
        }
      }
    } else {
      diagNoteImuMissed();
    }

    yaw_cal   = (uint16_t)constrain((yaw   + 180.0f) * 32767.0f / 180.0f, 0.0f, 65535.0f);
    pitch_cal = (uint16_t)constrain((pitch + 90.0f)  * 32767.0f / 180.0f, 0.0f, 65535.0f);
    roll_cal  = (uint16_t)constrain((roll  + 180.0f) * 32767.0f / 180.0f, 0.0f, 65535.0f);

    ax_cal = (uint16_t)constrain((ax + 2.0f) * 16383.5f, 0.0f, 65535.0f);
    ay_cal = (uint16_t)constrain((ay + 2.0f) * 16383.5f, 0.0f, 65535.0f);
    az_cal = (uint16_t)constrain((az + 2.0f) * 16383.5f, 0.0f, 65535.0f);

    gx_cal = (uint16_t)constrain((gx + 2000.0f) * 65535.0f / 4000.0f, 0.0f, 65535.0f);
    gy_cal = (uint16_t)constrain((gy + 2000.0f) * 65535.0f / 4000.0f, 0.0f, 65535.0f);
    gz_cal = (uint16_t)constrain((gz + 2000.0f) * 65535.0f / 4000.0f, 0.0f, 65535.0f);

    // MUX sensor reads run every sample tick regardless of IMU freshness.
    for (int i = 0; i < NUM_SENSORS; i++) {
      fsrValues[i]  = readMux(i);
      flexValues[i] = readMux(i + 5);
    }

    if (print_mode == 0) buildAndSendFrame();
  }

  if ((print_mode == 1 || print_mode == 2) &&
      (millis() - lastRawPrintMillis >= RAW_PRINT_INTERVAL_MS)) {
    lastRawPrintMillis = millis();

    if (print_mode == 1) {
      for (int i = 0; i < NUM_SENSORS; i++) { Serial.print(flexValues[i]); Serial.print('\t'); }
      for (int i = 0; i < NUM_SENSORS; i++) { Serial.print(fsrValues[i]);  Serial.print('\t'); }
      float qw, qx, qy, qz;
      ahrs.getQuaternion(qw, qx, qy, qz);
      Serial.printf("%.2f\t%.2f\t%.2f\t%.2f\t%.2f\t%.2f\t%.2f\t%.2f\t%.2f\t%.4f\t%.4f\t%.4f\t%.4f\n",
        yaw, pitch, roll, gx, gy, gz, ax, ay, az, qw, qx, qy, qz);
    } else if (print_mode == 2) {
      for (int i = 0; i < NUM_SENSORS; i++) {
        Serial.print(constrain(map(flexValues[i], MIN_FLEX[i], MAX_FLEX[i], 0, 255), 0, 255));
        Serial.print('\t');
      }
      for (int i = 0; i < NUM_SENSORS; i++) {
        Serial.print(constrain(map(fsrValues[i], MIN_PRESS[i], MAX_PRESS[i], 0, 255), 0, 255));
        Serial.print('\t');
      }
      Serial.printf("%u\t%u\t%u\t%u\t%u\t%u\t%u\t%u\t%u\n",
        yaw_cal, pitch_cal, roll_cal, gx_cal, gy_cal, gz_cal, ax_cal, ay_cal, az_cal);
    }
  }

  if (now - lastDisplayMillis >= DISPLAY_INTERVAL_MS) {
    lastDisplayMillis = now;
    updateBatteryStatus();
    updateDisplayDimming();
    updateDisplay();
  }

  diagPrintSysLineIfDue(ahrs, navEkf, write_binary);

  diagLoopTimingEnd();
}

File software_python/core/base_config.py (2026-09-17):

"""
Base configuration for gluvn applications — defaults and common settings.
Adapted for M5Stick C Plus 1.1 + CD74HC4067 multiplexer + built-in IMU (MPU6886).
"""
import json
import os
from copy import deepcopy
from typing import Dict, Any, Optional

# Sensor thresholds/hysteresis: M5Stick 12-bit ADC values (4x the original 10-bit Arduino values)
sensor_defaults = {
    'thresholds': {
        'flex': 800,
        'press': 60,
        'imu': 16384,
    },
    'hysteresis': {
        'flex': 20,
        'press': 20,
        'imu': 500,
    }
}

TWO_BYTE = 65535
BYTE = 255

ADC_MAX = 4095   # M5Stick C Plus 1.1, 12-bit
V_REF = 3.3      # M5Stick C Plus 1.1 operating voltage

ZERO_GYRIN = 0.0   # M5Unified centers gyro at 0.0
ZERO_ACCEL = 0.0   # M5Unified auto-calibrates / 0-centered

MAX_BEND = 8000   # 12-bit scaled

# CD74HC4067 channel mapping, thumb to pinky
MUX_CHANNELS = {
    'flex': [0, 1, 2, 3, 4],
    'press': [5, 6, 7, 8, 9]
}

SCALES = {
    'major': [0, 2, 4, 5, 7, 9, 11],
    'minor': [0, 2, 3, 5, 7, 8, 10],
    'pentatonic': [0, 2, 4, 7, 9],
    'blues': [0, 3, 5, 6, 7, 10],
    'chromatic': [0, 1, 2, 3, 4, 5, 6, 7, 8, 9, 10, 11]
}

# Note name -> MIDI number (C3 = 60)
NOTES = {
    'C': 60, 'C#': 61, 'Db': 61, 'D': 62, 'D#': 63, 'Eb': 63,
    'E': 64, 'F': 65, 'F#': 66, 'Gb': 66, 'G': 67, 'G#': 68,
    'Ab': 68, 'A': 69, 'A#': 70, 'Bb': 70, 'B': 71
}

default_sensor_config = {
    'l': {'flex': True, 'press': True, 'imu': True},
    'r': {'flex': True, 'press': True, 'imu': True}
}

CHORDS = {
    'major': [0, 4, 7],
    'minor': [0, 3, 7],
    'diminished': [0, 3, 6],
    'augmented': [0, 4, 8],
    'sus2': [0, 2, 7],
    'sus4': [0, 5, 7],
    'major7': [0, 4, 7, 11],
    'minor7': [0, 3, 7, 10],
    'dominant7': [0, 4, 7, 10]
}


class BaseConfig:
    def __init__(self):
        self.root_note = 'C'
        self.scale = 'major'
        self.trigger_sensors = {'l': 'flex', 'r': 'flex'}
        # deepcopy: these instance attributes must not alias the shared
        # module-level dicts above, or mutating one BaseConfig's thresholds
        # (e.g. config.thresholds['flex'] = 900) would silently change the
        # default for every other instance and every other config that
        # never explicitly set its own value.
        self.thresholds = deepcopy(sensor_defaults['thresholds'])
        self.hysteresis = deepcopy(sensor_defaults['hysteresis'])
        self.mod_sensors = {'r': [None], 'l': [None]}
        self.mod_idx = {'r': [None], 'l': [None]}
        self.hands = ['l', 'r']
        self.sensor_config = deepcopy(default_sensor_config)

        self.mcu_target = "M5Stick_C_Plus_1.1"
        self.adc_resolution = 12
        self.imu_source = "Internal_M5Unified"
        self.mux_enabled = True

    def to_file(self, config_path: str) -> Dict[str, Any]:
        """Save configuration to a JSON file."""
        os.makedirs(os.path.dirname(os.path.abspath(config_path)), exist_ok=True)

        config_dict = {k: v for k, v in self.__dict__.items() if not k.startswith('_')}

        with open(config_path, 'w') as f:
            json.dump(config_dict, f, indent=4)

        return config_dict

    @classmethod
    def from_file(cls, config_path: str) -> 'BaseConfig':
        """Load configuration from a JSON file."""
        config = cls()

        with open(config_path, 'r') as f:
            config_dict = json.load(f)

        for key, value in config_dict.items():
            if hasattr(config, key):
                setattr(config, key, value)

        return config

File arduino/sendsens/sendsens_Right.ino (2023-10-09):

#include "I2Cdev.h"
#include  <SoftwareSerial.h>
#include "freeram.h"
#include "mpu.h"
#include "inv_mpu.h"
#include "math.h"
#include "calibration.h"


#define NUM_SENSORS 5

int ret;

char* hand = "L";
int use_gyro = false;
bool write_serial = true; 
bool calibration_mode = false; // only works if write_serial
int print_mode = 0;
const long interval = 5;  // Interval at which to read sensors and send data (milliseconds)

int gyro_max = 2000; // Range is +/- 2000 deg/s by default 
int accel_max = 32767.0; // Range is +/- 2g by default

int prespin[] = {0, 1, 2, 3, 4};
int flpin[] = {5, 8, 9, 10, 11};

uint16_t flexValues[5];
uint16_t pressValues[5];
int gx, gy, gz, roll, pitch, yaw, ax, ay, az;
uint16_t gx_cal, gy_cal, gz_cal, roll_cal, pitch_cal, yaw_cal, ax_cal, ay_cal, az_cal;

unsigned long previousMillis = 0;

// print_mode = 0 -> doesn't print
// print_mode = 1 -> prints raw values
// print_mode = 2 -> prints calibrated values


const int* MIN_FLEX;
const int* MAX_FLEX;
const int* MIN_PRESS;
const int* MAX_PRESS;


// #define LED_PIN 13
void setup() {

        Fastwire::setup(400, true);
        ret = mympu_open(200);
        Serial.begin(115200);
        // pinMode(LED_PIN, OUTPUT);

        if(hand == "R"){
          MIN_FLEX = R_MIN_FLEX;
          MAX_FLEX = R_MAX_FLEX;
          MIN_PRESS = R_MIN_PRESS;
          MAX_PRESS = R_MAX_PRESS;
        } else if(hand == "L") {
          MIN_FLEX = L_MIN_FLEX;
          MAX_FLEX = L_MAX_FLEX;
          MIN_PRESS = L_MIN_PRESS;
          MAX_PRESS = L_MAX_PRESS;
        }

        unsigned short gyro_fsr;
        unsigned char accel_fsr;
        mpu_get_gyro_fsr(&gyro_fsr);
        mpu_get_accel_fsr(&accel_fsr);

}


//////////////////////////////

void loop() {


    unsigned long currentMillis = millis();
    
    if (currentMillis - previousMillis >= interval) {
      previousMillis = currentMillis;

      ret = mympu_update();
      // TODO: add error handling, check ret.
      

      // Read values
      for (int i = 0; i < 5; i++) {
          flexValues[i] = analogRead(flpin[i]);
          pressValues[i] = analogRead(prespin[i]);
      }
      yaw = mympu.ypr[0];
      pitch = mympu.ypr[1];
      roll = mympu.ypr[2];
      gx = mympu.gyro[0];
      gy = mympu.gyro[1];
      gz = mympu.gyro[2];
      ax = mympu.accel[0];
      ay = mympu.accel[1];
      az = mympu.accel[2];

      yaw_cal = (uint16_t)((yaw+180.0) * 32767.0/180.0);
      pitch_cal = (uint16_t)((pitch+90.0) * 32767.0/90.0);
      roll_cal = (uint16_t)((roll+180.0) * 32767.0/180.0);

      gx_cal = (uint16_t)(constrain( (gx+gyro_max) * 32767.0/gyro_max, 0, 65535.0 ) );
      gy_cal = (uint16_t)(constrain( (gy+gyro_max) * 32767.0/gyro_max, 0, 65535.0 ) );
      gz_cal = (uint16_t)(constrain( (gz+gyro_max) * 32767.0/gyro_max, 0, 65535.0 ) );
      ax_cal = (uint16_t)( (ax+accel_max)  ); // Assumes accel_max = 32767.0;
      ay_cal = (uint16_t)( (ay+accel_max)  );
      az_cal = (uint16_t)( (az+accel_max)  );
    

      if(write_serial) {

        Serial.write("w");

      // Write to serial
        Serial.write((uint8_t)(yaw_cal >> 8)); Serial.write((uint8_t)(yaw_cal & 255));
        Serial.write((uint8_t)(pitch_cal >> 8)); Serial.write((uint8_t)(pitch_cal & 255));
        Serial.write((uint8_t)(roll_cal >> 8)); Serial.write((uint8_t)(roll_cal & 255));

        if(use_gyro){
          Serial.write((uint8_t)(gx_cal >> 8)); Serial.write((uint8_t)(gx_cal & 255));
          Serial.write((uint8_t)(gy_cal >> 8)); Serial.write((uint8_t)(gy_cal & 255));
          Serial.write((uint8_t)(gz_cal >> 8)); Serial.write((uint8_t)(gz_cal & 255));
        } else {
          Serial.write((uint8_t)(ax_cal >> 8)); Serial.write((uint8_t)(ax_cal & 255));
          Serial.write((uint8_t)(ay_cal >> 8)); Serial.write((uint8_t)(ay_cal & 255));
          Serial.write((uint8_t)(az_cal >> 8)); Serial.write((uint8_t)(az_cal & 255));
        }


        if(!calibration_mode){
          // Send calibrated pressue and flex sensors
          for(int i = 0; i<NUM_SENSORS; i++){
            Serial.write((uint8_t)(constrain(map(flexValues[i], MIN_FLEX[i], MAX_FLEX[i], 0, 255), 0, 255)));
          }
          for(int i = 0; i<NUM_SENSORS; i++){
            Serial.write((uint8_t)(constrain(map(pressValues[i], MIN_PRESS[i], MAX_PRESS[i], 0, 255), 0, 255)));
          }

        } else {
          
          // Send un-calibrated pressure and flex sensors
          for(int i = 0; i<NUM_SENSORS; i++){
            Serial.write((uint8_t)(flexValues[i] >> 8)); 
            Serial.write((uint8_t)(flexValues[i] & 225));
          }
          for(int i = 0; i<NUM_SENSORS; i++){
            Serial.write((uint8_t)(pressValues[i] >> 8)); 
            Serial.write((uint8_t)(pressValues[i] & 225));
          }

        }

        Serial.write("\n");

      }


      // PRINTING
      if(print_mode>0){
        if(print_mode==1){

        // FLEX
        for(int i = 0; i<NUM_SENSORS; i++){
          Serial.print(flexValues[i]); Serial.print("\t");
        }

        // PRESS
        for(int i = 0; i<NUM_SENSORS; i++){
          Serial.print(pressValues[i]); Serial.print("\t");
        }

        // Pitch Roll Yaw
        Serial.print(yaw); Serial.print("\t");
        Serial.print(roll); Serial.print("\t");
        Serial.print(pitch); Serial.print("\t");
        // GYRO
        Serial.print(gx); Serial.print("\t");
        Serial.print(gy); Serial.print("\t");
        Serial.print(gz); Serial.print("\t");
        // ACCELEROMETER
        Serial.print(ax); Serial.print("\t");
        Serial.print(ay); Serial.print("\t");
        Serial.print(az); Serial.print("\t");

        Serial.print("\n");

      } else if(print_mode==2) {

          for(int i = 0; i<NUM_SENSORS; i++){
            Serial.print(constrain(map(flexValues[i], MIN_FLEX[i], MAX_FLEX[i], 0, 255), 0, 255));
            Serial.print("\t");
          }
          for(int i = 0; i<NUM_SENSORS; i++){
            Serial.print(constrain(map(pressValues[i], MIN_PRESS[i], MAX_PRESS[i], 0, 255), 0, 255));
            Serial.print("\t");
          }

          // Pitch Roll Yaw
          Serial.print(yaw_cal); Serial.print("\t");
          Serial.print(roll_cal); Serial.print("\t");
          Serial.print(pitch_cal); Serial.print("\t");
          // GYRO
          Serial.print(gx_cal); Serial.print("\t");
          Serial.print(gy_cal); Serial.print("\t");
          Serial.print(gz_cal); Serial.print("\t");
          // ACCELEROMETER
          Serial.print(ax_cal); Serial.print("\t");
          Serial.print(ay_cal); Serial.print("\t");
          Serial.print(az_cal); Serial.print("\t");

          Serial.print("\n");
      }
      }
    }

  }

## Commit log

2020-02-19 pre-new commit
    [note2num.csv, rnd_glove_ypr.csv, rnd_glove_ypr_chords.csv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]
2023-10-09 major updates, calibration, cleaning, pre-demo
    [test0_8_sensorsR.csv]
2023-10-09 removed ds_store files and readme.txt
    [test0_8_sensorsR.csv]
2023-10-23 restructuring, added new senstonote classes, moving-window works
    [test00_0_sensors_l.csv, test00_0_sensors_r.csv, test0_0_sensorsL.csv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]
2023-10-31 accelerometer volume implementation, merger_test, needs cleaning
2026-09-17 refactor: complete new wireless version architecture overhaul
    [bach1_0_keyboard.csv, bach1_0_noteandfinger.csv, bach1_0_noteandfinger_andflex_noteinc.csv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]
2026-09-17 Add piano keyboard widget and sensor processing threads for GLUVN
    - Implemented a PianoKeyboard widget that displays a piano keyboard covering the range C1-C6 with visual feedback for triggered notes.
    - Created a CompactPianoKeyboard for tighter layouts with smaller keys.
    - Developed SensorProcessingThread for real-time sensor data processing, integrating with GLUVN trigger strategies and modulation control.
    - Added signal emissions for sensor updates, modulation updates, and error handling in sensor processing.
    - Included methods for updating thresholds and hysteresis in trigger strategies, as well as adding/removing modulation strategies at runtime.
    [Diagnostics.h, MahonyAHRS.h, NavEKF.h]
2026-09-21 Correct battery capacity for M5Stick C Plus
2026-09-22 Enhance digital twin functionality with yaw sector display and mounting adjustments
    - Introduced a new `SectorBar` class for visualizing yaw sectors and notes being played.
    - Updated `HandState` to include mounting configuration and mesh rotation based on sensor mounting.
    - Modified `update_kinematics` to accept mounting type and adjust mesh rotation accordingly.
    - Enhanced `TelemetryPanel` to display currently playing notes persistently.
    - Adjusted `TwinWindow` to integrate the new sector bar and ensure proper data flow for notes and yaw sectors.
    - Improved handling of position trustworthiness and alignment for trail visualization.
    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
2026-09-23 Refactor hand diagnostics and sensor mounting logic; improve digital twin UI elements
2026-09-23 Refactor pitch step logic and update digital twin UI for improved clarity and functionality
2026-09-23 Refactor arm orientation naming and update telemetry display for clarity
2026-09-24 Refactor gyro bias handling and improve display updates for clarity
2026-10-01 Squashed 'hardware/' content from commit d388573
    git-subtree-dir: hardware
    git-subtree-split: d38857381ccfd8dd85d458df5baee66a4dd7fd2a
    [3D_PCB.f3d, Electronics Design.f3z, Enclosure.3mf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]
2026-10-01 Add README for GLUVN hardware project
    Added detailed README for GLUVN hardware including features, architecture, sensor configuration, and assembly instructions.
2026-10-14 Add camera latency calibration and stability analysis tools
    - Implement `sync_session.py` for dedicated camera-latency calibration sessions, allowing measurement of camera stamp to device clock offsets using LED bursts.
    - Introduce `sync_stability.py` to evaluate the stability of camera latency across multiple sessions, providing insights on whether the calibration can be reused.
    - Create `sync_tools.py` containing various utilities for mapping camera time to device clock using firmware LED events, including functions for edge detection, fitting, and live logging.
2026-11-11 Add capture metadata validation and USB backend for Windows
    - Implement strict checks for main-profile metadata in `capture_metadata.py`, including configuration hash verification and detailed error reporting for metadata integrity.
    - Introduce a new capture framework in `capture_v2.py` that supports opt-in research framing, bounded queues, and readiness checks without hardware dependencies.
    - Create a Windows-specific USB backend in `research_usb.py` to maintain PySerial read semantics and report driver errors accurately.
